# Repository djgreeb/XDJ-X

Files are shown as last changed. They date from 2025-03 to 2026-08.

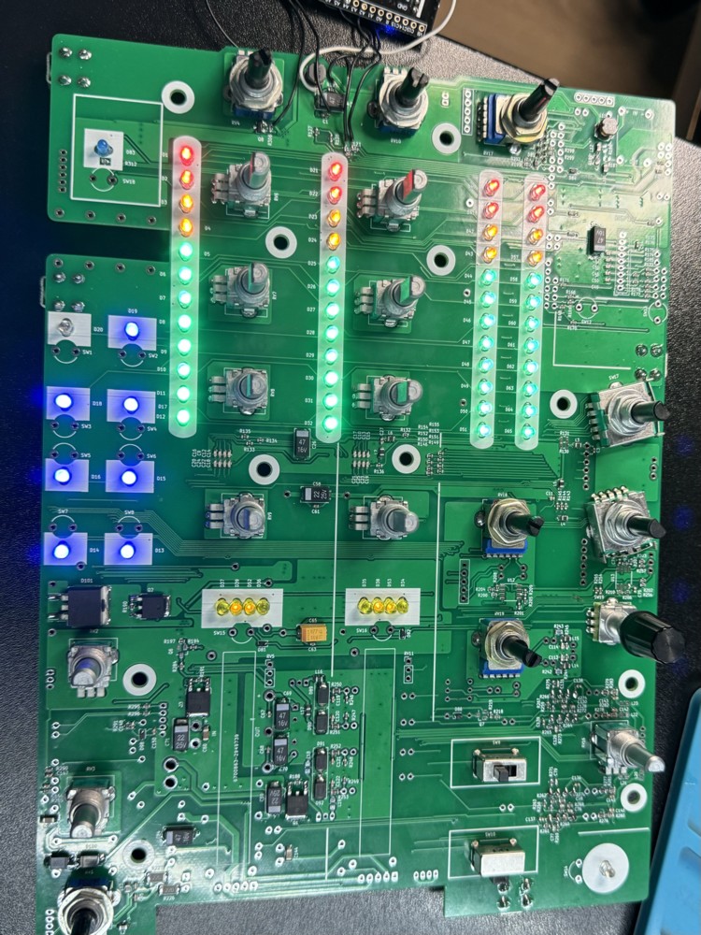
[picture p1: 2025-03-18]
Photo/39.jpg

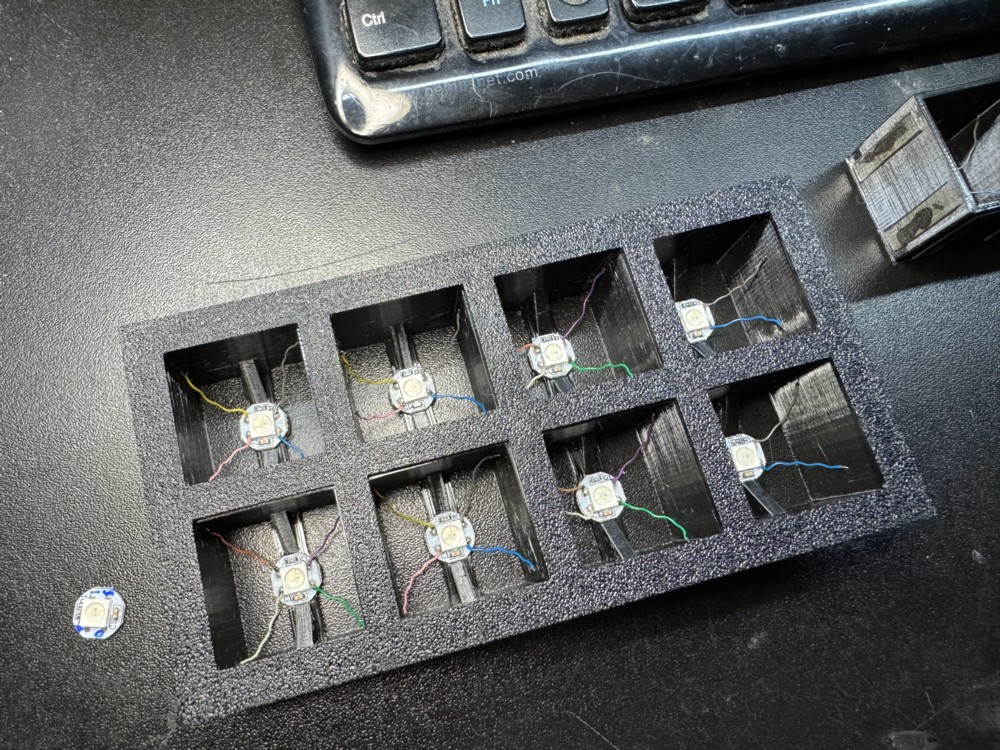
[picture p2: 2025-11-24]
Photo/47.jpg

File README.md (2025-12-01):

# XDJ-X
 All-in-one Dj System

The XDJ-X is an standalone all-in-one DJ system built on the body parts of the CDJ-1000mk3, such as the jog wheel, buttons, and pitch.

The main goal was to create a 2-channel dj setup, compact, without major compromises. Have full-fledged jog wheels, pads, a mixer layer the same as the DJM-900nxs, with an effects display imitating the vacuum display of the classic DJM.

Displays in jogs are specially selected classic VFD, not TFT. These displays have a higher response speed, requiring fewer resources. And this is their main task, when scratching.

The XDJ-X has such advantages as an optical crossfader, a Bluetooth transmitter capable of transmitting a master bus signal or a CUE bus. A built-in battery, the ability to charge the device from a socket or in a car. Built-in speakers (from a MacBook Pro). Support for Rekordbox playlists, wav 16 bits, 44.1 kHz audio files on SD card.

And the most important advantage for me: my source code, scheme, printed circuit board. This will allow adding and testing ideas, algorithms of effects, gui, which in the future will be presented in new models of dj equipment from large companies.

XDJX

xdj-x3



Jog ring

xdj-x 3d

OVERALL BLOCK DIAGRAM

OVERALL BLOCK DIAGRAM

XDJ-X is based on 2 STM32H7 series ARMs, which handle the mixer and deck audio parts. Two STM32F446RET6 microcontrollers handle the buttons and jog wheels in the decks. And STM32G431CBU6 microcontroller handles power, battery charge and standby.

Some videos:

https://youtube.com/shorts/dMu84rqdVfA?si=jUdEivFD7gFBzyvY

https://youtube.com/shorts/kgtJnk3ONWc?si=wLm2IKEQJ5OtroMM

https://youtube.com/shorts/DCkOMFqDp7Y?si=G3mvCeku2s3VxJYp

https://youtube.com/shorts/irT8oiYcfQY?si=mGk5z3SIEAtcrn9f

https://youtube.com/shorts/_BytWdkR8dk?si=etdZMhdHCcjLXZf_

https://youtube.com/shorts/ZKBDyeK_nx4?si=UcPv7-aijNNnzk9v

https://youtube.com/shorts/46_N7XZ1OTQ?si=X-IEIPI7V7By5p8N

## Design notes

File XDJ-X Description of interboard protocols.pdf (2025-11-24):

# XDJ-X

# All-in-one DJ system

# Exchange protocol

# Service commands

Assembly name: | Firmware version:
Display module | 1.06
Mixer assy | 0.42
Deck assy | 0.29
Power manager | 0.27

## Last modified date:

05.06.2025

# Content

1. Exchange protocols | 3
2. Service commands | 5
3. Utility list | 7

# General connection diagram exchange date:

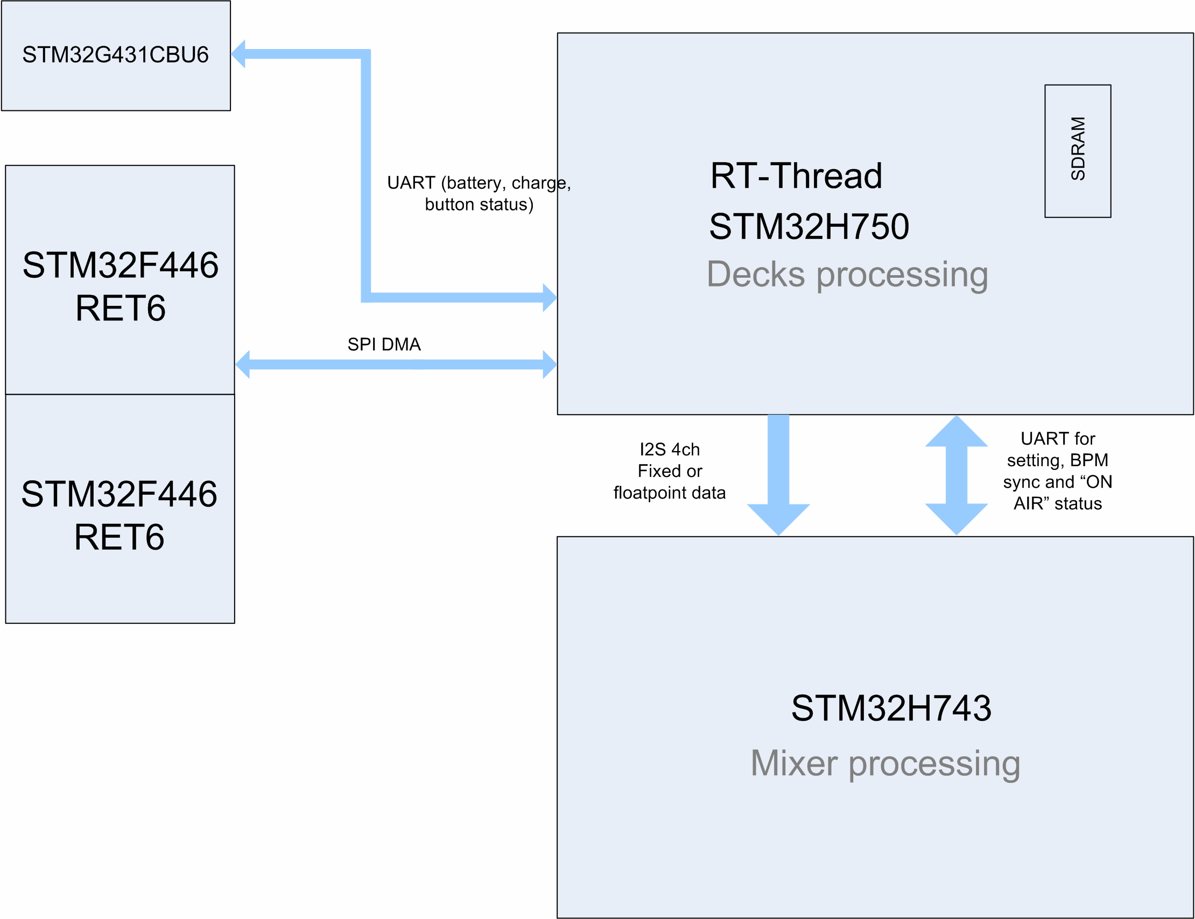
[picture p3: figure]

# 1. Exchange protocols

# Display module <=> Power manager

UART transfer 256000 baud.

## Power manager => Display module:

| 0 | 1 | 2 | 3 | 4 | 5 | 6 | 7 | 8 | 9 | A | B | C | D | E | F
Bytes | 0xAX | | | | | | | | 0xXX
Bits | 1 | 0 | 1 | 0 | 0 | 0 | X | X | X | X | X | X | X | X | X | X

## Byte[0] - status:

## [0xA1] - no AC

## [0xA2] - AC charge

## [0xA3] - full battery

## Byte[1] - data:

## [0xAX][0...100] - charge precentage (when the value changes or on request)

## [0xAX][0xFE] - button pressed

## [0xAX][0xFD] - button unpressed

## [0xAX][0xFC] - shutdown command

## [0xAX][1xxxxxxx] – firmware version

## Display module => Power manager:

| 0 | 1 | 2 | 3 | 4 | 5 | 6 | 7 | 8 | 9 | A | B | C | D | E | F
Bytes | 0xA1 | | | | | | | | 0xXX
Bits | 1 | 0 | 1 | 0 | 0 | 0 | 0 | 1 | X | X | X | X | X | X | X | X

## [0xA1][0x01] - firmware version request

## [0xA1][0x55] - battery percentage request

## [0xA1][0xFC] - shutdown permission

# Display module <=> Mixer Assy

UART transfer 500000 baud.

## Display module => Mixer Assy:

| 0 | 1 | 2 | 3 | 4 | 5 | 6 | 7 | 8 | 9 | A | B | C | D | E | F
Bytes | 0x9X | | | | | | | | 0xXX
Bits | 1 | 0 | 0 | 1 | X | X | X | X | X | X | X | X | X | X | X | X
| 10 | 11 | 12 | 13 | 14 | 15 | 16 | 17
Bytes | 0xXX
Bits | X | X | X | X | X | X | X | X

## [0x91][0x60][0x31] - firmware version request

## [0x92][LOW-MID][MID-HIGH] - setting table values of equalizer cutoff frequencies

## [0x93][0xB1][FDR] - setting fader curve type

## [0x94][0xA3][HDPH] - setting headphones cue type (pre EQ or post EQ)

## [0x95-0x96][BPM][BPM] - sending bpm at beats (BPM*100), 0x95-0x96 – first beat 1/4

## [0x97][0xFC][0xFC] - shutdown command

## Mixer Assy => Display module:

| 0 | 1 | 2 | 3 | 4 | 5 | 6 | 7 | 8 | 9 | A | B | C | D | E | F
Bytes | 0x9X | | | | | | | | 0xXX
Bits | 1 | 0 | 0 | 1 | X | X | X | X | X | X | X | X | X | X | X | X
| 10 | 11 | 12 | 13 | 14 | 15 | 16 | 17
Bytes | 0xXX
Bits | X | X | X | X | X | X | X | X

## [0x91][FW][FW] - firmware version (FW*100)

## [0x97][DECKA][ [DECKB] – on air status

# Display module <=> Deck assy

# SPI DMA transfer

## Deck assy => Display module:

| 00 | 01 | 02 | 03 | 04 | 05 | 06 | 07 | 08 | 09 | 0A | 0B | 0C | 0D | 0E | 0F
Bytes | PADS | | | | | | | | BUTTONS
Bits | PD7 | PD6 | PD5 | PD4 | PD3 | PD2 | PD1 | PD0 | RLP | LP8 | LP4 | VNL | SLIP | REV | CUE | PLAY
| 10 | 11 | 12 | 13 | 14 | 15 | 16 | 17 | 18 | 19 | 1A | 1B | 1C | 1D | 1E | 1F
Bytes | BUTTONS | | | | | | ADC_PITCH (10 bits)
Bits | JSNS | TMP | NXT | PREV | RD | 0 | P | P | P | P | P | P | P | P | P | P
| 20 | 21 | 22 | 23 | 24 | 25 | 26 | 27 | 28 | 29 | 2A | 2B | 2C | 2D | 2E | 2F
Bytes | | | | | | | | | JOG_SPEED_MSB
Bits | DIR | FW | FW | FW | FW | FW | FW | FW | X | X | X | X | X | X | X | X
| 30 | 31 | 32 | 33 | 34 | 35 | 36 | 37 | 38 | 39 | 3A | 3B | 3C | 3D | 3E | 3F
Bytes | JOG_SPEED_LSB | | | | | | | | CRC
Bits | X | X | X | X | X | X | X | X | X | X | X | X | X | X | X | X

## ADC_PITCH 0…1023, 512 – center zone

## RD – rotation detect

## DIR - jog wheel rotation direction

## FW – firmware version in code (0-127)

## JOG_SPEED 0…65535 16 bits resolution (when jog stopped speed = 0xFFFF)

## CRC = (0byte + 1byte +…+6byte)%256

## Display module => Deck assy:

| 00 | 01 | 02 | 03 | 04 | 05 | 06 | 07 | 08 | 09 | 0A | 0B | 0C | 0D | 0E | 0F
Bytes | NUM_P | | | | | | | | PADn_RED
Bits | RNGr | RNGg | RNGb | LD1 | LD0 | nP | nP | nP | R | R | R | R | R | R | R | R
| 10 | 11 | 12 | 13 | 14 | 15 | 16 | 17 | 18 | 19 | 1A | 1B | 1C | 1D | 1E | 1F
Bytes | PADn_GREEN | | | | | | | | PADn_BLUE
Bits | G | G | G | G | G | G | G | G | B | B | B | B | B | B | B | B
| 20 | 21 | 22 | 23 | 24 | 25 | 26 | 27 | 28 | 29 | 2A | 2B | 2C | 2D | 2E | 2F
Bytes | PLAY_POS | | | | | | | | SLIP_POS
Bits | X | X | X | X | X | X | X | X | 0 | X | X | X | X | X | X | X
| 30 | 31 | 32 | 33 | 34 | 35 | 36 | 37 | 38 | 39 | 3A | 3B | 3C | 3D | 3E | 3F
Bytes | CUE_POS | | | | | | | | CRC
Bits | 0 | X | X | X | X | X | X | X | X | X | X | X | X | X | X | X
nP | LD1 | LD0
0 | CUE | PLAY
1 | SLIP | REV
2 | LP4 | VNL
3 | RLP | LP8
4 | TMP | VNLr

5 | SNSr | MEMr
6 | 0 | 0
7 | 0 | 0

## nP - package number and at the same time pad number PADn_(RED, GREEN, BLUE) RGB 888 color for PAD[NUM_P] RNGr, RNGg, RNGb – RGB bits <<[NUM_P] MEMr, SNSr, VNLr – VFD segments SLIP_POS 0…84. 85 – SLIP disable CUE_POS 0…84. 85 – CUE without cue on jog display

PLAY_POS 0…134 – jog display position cursor 139 = power on animation 138 = eject animation 137 = load in animation 136 = fill circle on display 135 = empty circle.

## CRC = (0byte + 1byte +…+6byte)%256

# 2. Service commands

# 3. Utility list

Name: | Array location | EEPROM addr | Parameter list
DECKS
PLAY MODE | [0] | 0x0000 | SINGLE
CONTINUE
LOAD LOCK | [1] | 0x0001 | LOCK
| | | UNLOCK
| | | -36dB
| | | -42dB
| | | -48dB
| | | -54dB
| | | -60dB
| | | -66dB
| | | -72dB
| | | -78dB
| | | MEMORY
AUTO CUE MODE | [2] | 0x0002

FIRST BEAT
QUANTIZE | [3] | 0x0003 | OFF
| | | ON
| | | 6%
| | | 10%
| | | 16%
TEMPO RANGE DEFAULT | [4] | 0x0004

WIDE
COLOR WAVEFORM | [5] | 0x0005 | BLUE
| | | RGB
WAVEFORM POSITION | [6] | 0x0006 | CENTER LINE
| | | LEFT LINE
VINYL START | [7] | 0x0007 | 0-128
VINYL BRAKE | [8] | 0x0008 | 0-128
JOG ON AIR | [9] | 0x0009 | OFF
ON
WHITE
PINK
RED
JOG COLOR ON AIR | [10] | 0x000A

ORANGE

YELLOW
GREEN
AQUA
BLUE
PURPLE
TRACK COLOR
WHITE
PINK
RED
ORANGE
YELLOW
GREEN
AQUA
BLUE
PURPLE
JOG COLOR INACTIVE | [11] | 0x000B

TRACK COLOR
JOG BRIGHTNESS | [12] | 0x000C | 1
| | | 2
| | | 1
| | | 2
| | | 3
| | | 4
LCD BRIGHTNESS | [13] | 0x000D

5
PADS MODE | [14] | 0x000E | NORMAL
| | | GATE

MIXER
FADER CURVE | [15] | 0x000F | LINEAR
SLOW
SPEAKERS | - | OFF
| | ON
EQ frequency LOW-MID | [16] | 0x0010
EQ frequency MID -HIGH | [17] | 0x0011
HEADPHONES CUE | [18] | 0x0012 | PRE EQ
POST EQ

GENERAL
BATT. INFO | -

VERSION No.
DECK 1 | - | 0.29
DECK 2 | - | 0.29
MAIN ASSY | - | 1.03

MIXER ASSY | | 0.41
POWER MANAGER | - | 0.27
DEVELOPER | - | ANATSKA ANDREI

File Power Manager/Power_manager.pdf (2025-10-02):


03/06/2025

Power_manager Project
Configuration Report

## 1. Description

### 1.1. Project

Project Name | Power_manager
Board Name | custom
Generated with: | STM32CubeMX 6.10.0
Date | 06/03/2025

### 1.2. MCU

MCU Series | STM32G4
MCU Line | STM32G4x1
MCU name | STM32G431CBUx
MCU Package | UFQFPN48
MCU Pin number | 48

### 1.3. Core(s) information

Core(s) | ARM Cortex-M4

## 2. Pinout Configuration

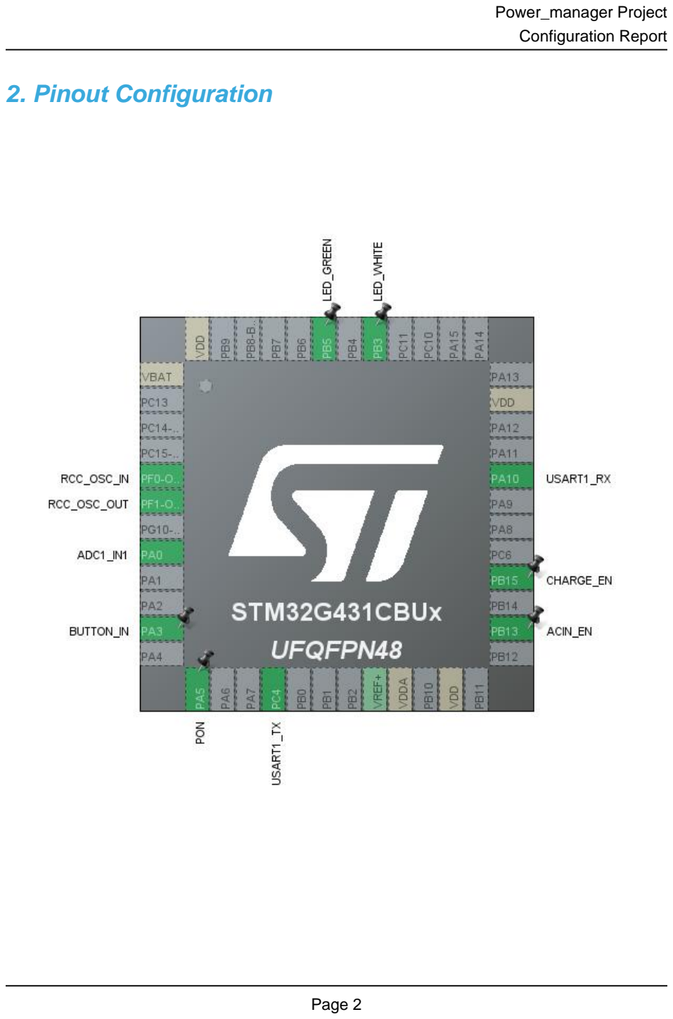
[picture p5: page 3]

## 3. Pins Configuration

Pin Number UFQFPN48 | Pin Name (function after reset) | Pin Type | Alternate Function(s) | Label
1 | VBAT | Power
5 | PF0-OSC_IN | I/O | RCC_OSC_IN
6 | PF1-OSC_OUT | I/O | RCC_OSC_OUT
8 | PA0 | I/O | ADC1_IN1
11 | PA3 * | I/O | GPIO_Input | BUTTON_IN
13 | PA5 * | I/O | GPIO_Output | PON
16 | PC4 | I/O | USART1_TX
21 | VDDA | Power
23 | VDD | Power
26 | PB13 * | I/O | GPIO_Input | ACIN_EN
28 | PB15 * | I/O | GPIO_Input | CHARGE_EN
32 | PA10 | I/O | USART1_RX
35 | VDD | Power
41 | PB3 * | I/O | GPIO_Output | LED_WHITE
43 | PB5 * | I/O | GPIO_Output | LED_GREEN
48 | VDD | Power

* The pin is affected with an I/O function

## 4. Clock Tree Configuration

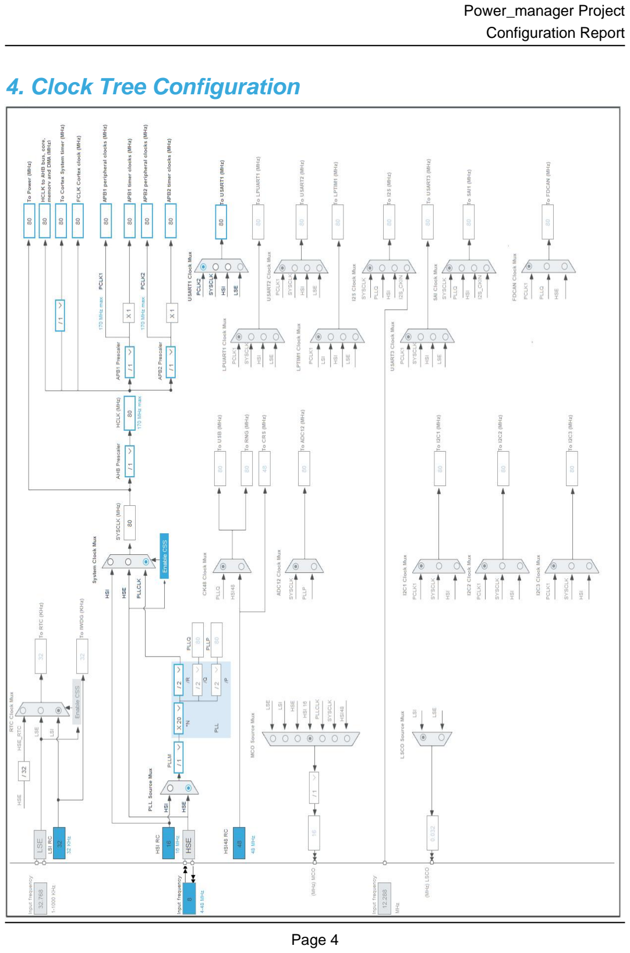
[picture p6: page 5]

## 5. Software Project

### 5.1. Project Settings

Name | Value
Project Name | Power_manager
Project Folder | C:\Keil_v5\My_Project\Power_manager
Toolchain / IDE | MDK-ARM V5.32
Firmware Package Name and Version | STM32Cube FW_G4 V1.5.1
Application Structure | Basic
Generate Under Root | No
Do not generate the main() | No
Minimum Heap Size | 0x200
Minimum Stack Size | 0x400

### 5.2. Code Generation Settings

Name | Value
STM32Cube MCU packages and embedded software | Copy all used libraries into the project folder
Generate peripheral initialization as a pair of '.c/.h' files | Yes
Backup previously generated files when re-generating | No
Keep User Code when re-generating | Yes
Delete previously generated files when not re-generated | Yes
Set all free pins as analog (to optimize the power consumption) | No
Enable Full Assert | No

### 5.3. Advanced Settings - Generated Function Calls

Rank | Function Name | Peripheral Instance Name
1 | SystemClock_Config | RCC
2 | MX_GPIO_Init | GPIO
3 | MX_ADC1_Init | ADC1
4 | MX_USART1_UART_Init | USART1

## 1. Power Consumption Calculator report

### 1.1. Microcontroller Selection

Series | STM32G4
Line | STM32G4x1
MCU | STM32G431CBUx
Datasheet | DS12589_Rev0

### 1.2. Parameter Selection

Temperature | 25
Vdd | 3.0

### 1.3. Battery Selection

Battery | Li-SOCL2(A3400)
Capacity | 3400.0 mAh
Self Discharge | 0.08 %/month
Nominal Voltage | 3.6 V
Max Cont Current | 100.0 mA
Max Pulse Current | 200.0 mA
Cells in series | 1
Cells in parallel | 1

### 1.4. Sequence

Step | Step1 | Step2
Mode | RUN | STOP1
Vdd | 3.0 | 3.0
Voltage Source | Battery | Battery
Range | Range1-Boost | NoRange
Fetch Type | FLASH/ART | NA
CPU Frequency | 170 MHz | 0 Hz
Clock Configuration | HSE BYP PLL | ALL CLOCKS OFF
Clock Source Frequency | 4 MHz | 0 Hz
Peripherals
Additional Cons. | 0 mA | 0 mA
Average Current | 25.5 mA | 59 µA
Duration | 0.1 ms | 0.9 ms
DMIPS | 213.0 | 0.0
Ta Max | 127.71 | 129.99
Category | In DS Table | In DS Table

### 1.5. Results

Sequence Time | 1 ms | Average Current | 2.6 mA
Battery Life | 1 month, 23 days, 22 hours | Average DMIPS | 212.5 DMIPS

### 1.6. Chart

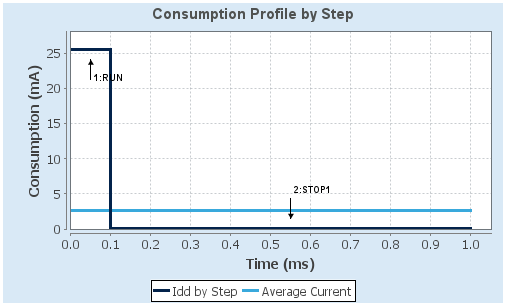
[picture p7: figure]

## 2. Peripherals and Middlewares Configuration

### 2.1. ADC1

IN1: IN1 Single-ended
2.1.1. Parameter Settings:

ADCs_Common_Settings:

Mode | Independent mode
ADC_Settings:
Clock Prescaler | Synchronous clock mode divided by 2
Resolution | ADC 12-bit resolution
Data Alignment | Right alignment
Gain Compensation | 0
Scan Conversion Mode | Disabled
End Of Conversion Selection | End of single conversion
Low Power Auto Wait | Disabled
Continuous Conversion Mode | Disabled
Discontinuous Conversion Mode | Disabled
DMA Continuous Requests | Disabled
Overrun behaviour | Overrun data preserved
ADC_Regular_ConversionMode:
Enable Regular Conversions | Enable
Enable Regular Oversampling | Disable
Number Of Conversion | 1
External Trigger Conversion Source | Regular Conversion launched by software
External Trigger Conversion Edge | None
Rank | 1
Channel | Channel 1
Sampling Time | 2.5 Cycles
Offset Number | No offset
ADC_Injected_ConversionMode:
Enable Injected Conversions | Disable
Analog Watchdog 1:
Enable Analog WatchDog1 Mode | false
Analog Watchdog 2:
Enable Analog WatchDog2 Mode | false
Analog Watchdog 3:
Enable Analog WatchDog3 Mode | false

### 2.2. RCC

High Speed Clock (HSE): Crystal/Ceramic Resonator
2.2.1. Parameter Settings:

System Parameters:

VDD voltage (V) | 3.3
Instruction Cache | Enabled
Prefetch Buffer | Disabled
Data Cache | Enabled
Flash Latency(WS) | 2 WS (3 CPU cycle)
RCC Parameters:
HSI Calibration Value | 64
HSE Startup Timout Value (ms) | 100
LSE Startup Timout Value (ms) | 5000
Power Parameters:
Power Regulator Voltage Scale | Power Regulator Voltage Scale 1
Peripherals Clock Configuration:
Generate the peripherals clock configuration | TRUE

### 2.3. SYS

Timebase Source: SysTick
mode: save power of non-active UCPD - deactive Dead Battery pull-up

### 2.4. USART1

Mode: Asynchronous
2.4.1. Parameter Settings:

Basic Parameters:

Baud Rate | 256000 *
Word Length | 8 Bits (including Parity)
Parity | None
Stop Bits | 1
Advanced Parameters:
Data Direction | Receive and Transmit
Over Sampling | 16 Samples
Single Sample | Disable
ClockPrescaler | 1

Fifo Mode | Disable
Txfifo Threshold | 1 eighth full configuration
Rxfifo Threshold | 1 eighth full configuration
Advanced Features:
Auto Baudrate | Disable
TX Pin Active Level Inversion | Disable
RX Pin Active Level Inversion | Disable
Data Inversion | Disable
TX and RX Pins Swapping | Disable
Overrun | Enable
DMA on RX Error | Enable
MSB First | Disable

* User modified value

## 3. System Configuration

### 3.1. GPIO configuration

IP | Pin | Signal | GPIO mode | GPIO pull/up pull down | Max Speed | User Label
ADC1 | PA0 | ADC1_IN1 | Analog mode | No pull-up and no pull-down | n/a
RCC | PF0-OSC_IN | RCC_OSC_IN | n/a | n/a | n/a
| PF1-OSC_OUT | RCC_OSC_OUT | n/a | n/a | n/a
USART1 | PC4 | USART1_TX | Alternate Function Push Pull | No pull-up and no pull-down | Low
| PA10 | USART1_RX | Alternate Function Push Pull | No pull-up and no pull-down | Low
GPIO | PA3 | GPIO_Input | Input mode | Pull-up * | n/a | BUTTON_IN
| PA5 | GPIO_Output | Output Push Pull | No pull-up and no pull-down | Medium * | PON
| PB13 | GPIO_Input | Input mode | No pull-up and no pull-down | n/a | ACIN_EN
| PB15 | GPIO_Input | Input mode | No pull-up and no pull-down | n/a | CHARGE_EN
| PB3 | GPIO_Output | Output Push Pull | No pull-up and no pull-down | High * | LED_WHITE
| PB5 | GPIO_Output | Output Push Pull | No pull-up and no pull-down | High * | LED_GREEN

### 3.2. DMA configuration

nothing configured in DMA service

### 3.3. NVIC configuration

3.3.1. NVIC
Interrupt Table | Enable | Preenmption Priority | SubPriority
Non maskable interrupt | true | 0 | 0
Hard fault interrupt | true | 0 | 0
Memory management fault | true | 0 | 0
Prefetch fault, memory access fault | true | 0 | 0
Undefined instruction or illegal state | true | 0 | 0
System service call via SWI instruction | true | 0 | 0
Debug monitor | true | 0 | 0
Pendable request for system service | true | 0 | 0
System tick timer | true | 15 | 0
USART1 global interrupt / USART1 wake-up interrupt through EXTI line 25 | true | 1 | 0
PVD/PVM1/PVM2/PVM3/PVM4 interrupts through EXTI lines 16/38/39/40/41 | unused
Flash global interrupt | unused
RCC global interrupt | unused
ADC1 and ADC2 global interrupt | unused
FPU global interrupt | unused
3.3.2. NVIC Code generation
Enabled interrupt Table | Select for init sequence ordering | Generate IRQ handler | Call HAL handler
Non maskable interrupt | false | true | false
Hard fault interrupt | false | true | false
Memory management fault | false | true | false
Prefetch fault, memory access fault | false | true | false
Undefined instruction or illegal state | false | true | false
System service call via SWI instruction | false | true | false
Debug monitor | false | true | false
Pendable request for system service | false | true | false
System tick timer | false | true | true
USART1 global interrupt / USART1 wake-up interrupt through EXTI line 25 | false | true | true

* User modified value

## 4. System Views

4.1. Category view
4.1.1. Current

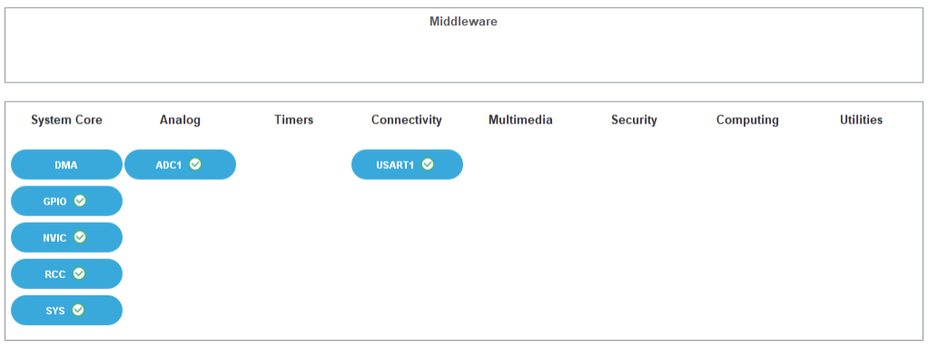
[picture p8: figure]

## 5. Docs & Resources

Type | Link
BSDL files | https://www.st.com/resource/en/bsdl_model/stm32g4_bsdl.zip
IBIS models | https://www.st.com/resource/en/ibis_model/stm32g4_ibis.zip
System View Description | https://www.st.com/resource/en/svd/stm32g4_svd.zip
Presentations | https://www.st.com/resource/en/product_presentation/stm32-stm8_embedded_software_solutions.pdf
Presentations | https://www.st.com/resource/en/product_presentation/stm32_eval-tools_portfolio.pdf
Presentations | https://www.st.com/resource/en/product_presentation/stm32_stm8_functi onal-safety-packages.pdf
Presentations | https://www.st.com/resource/en/product_presentation/stm32-usb-c-pd-solutions-presentation.pdf
Presentations | https://www.st.com/resource/en/product_presentation/stm32-stm8_software_development_tools.pdf
Presentations | https://www.st.com/resource/en/product_presentation/microcontrollers-stm32-family-overview.pdf
Presentations | https://www.st.com/resource/en/product_presentation/microcontrollers-stm32g4-series-product-overview.pdf
Brochures | https://www.st.com/resource/en/brochure/products-and-solutions-for-plcs-and-smart-i-os.pdf
Flyers | https://www.st.com/resource/en/flyer/flstm32g4.pdf
Flyers | https://www.st.com/resource/en/flyer/flstm32nucleo.pdf
Flyers | https://www.st.com/resource/en/flyer/flstm32trust.pdf
Flyers | https://www.st.com/resource/en/flyer/fldpstpfc11120.pdf
Application Notes | https://www.st.com/resource/en/application_note/an1709-emc-design-guide-for-stm8-stm32-and-legacy-mcus-stmicroelectronics.pdf
Application Notes | https://www.st.com/resource/en/application_note/an2606-stm32-microcontroller-system-memory-boot-mode-stmicroelectronics.pdf
Application Notes | https://www.st.com/resource/en/application_note/an3126-audio-and-

| waveform-generation-using-the-dac-in-stm32-products-stmicroelectronics.pdf
Application Notes | https://www.st.com/resource/en/application_note/an3155-usart-protocol-used-in-the-stm32-bootloader-stmicroelectronics.pdf
Application Notes | https://www.st.com/resource/en/application_note/an3156-usb-dfu-protocol-used-in-the-stm32-bootloader-stmicroelectronics.pdf
Application Notes | https://www.st.com/resource/en/application_note/an4221-i2c-protocol-used-in-the-stm32-bootloader-stmicroelectronics.pdf
Application Notes | https://www.st.com/resource/en/application_note/an4232-getting-started-with-analog-comparators-for-stm32f3-series-and-stm32g4-series-devices-stmicroelectronics.pdf
Application Notes | https://www.st.com/resource/en/application_note/an4286-spi-protocol-used-in-the-stm32-bootloader-stmicroelectronics.pdf
Application Notes | https://www.st.com/resource/en/application_note/an4296-use-stm32f3stm32g4-ccm-sram-with-iar-embedded-workbench-keil-mdkarm-stmicroelectronics-stm32cubeide-and-other-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
Application Notes | https://www.st.com/resource/en/application_note/an4566-extending-the-dac-performance-of-stm32-microcontrollers-stmicroelectronics.pdf
Application Notes | https://www.st.com/resource/en/application_note/an4655-virtually-increasing-the-number-of-serial-communication-peripherals-in-stm32-applications-stmicroelectronics.p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
Application Notes | https://www.st.com/resource/en/application_note/an4750-handling-of-soft-errors-in-stm32-applications-stmicroelectronics.pdf
Application Notes | https://www.st.com/resource/en/application_note/an4776-generalpurpose-timer-cookbook-for-stm32-microcontrollers-stmicroelectronics.pdf
Application Notes | https://www.st.com/resource/en/application_note/an4803-highspeed-si-simulations-using-ibis-and-boardlevel-simulations-using-hyperlynx-si-on-stm32-mcus-and-mpus-stmic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
Application Notes | https://www.st.com/resource/en/application_note/an4989-stm32-microcontroller-debug-toolbox-stmicroelectronics.pdf
Application Notes | https://www.st.com/resource/en/application_note/an5027-interfacing-pdm-digital-microphones-using-stm32-mcus-and-mpus-stmicroelectronics.pdf

Application Notes | https://www.st.com/resource/en/application_note/an5093-getting-started-with-stm32g4-series--hardware-development-boards-stmicroelectronics.pdf
Application Notes | https://www.st.com/resource/en/application_note/an5306-operational-amplifier-opamp-usage-in-stm32g4-series-stmicroelectronics.pdf
Application Notes | https://www.st.com/resource/en/application_note/an5310-guideline-for-using-analog-features-of-stm32g4-series-versus-stm32f3-series-devices-stmicroelectronics.pdf
Application Notes | https://www.st.com/resource/en/application_note/an5315-stm32cube-firmware-examples-for-stm32g4-series-stmicroelectronics.pdf
Application Notes | https://www.st.com/resource/en/application_note/an5346-stm32g4-adc-use-tips-and-recommendations-stmicroelectronics.pdf
Application Notes | https://www.st.com/resource/en/application_note/an5094-migrating-between-stm32f334303-lines-and-stm32g431xxg474xxg491xx-microcontrollers-stmicroelectronics.pdf
Application Notes | https://www.st.com/resource/en/application_note/an5738-stm32g4-series-lifetime-estimates-stmicroelectronics.pdf
Application Notes | https://www.st.com/resource/en/application_note/an4899-stm32-microcontroller-gpio-hardware-settings-and-lowpower-consumption-stmicroelectronics.pdf
Application Notes | https://www.st.com/resource/en/application_note/an5612-esd-protection-of-stm32-mcus-and-mpus-stmicroelectronics.pdf
Application Notes | https://www.st.com/resource/en/application_note/an4991-how-to-wake-up-an-stm32-microcontroller-from-lowpower-mode-with-the-usart-or-the-lpuart-stmicroelectronics.pdf
Application Notes | https://www.st.com/resource/en/application_note/an4838-introduction-to-memory-protection-unit-management-on-stm32-mcus-stmicroelectronics.pdf
Application Notes | https://www.st.com/resource/en/application_note/an5325-how-to-use-the-cordic-to-perform-mathematical-functions-on-stm32-mcus-stmicroelectronics.pdf
Application Notes | https://www.st.com/resource/en/application_note/an5225-introduction-to-usb-typec-power-delivery-for-stm32-mcus-and-mpus-stmicroelectronics.pdf

Application Notes | https://www.st.com/resource/en/application_note/an4894-how-to-use-eeprom-emulation-on-stm32-mcus-stmicroelectronics.pdf
Application Notes | https://www.st.com/resource/en/application_note/an5537-how-to-use-adc-oversampling-techniques-to-improve-signaltonoise-ratio-on-stm32-mcus-stmicroelectronics.pdf
Application Notes | https://www.st.com/resource/en/application_note/an5036-guidelines-for-thermal-management-on-stm32-applications-stmicroelectronics.pdf
Application Notes | https://www.st.com/resource/en/application_note/an5405-how-to-use-fdcan-bootloader-protocol-on-stm32-mcus-stmicroelectronics.pdf
Application Notes | https://www.st.com/resource/en/application_note/an5978-introduction-to-mb1971-llc-hat-12-v-to-75-v1-a-for-f334-g474-nucleo-board-stmicroelectronics.pdf
Application Notes | https://www.st.com/resource/en/application_note/an5690-how-to-use-vrefbuf-peripheral-on-stm32-mcus-and-mpus-stmicroelectronics.pdf
Application Notes | https://www.st.com/resource/en/application_note/an4230-introduction-to-random-number-generation-validation-using-the-nist-statistical-test-suite-for-stm32-mcus-and-m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
Application Notes | https://www.st.com/resource/en/application_note/an2548-introduction-to-dma-controller-for-stm32-mcus-stmicroelectronics.pdf
Application Notes | https://www.st.com/resource/en/application_note/an4013-introduction-to-timers-for-stm32-mcus-stmicroelectronics.pdf
Application Notes | https://www.st.com/resource/en/application_note/an4277-how-to-use-pwm-shutdown-for-motor-control-and-digital-power-conversion-on-stm32-mcus-stmicroelectronics.pdf
Application Notes | https://www.st.com/resource/en/application_note/an4635-how-to-optimize-lpuart-power-consumption-on-stm32-mcus-stmicroelectronics.pdf
Application Notes | https://www.st.com/resource/en/application_note/an4759-introduction-to-using-the-hardware-realtime-clock-rtc-and-the-tamper-management-unit-tamp-with-stm32-mcus-stmi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
Application Notes | https://www.st.com/resource/en/application_note/an4908-getting-started-with-usart-automatic-baud-rater-detection-for-stm32-mcus-stmicroelectronics.pdf

Application Notes | https://www.st.com/resource/en/application_note/an5156-introduction-to-security-for-stm32-mcus-stmicroelectronics.pdf
Application Notes | https://www.st.com/resource/en/application_note/an5224-introduction-to-dmamux-for-stm32-mcus-stmicroelectronics.pdf
Application Notes | https://www.st.com/resource/en/application_note/an5543-guidelines-for-enhanced-spi-communication-on-stm32-mcus-and-mpus-stmicroelectronics.pdf
Application Notes | https://www.st.com/resource/en/application_note/an5348-introduction-to-fdcan-peripherals-for-stm32-mcus-stmicroelectronics.pdf
Application Notes | https://www.st.com/resource/en/application_note/cd00211314-how-to-optimize-the-adc-accuracy-in-the-stm32-mcus-stmicroelectronics.pdf
Application Notes | https://www.st.com/resource/en/application_note/an2639-soldering-recommendations-and-package-information-for-leadfree-ecopack2-mcus-and-mpus-stmicroelectronics.pdf
Application Notes for related Tools & Software | https://www.st.com/resource/en/application_note/an4435-guidelines-for-obtaining-ulcsaiec-607301603351-class-b-certification-in-any-stm32-application-stmicroelectroni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
Application Notes for related Tools & Software | https://www.st.com/resource/en/application_note/an4657-stm32-inapplication-programming-iap-using-the-usart-stmicroelectronics.pdf
Application Notes for related Tools & Software | https://www.st.com/resource/en/application_note/an4841-digital-signal-processing-for-stm32-microcontrollers-using-cmsis-stmicroelectronics.pdf
Application Notes for related Tools & Software | https://www.st.com/resource/en/application_note/an5056-integration-guide-for-the-xcubesbsfu-stm32cube-expansion-package-stmicroelectronics.pdf
Application Notes for related Tools & Software | https://www.st.com/resource/en/application_note/an5305-digital-filter-implementation-with-the-fmac-using-stm32cubeg4-mcu-package-stmicroelectronics.pdf
Application Notes for related Tools & Software | https://www.st.com/resource/en/application_note/an5315-stm32cube-firmware-examples-for-stm32g4-series-stmicroelectronics.pdf

Application Notes
for related Tools

https://www.st.com/resource/en/application_note/an5345-highbrightnessrgb-led-control-using-the-bg474edpow1-discovery-kit-

& Software | stmicroelectronics.pdf
Application Notes for related Tools & Software | https://www.st.com/resource/en/application_note/an5360-getting-started-with-projects-based-on-the-stm32mp1-series-in-stm32cubeide-stmicroelectronics.pdf
Application Notes for related Tools & Software | https://www.st.com/resource/en/application_note/an5361-getting-started-with-projects-based-on-dualcore-stm32h7-microcontrollers-in-stm32cubeide-stmicroelectronics.pd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
Application Notes for related Tools & Software | https://www.st.com/resource/en/application_note/an5394-getting-started-with-projects-based-on-the-stm32l5-series-in-stm32cubeide-stmicroelectronics.pdf
Application Notes for related Tools & Software | https://www.st.com/resource/en/application_note/an5418-how-to-build-a-simple-usbpd-sink-application-with-stm32cubemx-stmicroelectronics.pdf
Application Notes for related Tools & Software | https://www.st.com/resource/en/application_note/an5426-migrating-graphics-middleware-projects-from-stm32cubemx-540-to-stm32cubemx-550-stmicroelectronics.pdf
Application Notes for related Tools & Software | https://www.st.com/resource/en/application_note/an5464-position-control-of-a-threephase-permanent-magnet-motor-using-xcubemcsdk-or-xcubemcsdkful-stmicroelectronics.p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
Application Notes for related Tools & Software | https://www.st.com/resource/en/application_note/an5564-getting-started-with-projects-based-on-dualcore-stm32wl-microcontrollers-in-stm32cubeide-stmicroelectronics.pd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
Application Notes for related Tools & Software | https://www.st.com/resource/en/application_note/an5698-adapting-the-xcubestl-functional-safety-package-for-stm32-iec-61508-compliant-to-other-safety-standards-stmicr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
Application Notes for related Tools & Software | https://www.st.com/resource/en/application_note/an5731-stm32cubemx-and-stm32cubeide-threadsafe-solution-stmicroelectronics.pdf
Application Notes for related Tools & Software | https://www.st.com/resource/en/application_note/an5785-boost-voltage-mode-on-bg474edpow1-discovery-kit-stmicroelectronics.pdf
Application Notes for related Tools & Software | https://www.st.com/resource/en/application_note/an5788-stm32-digital-power-pid-and-iir-filters-for-smps-control-design-and-comparison-on-bg414edpow1-discovery-kit-st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

Application Notes for related Tools & Software | https://www.st.com/resource/en/application_note/an4502-stm32-smbuspmbus-expansion-package-for-stm32cube-stmicroelectronics.pdf
Application Notes for related Tools & Software | https://www.st.com/resource/en/application_note/an5952-how-to-use-cmake-in-stm32cubeide-stmicroelectronics.pdf
Application Notes for related Tools & Software | https://www.st.com/resource/en/application_note/an4635-how-to-optimize-lpuart-power-consumption-on-stm32-mcus-stmicroelectronics.pdf
Application Notes for related Tools & Software | https://www.st.com/resource/en/application_note/an5054-how-to-perform-secure-programming-using-stm32cubeprogrammer-stmicroelectronics.pdf
Application Notes for related Tools & Software | https://www.st.com/resource/en/application_note/an5496-guidelines-for-the-buck-voltage-mode-on-the-bg474edpow1-discovery-kit-stmicroelectronics.pdf
Application Notes for related Tools & Software | https://www.st.com/resource/en/application_note/an5497-introduction-to-the-buck-current-mode-with-the-bg474edpow1-discovery-kit-stmicroelectronics.pdf
Application Notes for related Tools & Software | https://www.st.com/resource/en/application_note/an6179-how-to-integrate-the-stl-firmware-into-a-time-critical-user-application-stmicroelectronics.pdf
Errata Sheets | https://www.st.com/resource/en/errata_sheet/es0431-stm32g431xx441xx-device-errata-stmicroelectronics.pdf
Datasheet | https://www.st.com/resource/en/datasheet/dm00507199.pdf
Programming Manuals | https://www.st.com/resource/en/programming_manual/pm0214-stm32-cortexm4-mcus-and-mpus-programming-manual-stmicroelectronics.pdf
Reference Manuals | https://www.st.com/resource/en/reference_manual/rm0440-stm32g4-series-advanced-armbased-32bit-mcus-stmicroelectronics.pdf
Technical Notes & Articles | https://www.st.com/resource/en/technical_note/tn1163-description-of-wlcsp-for-microcontrollers-and-recommendations-for-its-use-stmicroelectronics.pdf
Technical Notes & Articles | https://www.st.com/resource/en/technical_note/tn1204-tape-and-reel-shipping-media-for-stm32-microcontrollers-in-bga-packages-stmicroelectronics.pdf

Technical Notes & Articles | https://www.st.com/resource/en/technical_note/tn1205-tape-and-reel-shipping-media-for-stm8-and-stm32-microcontrollers-in-fpn-packages-stmicroelectronics.pdf
Technical Notes & Articles | https://www.st.com/resource/en/technical_note/tn1206-tape-and-reel-shipping-media-for-stm8-and-stm32-microcontrollers-in-qfp-packages-stmicroelectronics.pdf
Technical Notes & Articles | https://www.st.com/resource/en/technical_note/tn1207-tape-and-reel-shipping-media-for-stm8-and-stm32-microcontrollers-in-so-packages-stmicroelectronics.pdf
Technical Notes & Articles | https://www.st.com/resource/en/technical_note/tn1208-tape-and-reel-shipping-media-for-stm8-and-stm32-microcontrollers-in-tssop-and-ssop-packages-stmicroelectronics.p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
Technical Notes & Articles | https://www.st.com/resource/en/technical_note/tn1433-reference-device-marking-schematics-for-stm32-microcontrollers-and-microprocessors-stmicroelectronics.pdf
Technical Notes & Articles | https://www.st.com/resource/en/technical_note/tn1489-security-bulletin-tn1489stpsirt-physical-attacks-on-stm32-and-stm32cube-firmware-stmicroelectronics.pdf
User Manuals | https://www.st.com/resource/en/user_manual/um3167-stm32g4-series-ulcsaiec-607301603351-selftest-library-user-guide-stmicroelectronics.pdf

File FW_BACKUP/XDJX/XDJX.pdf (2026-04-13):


08/01/2026

## XDJX Project Configuration Report

# 1. Description

## 1.1. Project

Project Name | XDJX
Board Name | custom
Generated with: | STM32CubeMX 6.10.0
Date | 01/08/2026

## 1.2. MCU

MCU Series | STM32H7
MCU Line | STM32H743/753
MCU name | STM32H743XIHx
MCU Package | TFBGA240
MCU Pin number | 265

## 1.3. Core(s) information

Core(s) | ARM Cortex-M7

# 2. Pinout Configuration

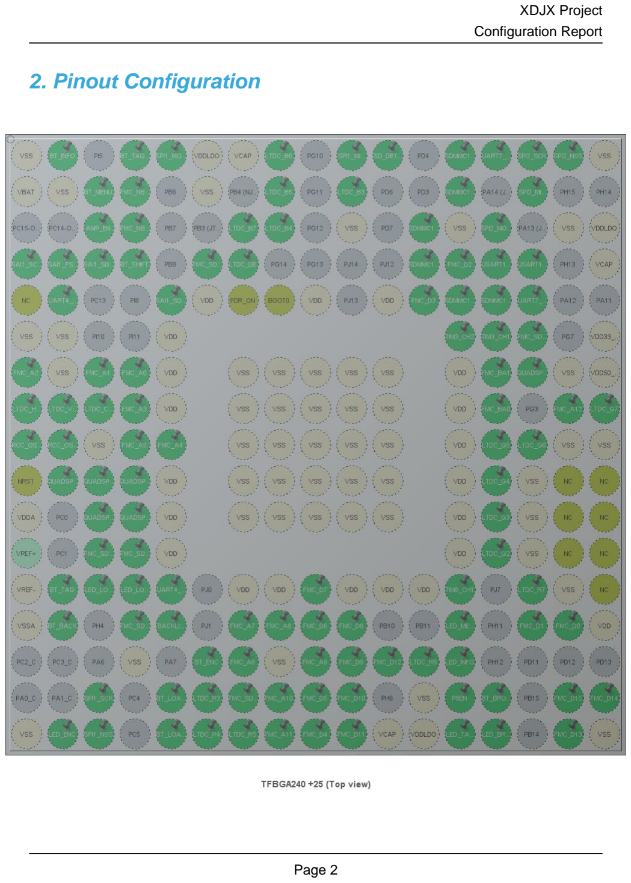
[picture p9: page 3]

# 3. Pins Configuration

Pin Number TFBGA240 | Pin Name (function after reset) | Pin Type | Alternate Function(s) | Label
A1 | VSS | Power
A2 | PI6 * | I/O | GPIO_Input | BT_INFO
A4 | PI4 * | I/O | GPIO_Input | BT_TAGLIST
A5 | PB5 | I/O | SPI1_MOSI
A6 | VDDLDO | Power
A7 | VCAP | Power
A8 | PK5 | I/O | LTDC_B6
A10 | PG9 | I/O | SPI1_MISO
A11 | PD5 * | I/O | GPIO_Input | SD_DETECT
A13 | PC10 | I/O | SDMMC1_D2
A14 | PA15 (JTDI) | I/O | UART7_TX
A15 | PI1 | I/O | SPI2_SCK
A16 | PI0 | I/O | SPI2_NSS
A17 | VSS | Power
B1 | VBAT | Power
B2 | VSS | Power
B3 | PI7 * | I/O | GPIO_Input | BT_MENU
B4 | PE1 | I/O | FMC_NBL1
B6 | VSS | Power
B8 | PK4 | I/O | LTDC_B5
B10 | PJ15 | I/O | LTDC_B3
B13 | PC11 | I/O | SDMMC1_D3
B15 | PI2 | I/O | SPI2_MISO
C3 | PE2 * | I/O | GPIO_Output | AMP_EN
C4 | PE0 | I/O | FMC_NBL0
C7 | PK6 | I/O | LTDC_B7
C8 | PK3 | I/O | LTDC_B4
C10 | VSS | Power
C12 | PC12 | I/O | SDMMC1_CK
C13 | VSS | Power
C14 | PI3 | I/O | SPI2_MOSI
C16 | VSS | Power
C17 | VDDLDO | Power
D1 | PE5 | I/O | SAI1_SCK_A
D2 | PE4 | I/O | SAI1_FS_A
D3 | PE3 | I/O | SAI1_SD_B

Pin Number TFBGA240 | Pin Name (function after reset) | Pin Type | Alternate Function(s) | Label
D4 | PB9 * | I/O | GPIO_Input | BT_SHIFT
D6 | PG15 | I/O | FMC_SDNCAS
D7 | PK7 | I/O | LTDC_DE
D12 | PD2 | I/O | SDMMC1_CMD
D13 | PD0 | I/O | FMC_D2
D14 | PA10 | I/O | USART1_RX
D15 | PA9 | I/O | USART1_TX
D17 | VCAP | Power
E1 | NC | NC
E2 | PI9 | I/O | UART4_RX
E5 | PE6 | I/O | SAI1_SD_A
E6 | VDD | Power
E7 | PDR_ON | Reset
E8 | BOOT0 | Boot
E9 | VDD | Power
E11 | VDD | Power
E12 | PD1 | I/O | FMC_D3
E13 | PC8 | I/O | SDMMC1_D0
E14 | PC9 | I/O | SDMMC1_D1
E15 | PA8 | I/O | UART7_RX
F1 | VSS | Power
F2 | VSS | Power
F5 | VDD | Power
F13 | PC7 | I/O | TIM3_CH2
F14 | PC6 | I/O | TIM3_CH1
F15 | PG8 | I/O | FMC_SDCLK
F17 | VDD33_USB | Power
G1 | PF2 | I/O | FMC_A2
G2 | VSS | Power
G3 | PF1 | I/O | FMC_A1
G4 | PF0 | I/O | FMC_A0
G5 | VDD | Power
G7 | VSS | Power
G8 | VSS | Power
G9 | VSS | Power
G10 | VSS | Power
G11 | VSS | Power
G13 | VDD | Power
G14 | PG5 | I/O | FMC_BA1

Pin Number TFBGA240 | Pin Name (function after reset) | Pin Type | Alternate Function(s) | Label
G15 | PG6 | I/O | QUADSPI_BK1_NCS
G16 | VSS | Power
G17 | VDD50_USB | Power
H1 | PI12 | I/O | LTDC_HSYNC
H2 | PI13 | I/O | LTDC_VSYNC
H3 | PI14 | I/O | LTDC_CLK
H4 | PF3 | I/O | FMC_A3
H5 | VDD | Power
H7 | VSS | Power
H8 | VSS | Power
H9 | VSS | Power
H10 | VSS | Power
H11 | VSS | Power
H13 | VDD | Power
H14 | PG4 | I/O | FMC_BA0
H16 | PG2 | I/O | FMC_A12
H17 | PK2 | I/O | LTDC_G7
J1 | PH1-OSC_OUT (PH1) | I/O | RCC_OSC_OUT
J2 | PH0-OSC_IN (PH0) | I/O | RCC_OSC_IN
J3 | VSS | Power
J4 | PF5 | I/O | FMC_A5
J5 | PF4 | I/O | FMC_A4
J7 | VSS | Power
J8 | VSS | Power
J9 | VSS | Power
J10 | VSS | Power
J11 | VSS | Power
J13 | VDD | Power
J14 | PK0 | I/O | LTDC_G5
J15 | PK1 | I/O | LTDC_G6
J16 | VSS | Power
J17 | VSS | Power
K1 | NRST | Reset
K2 | PF6 | I/O | QUADSPI_BK1_IO3
K3 | PF7 | I/O | QUADSPI_BK1_IO2
K4 | PF8 | I/O | QUADSPI_BK1_IO0
K5 | VDD | Power
K7 | VSS | Power
K8 | VSS | Power

Pin Number TFBGA240 | Pin Name (function after reset) | Pin Type | Alternate Function(s) | Label
K9 | VSS | Power
K10 | VSS | Power
K11 | VSS | Power
K13 | VDD | Power
K14 | PJ11 | I/O | LTDC_G4
K15 | VSS | Power
K16 | NC | NC
K17 | NC | NC
L1 | VDDA | Power
L3 | PF10 | I/O | QUADSPI_CLK
L4 | PF9 | I/O | QUADSPI_BK1_IO1
L5 | VDD | Power
L7 | VSS | Power
L8 | VSS | Power
L9 | VSS | Power
L10 | VSS | Power
L11 | VSS | Power
L13 | VDD | Power
L14 | PJ10 | I/O | LTDC_G3
L15 | VSS | Power
L16 | NC | NC
L17 | NC | NC
M3 | PC2 | I/O | FMC_SDNE0
M4 | PC3 | I/O | FMC_SDCKE0
M5 | VDD | Power
M13 | VDD | Power
M14 | PJ9 | I/O | LTDC_G2
M15 | VSS | Power
M16 | NC | NC
M17 | NC | NC
N1 | VREF- | Power
N2 | PH2 * | I/O | GPIO_Input | BT_TAG
N3 | PA2 * | I/O | GPIO_Output | LED_LOAD1
N4 | PA1 * | I/O | GPIO_Output | LED_LOAD0
N5 | PA0 | I/O | UART4_TX
N7 | VDD | Power
N8 | VDD | Power
N9 | PE10 | I/O | FMC_D7
N10 | VDD | Power

Pin Number TFBGA240 | Pin Name (function after reset) | Pin Type | Alternate Function(s) | Label
N11 | VDD | Power
N12 | VDD | Power
N13 | PJ8 | I/O | TIM8_CH1
N15 | PJ6 | I/O | LTDC_R7
N16 | VSS | Power
N17 | NC | NC
P1 | VSSA | Power
P2 | PH3 * | I/O | GPIO_Input | BT_BACK
P4 | PH5 | I/O | FMC_SDNWE
P5 | PI15 * | I/O | GPIO_Output | BACKLIGHT_EN
P7 | PF13 | I/O | FMC_A7
P8 | PF14 | I/O | FMC_A8
P9 | PE9 | I/O | FMC_D6
P10 | PE11 | I/O | FMC_D8
P13 | PH10 * | I/O | GPIO_Output | LED_MENU
P15 | PD15 | I/O | FMC_D1
P16 | PD14 | I/O | FMC_D0
P17 | VDD | Power
R4 | VSS | Power
R6 | PB2 * | I/O | GPIO_Input | BT_ENC
R7 | PF12 | I/O | FMC_A6
R8 | VSS | Power
R9 | PF15 | I/O | FMC_A9
R10 | PE12 | I/O | FMC_D9
R11 | PE15 | I/O | FMC_D12
R12 | PJ5 | I/O | LTDC_R6
R13 | PH9 * | I/O | GPIO_Output | LED_INFO
T3 | PA5 | I/O | SPI1_SCK
T5 | PB1 * | I/O | GPIO_Input | BT_LOAD1
T6 | PJ2 | I/O | LTDC_R3
T7 | PF11 | I/O | FMC_SDNRAS
T8 | PG0 | I/O | FMC_A10
T9 | PE8 | I/O | FMC_D5
T10 | PE13 | I/O | FMC_D10
T12 | VSS | Power
T13 | PH8 * | I/O | GPIO_Output | P8EN
T14 | PB12 * | I/O | GPIO_Input | BT_BROWSE
T16 | PD10 | I/O | FMC_D15
T17 | PD9 | I/O | FMC_D14

Pin Number TFBGA240 | Pin Name (function after reset) | Pin Type | Alternate Function(s) | Label
U1 | VSS | Power
U2 | PA3 * | I/O | GPIO_Output | LED_ENC
U3 | PA4 * | I/O | GPIO_Output | SPI1_NSS
U5 | PB0 * | I/O | GPIO_Input | BT_LOAD0
U6 | PJ3 | I/O | LTDC_R4
U7 | PJ4 | I/O | LTDC_R5
U8 | PG1 | I/O | FMC_A11
U9 | PE7 | I/O | FMC_D4
U10 | PE14 | I/O | FMC_D11
U11 | VCAP | Power
U12 | VDDLDO | Power
U13 | PH7 * | I/O | GPIO_Output | LED_TAGLIST
U14 | PB13 * | I/O | GPIO_Output | LED_BROWSE
U16 | PD8 | I/O | FMC_D13
U17 | VSS | Power

## * The pin is affected with an I/O function

# 4. Clock Tree Configuration

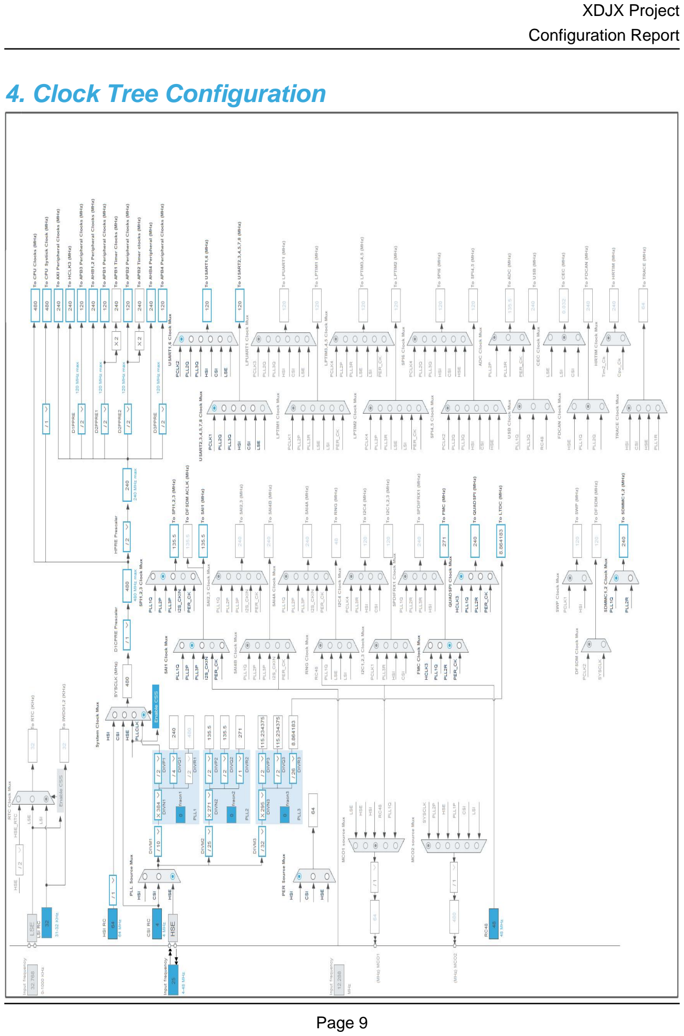
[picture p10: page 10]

# 5. Software Project

## 5.1. Project Settings

Name | Value
Project Name | XDJX
Project Folder | C:\Keil_v5\Projects\XDJX
Toolchain / IDE | MDK-ARM V5.32
Firmware Package Name and Version | STM32Cube FW_H7 V1.11.1
Application Structure | Basic
Generate Under Root | No
Do not generate the main() | No
Minimum Heap Size | 0x800
Minimum Stack Size | 0x1000

## 5.2. Code Generation Settings

Name | Value
STM32Cube MCU packages and embedded software | Copy only the necessary library files
Generate peripheral initialization as a pair of '.c/.h' files | Yes
Backup previously generated files when re-generating | No
Keep User Code when re-generating | Yes
Delete previously generated files when not re-generated | No
Set all free pins as analog (to optimize the power consumption) | No
Enable Full Assert | No

## 5.3. Advanced Settings - Generated Function Calls

Rank | Function Name | Peripheral Instance Name
1 | SystemClock_Config | RCC
2 | MX_GPIO_Init | GPIO
3 | MX_DMA_Init | DMA
4 | MX_DMA2D_Init | DMA2D
5 | MX_FMC_Init | FMC
6 | MX_LTDC_Init | LTDC
7 | MX_QUADSPI_Init | QUADSPI
8 | MX_SDMMC1_SD_Init | SDMMC1
9 | MX_SPI1_Init | SPI1
10 | MX_SPI2_Init | SPI2
11 | MX_TIM2_Init | TIM2

Rank | Function Name | Peripheral Instance Name
12 | MX_TIM3_Init | TIM3
13 | MX_TIM8_Init | TIM8
14 | MX_UART4_Init | UART4
15 | MX_UART7_Init | UART7
16 | MX_USART1_UART_Init | USART1
17 | MX_SAI1_Init | SAI1
18 | MX_FATFS_Init | FATFS

# 1. Power Consumption Calculator report

## 1.1. Microcontroller Selection

Series | STM32H7
Line | STM32H743/753
MCU | STM32H743XIHx
Datasheet | DS12110_Rev8

## 1.2. Parameter Selection

Temperature | 25
Vdd | 3.0

## 1.3. Battery Selection

Battery | Alkaline(9V)
Capacity | 625.0 mAh
Self Discharge | 0.3 %/month
Nominal Voltage | 9.0 V
Max Cont Current | 200.0 mA
Max Pulse Current | 0.0 mA
Cells in series | 1
Cells in parallel | 1

## 1.4. Sequence

Step | Step1 | Step2
Mode | RUN | STOP
Vdd | 3.0 | 3.0
Voltage Source | Battery | Battery
Range | VOS0: Scale0-High | SVOS5: System-Scale5
D1 Mode | DRUN/CRUN | DSTANDBY
D2 Mode | DRUN | DSTANDBY
D3 Mode | DRUN | DSTOP
Fetch Type | ITCM | NA
CPU Frequency | 480 MHz | 0 Hz
Clock Configuration | HSE BYP PLL | Flash-OFF
Clock Source Frequency | 24 MHz | 0 Hz

### Peripherals

Additional Cons. | 0 mA | 0 mA
Average Current | 148 mA | 150 µA
Duration | 0.1 ms | 0.9 ms
DMIPS | 1027.0 | 0.0
Ta Max | 108.57 | 124.98
Category | In DS Table | In DS Table

## 1.5. Results

Sequence Time | 1 ms | Average Current | 14.94 mA
Battery Life | 1 day, 17 hours | Average DMIPS | 1027.2001 DMIPS

## 1.6. Chart

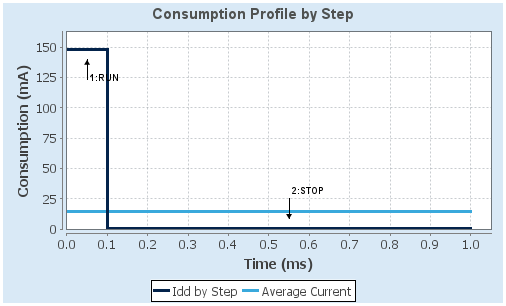
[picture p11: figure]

# 2. Peripherals and Middlewares Configuration

## 2.1. CORTEX_M7

## 2.1.1. Parameter Settings:

### Speculation default mode Settings:

Speculation default mode | Disabled

### Cortex Interface Settings:

CPU ICache | Enabled *
CPU DCache | Enabled *

### Cortex Memory Protection Unit Control Settings:

MPU Control Mode | Background Region Privileged accesses only + MPU Enabled during hard fault, NMI and FAULTMASK handlers *

### Cortex Memory Protection Unit Region 0 Settings:

MPU Region | Enabled *
MPU Region Base Address | 0x30000000 *
MPU Region Size | 256B *
MPU SubRegion Disable | 0x0 *
MPU TEX field level | level 0
MPU Access Permission | ALL ACCESS PERMITTED *
MPU Instruction Access | ENABLE
MPU Shareability Permission | ENABLE *
MPU Cacheable Permission | DISABLE
MPU Bufferable Permission | ENABLE *

### Cortex Memory Protection Unit Region 1 Settings:

MPU Region | Enabled *
MPU Region Base Address | 0x90000000 *
MPU Region Size | 8MB *
MPU SubRegion Disable | 0x0 *
MPU TEX field level | level 0
MPU Access Permission | ALL ACCESS PERMITTED *
MPU Instruction Access | ENABLE
MPU Shareability Permission | ENABLE *
MPU Cacheable Permission | ENABLE *
MPU Bufferable Permission | ENABLE *

### Cortex Memory Protection Unit Region 2 Settings:

MPU Region | Disabled

### Cortex Memory Protection Unit Region 3 Settings:

MPU Region | Disabled

### Cortex Memory Protection Unit Region 4 Settings:

MPU Region | Disabled

### Cortex Memory Protection Unit Region 5 Settings:

MPU Region | Disabled

### Cortex Memory Protection Unit Region 6 Settings:

MPU Region | Disabled

### Cortex Memory Protection Unit Region 7 Settings:

MPU Region | Disabled

### Cortex Memory Protection Unit Region 8 Settings:

MPU Region | Disabled

### Cortex Memory Protection Unit Region 9 Settings:

MPU Region | Disabled

### Cortex Memory Protection Unit Region 10 Settings:

MPU Region | Disabled

### Cortex Memory Protection Unit Region 11 Settings:

MPU Region | Disabled

### Cortex Memory Protection Unit Region 12 Settings:

MPU Region | Disabled

### Cortex Memory Protection Unit Region 13 Settings:

MPU Region | Disabled

### Cortex Memory Protection Unit Region 14 Settings:

MPU Region | Disabled

### Cortex Memory Protection Unit Region 15 Settings:

MPU Region | Disabled

## 2.2. DMA2D mode: Activated

## 2.2.1. Parameter Settings:

### Basic Parameters:

Transfer Mode | Memory to Memory
Color Mode | ARGB1555 *
Output Offset | 0

### Foreground layer Configuration:

DMA2D Input Color Mode | ARGB1555
DMA2D ALPHA MODE | No modification of the alpha channel value
Input Alpha | 0

Input Offset | 0
DMA2D ALPHA Inversion | Regular Alpha
DMA2D Red and Blue swap | Regular mode (RGB or ARGB)
DMA2D Chroma Sub-Sampling Mode | No chroma sub-sampling 4:4:4

## 2.3. FMC

## SDRAM 1

## Clock and chip enable: SDCKE0+SDNE0 Internal bank number: 4 banks Address: 13 bits Data: 16 bits Byte enable: 16-bit byte enable

## 2.3.1. SDRAM 1:

### SDRAM control:

Bank | SDRAM bank 1
Number of column address bits | 9 bits *
Number of row address bits | 13 bits
CAS latency | 3 memory clock cycles *
Write protection | Disabled
SDRAM common clock | 2 HCLK clock cycles *
SDRAM common burst read | Enabled *
SDRAM common read pipe delay | 1 HCLK clock cycle *

### SDRAM timing in memory clock cycles:

Load mode register to active delay | 2 *
Exit self-refresh delay | 7 *
Self-refresh time | 4 *
SDRAM common row cycle delay | 7 *
Write recovery time | 4 *
SDRAM common row precharge delay | 2 *
Row to column delay | 2 *

## 2.3.2. Bank Mapping:

### Mapping parameters:

FMC bank mapping | Default mapping

## 2.4. LTDC Display Type: RGB565 (16 bits)

## 2.4.1. Parameter Settings:

### Synchronization for Width:

Horizontal Synchronization Width | 94 *
Horizontal Back Porch | 6 *
Active Width | 480 *
Horizontal Front Porch | 41 *
HSync Width | 93
Accumulated Horizontal Back Porch Width | 99
Accumulated Active Width | 579
Total Width | 620

### Synchronization for Height:

Vertical Synchronization Height | 17 *
Vertical Back Porch | 2
Active Height | 233 *
Vertical Front Porch | 2
VSync Height | 16
Accumulated Vertical Back Porch Height | 18
Accumulated Active Height | 251
Total Height | 253

### Signal Polarity:

Horizontal Synchronization Polarity | Active Low
Vertical Synchronization Polarity | Active Low
Data Enable Polarity | Active Low
Pixel Clock Polarity | Normal Input

### Layer Default Color:

Red | 0
Green | 0
Blue | 0

## 2.4.2. Layer Settings:

### Layer Default Color:

Layer 0 - Alpha | 0
Layer 0 - Blue | 0

Layer 0 - Green | 0
Layer 0 - Red | 0
Layer 1 - Alpha | 0
Layer 1 - Blue | 0
Layer 1 - Green | 0
Layer 1 - Red | 0

### Windows Position:

Layer 0 - Window Horizontal Start | 0
Layer 0 - Window Horizontal Stop | 480 *
Layer 0 - Window Vertical Start | 0
Layer 0 - Window Vertical Stop | 233 *
Layer 1 - Window Horizontal Start | 0
Layer 1 - Window Horizontal Stop | 480 *
Layer 1 - Window Vertical Start | 0
Layer 1 - Window Vertical Stop | 233 *

### Pixel Parameters:

Layer 0 - Pixel Format | ARGB1555 *
Layer 1 - Pixel Format | ARGB1555 *

### Blending:

Layer 0 - Alpha constant for blending | 255 *
Layer 0 - Blending Factor1 | Alpha constant
Layer 0 - Blending Factor2 | Alpha constant
Layer 1 - Alpha constant for blending | 255 *
Layer 1 - Blending Factor1 | Alpha constant
Layer 1 - Blending Factor2 | Alpha constant

### Frame Buffer:

Layer 0 - Color Frame Buffer Start Adress | 0xC0000000 *
Layer 0 - Color Frame Buffer Line Length (Image Width) | 480 *
Layer 0 - Color Frame Buffer Number of Lines (Image Height) | 233 *
Layer 1 - Color Frame Buffer Start Adress | 0xC00369C0 *
Layer 1 - Color Frame Buffer Line Length (Image Width) | 480 *
Layer 1 - Color Frame Buffer Number of Lines (Image Height) | 233 *

### Number of Layers:

Number of Layers | 2 layers

## 2.5. QUADSPI QuadSPI Mode: Bank1 with Quad SPI Lines

## 2.5.1. Parameter Settings:

### General Parameters:

Clock Prescaler | 1 *
Fifo Threshold | 4 *
Sample Shifting | Sample Shifting Half Cycle *
Flash Size | 22 *
Chip Select High Time | 5 Cycles *
Clock Mode | Low
Flash ID | Flash ID 1
Dual Flash | Disabled

## 2.6. RCC High Speed Clock (HSE): Crystal/Ceramic Resonator

## 2.6.1. Parameter Settings:

### Power Parameters:

SupplySource | PWR_LDO_SUPPLY
Power Regulator Voltage Scale | Power Regulator Voltage Scale 0

### RCC Parameters:

TIM Prescaler Selection | Disabled
HSE Startup Timout Value (ms) | 100
LSE Startup Timout Value (ms) | 5000
CSI Calibration Value | 32
HSI Calibration Value | 64

### System Parameters:

VDD voltage (V) | 3.3
Flash Latency(WS) | 4 WS (5 CPU cycle)
Product revision | rev.V

### PLL range Parameters:

PLL1 clock Input range | Between 2 and 4 MHz
PLL2 input frequency range | Between 1 and 2 MHz
PLL3 input frequency range | Between 8 and 16 MHz
PLL1 clock Output range | Wide VCO range
PLL2 clock Output range | Wide VCO range

PLL3 clock Output range | Wide VCO range

## 2.7. SAI1 Mode: Asynchronous Slave Mode: Synchronous Slave

## 2.7.1. Parameter Settings:

### SAI A:

Synchronization Inputs | Asynchronous
Protocol | Free
Audio Mode | Slave Transmit *
Frame Length (only Even Values) | 64 *
Data Size | 32 Bits *
Slot Size | DataSize
Output Mode | Stereo
Companding Mode | No companding mode
SAI SD Line Output Mode | Driven
First Bit | MSB First
Frame Synchro Active Level Length | 32 *
Frame Synchro Definition | Channel Identification *
Frame Synchro Polarity | Active High *
Frame Synchro Offset | First Bit
First Bit Offset | 0
Number of Slots (only Even Values) | 2
Slot Active Final Value | 0x00000003 *
Slot Active | User Setting *
Slot 0 Active | true *
Slot 1 Active | true *
Clock Strobing | Rising Edge *
Fifo Threshold | Empty
Output Drive | Enabled *

### SAI B:

Synchronization Inputs | Synchronous with other block of same SAI
Protocol | Free
Audio Mode | Slave Transmit *
Frame Length (only Even Values) | 64 *
Data Size | 32 Bits *

Slot Size | DataSize
Output Mode | Stereo
Companding Mode | No companding mode
SAI SD Line Output Mode | Driven
First Bit | MSB First
Frame Synchro Active Level Length | 32 *
Frame Synchro Definition | Channel Identification *
Frame Synchro Polarity | Active High *
Frame Synchro Offset | First Bit
First Bit Offset | 0
Number of Slots (only Even Values) | 2
Slot Active Final Value | 0x00000003 *
Slot Active | User Setting *
Slot 0 Active | true *
Slot 1 Active | true *
Real Audio Frequency | 0
Error between Selected | 0
Clock Strobing | Rising Edge *
Fifo Threshold | Empty
Output Drive | Enabled *

## 2.8. SDMMC1 Mode: SD 4 bits Wide bus

## 2.8.1. Parameter Settings:

### SDMMC parameters:

Clock transition on which the bit capture is made | Rising transition
SDMMC Clock output enable when the bus is idle | Disable the power save for the clock
SDMMC hardware flow control | The hardware control flow is disabled
SDMMC clock divide factor | 14 *
Is external transceiver present ? | no

## 2.9. SPI1 Mode: Full-Duplex Master

## 2.9.1. Parameter Settings:

### Basic Parameters:

Frame Format | Motorola
Data Size | 8 Bits *
First Bit | MSB First

### Clock Parameters:

Prescaler (for Baud Rate) | 16 *
Baud Rate | 8.46875 MBits/s *
Clock Polarity (CPOL) | Low
Clock Phase (CPHA) | 1 Edge

### Advanced Parameters:

CRC Calculation | Disabled
NSSP Mode | Enabled
NSS Signal Type | Software
Fifo Threshold | Fifo Threshold 01 Data
Tx Crc Initialization Pattern | All Zero Pattern
Rx Crc Initialization Pattern | All Zero Pattern
Nss Polarity | Nss Polarity Low
Master Ss Idleness | 00 Cycle
Master Inter Data Idleness | 00 Cycle
Master Receiver Auto Susp | Disable
Master Keep Io State | Master Keep Io State Enable *
IO Swap | Disabled

## 2.10. SPI2 Mode: Full-Duplex Master Hardware NSS Signal: Hardware NSS Output Signal

## 2.10.1. Parameter Settings:

### Basic Parameters:

Frame Format | Motorola
Data Size | 8 Bits *
First Bit | MSB First

### Clock Parameters:

Prescaler (for Baud Rate) | 16 *
Baud Rate | 8.46875 MBits/s *
Clock Polarity (CPOL) | High *
Clock Phase (CPHA) | 1 Edge

### Advanced Parameters:

CRC Calculation | Disabled
NSSP Mode | Enabled
NSS Signal Type | Output Hardware
Fifo Threshold | Fifo Threshold 01 Data
Tx Crc Initialization Pattern | All Zero Pattern
Rx Crc Initialization Pattern | All Zero Pattern
Nss Polarity | Nss Polarity Low
Master Ss Idleness | 00 Cycle
Master Inter Data Idleness | 00 Cycle
Master Receiver Auto Susp | Disable
Master Keep Io State | Master Keep Io State Enable *
IO Swap | Disabled

## 2.11. SYS Timebase Source: SysTick

## 2.12. TIM2 Clock Source : Internal Clock

## 2.12.1. Parameter Settings:

### Counter Settings:

Prescaler (PSC - 16 bits value) | 239 *
Counter Mode | Up
Counter Period (AutoReload Register - 32 bits value ) | 2499 *
Internal Clock Division (CKD) | Division by 2 *
auto-reload preload | Disable

### Trigger Output (TRGO) Parameters:

Master/Slave Mode (MSM bit) | Disable (Trigger input effect not delayed)
Trigger Event Selection TRGO | Reset (UG bit from TIMx_EGR)

## 2.13. TIM3 Combined Channels: Encoder Mode

## 2.13.1. Parameter Settings:

### Counter Settings:

Prescaler (PSC - 16 bits value) | 0
Counter Mode | Up
Counter Period (AutoReload Register - 16 bits value ) | 1 *
Internal Clock Division (CKD) | No Division
auto-reload preload | Disable

### Trigger Output (TRGO) Parameters:

Master/Slave Mode (MSM bit) | Disable (Trigger input effect not delayed)
Trigger Event Selection TRGO | Reset (UG bit from TIMx_EGR)

### Encoder:

Encoder Mode | Encoder Mode TI1 and TI2 *

____ Parameters for Channel 1 ____
Polarity | Rising Edge
IC Selection | Direct
Prescaler Division Ratio | No division
Input Filter | 11 *

____ Parameters for Channel 2 ____
Polarity | Rising Edge
IC Selection | Direct
Prescaler Division Ratio | No division
Input Filter | 11 *

## 2.14. TIM8 Clock Source : Internal Clock Channel1: PWM Generation CH1

## 2.14.1. Parameter Settings:

### Counter Settings:

Prescaler (PSC - 16 bits value) | 479 *
Counter Mode | Up
Counter Period (AutoReload Register - 16 bits value ) | 599 *
Internal Clock Division (CKD) | Division by 4 *
Repetition Counter (RCR - 16 bits value) | 0
auto-reload preload | Disable

### Trigger Output (TRGO) Parameters:

Master/Slave Mode (MSM bit) | Disable (Trigger input effect not delayed)
Trigger Event Selection TRGO | Reset (UG bit from TIMx_EGR)
Trigger Event Selection TRGO2 | Reset (UG bit from TIMx_EGR)

### Break And Dead Time management - BRK Configuration:

BRK State | Disable
BRK Polarity | High
BRK Filter (4 bits value) | 0
BRK Sources Configuration
- Digital Input | Disable
- COMP1 | Disable
- COMP2 | Disable
- DFSDM | Disable

### Break And Dead Time management - BRK2 Configuration:

BRK2 State | Disable
BRK2 Polarity | High
BRK2 Filter (4 bits value) | 0
BRK2 Sources Configuration
- Digital Input | Disable
- COMP1 | Disable
- COMP2 | Disable
- DFSDM | Disable

### Break And Dead Time management - Output Configuration:

Automatic Output State | Disable
Off State Selection for Run Mode (OSSR) | Disable
Off State Selection for Idle Mode (OSSI) | Disable
Lock Configuration | Off

### Clear Input:

Clear Input Source | Disable

### PWM Generation Channel 1:

Mode | PWM mode 1
Pulse (16 bits value) | 0
Output compare preload | Enable
Fast Mode | Disable
CH Polarity | High
CH Idle State | Reset

## 2.15. UART4 Mode: Asynchronous

## 2.15.1. Parameter Settings:

### Basic Parameters:

Baud Rate | 256000 *
Word Length | 8 Bits (including Parity)
Parity | None

Stop Bits | 1

### Advanced Parameters:

Data Direction | Receive and Transmit
Over Sampling | 16 Samples
Single Sample | Disable
ClockPrescaler | 1
Fifo Mode | FIFO mode disable
Txfifo Threshold | 1 eighth full configuration
Rxfifo Threshold | 1 eighth full configuration

### Advanced Features:

Auto Baudrate | Disable
TX Pin Active Level Inversion | Disable
RX Pin Active Level Inversion | Disable
Data Inversion | Disable
TX and RX Pins Swapping | Disable
Overrun | Enable
DMA on RX Error | Enable
MSB First | Disable

## 2.16. UART7 Mode: Asynchronous

## 2.16.1. Parameter Settings:

### Basic Parameters:

Baud Rate | 256000 *
Word Length | 8 Bits (including Parity)
Parity | None
Stop Bits | 1

### Advanced Parameters:

Data Direction | Receive and Transmit
Over Sampling | 16 Samples
Single Sample | Disable
ClockPrescaler | 1
Fifo Mode | FIFO mode disable
Txfifo Threshold | 1 eighth full configuration
Rxfifo Threshold | 1 eighth full configuration

### Advanced Features:

Auto Baudrate | Disable
TX Pin Active Level Inversion | Disable
RX Pin Active Level Inversion | Disable

Data Inversion | Disable
TX and RX Pins Swapping | Disable
Overrun | Enable
DMA on RX Error | Enable
MSB First | Disable

## 2.17. USART1 Mode: Asynchronous

## 2.17.1. Parameter Settings:

### Basic Parameters:

Baud Rate | 500000 *
Word Length | 8 Bits (including Parity)
Parity | None
Stop Bits | 1

### Advanced Parameters:

Data Direction | Receive and Transmit
Over Sampling | 16 Samples
Single Sample | Disable
ClockPrescaler | 1
Fifo Mode | Disable
Txfifo Threshold | 1 eighth full configuration
Rxfifo Threshold | 1 eighth full configuration

### Advanced Features:

Auto Baudrate | Disable
TX Pin Active Level Inversion | Disable
RX Pin Active Level Inversion | Disable
Data Inversion | Disable
TX and RX Pins Swapping | Disable
Overrun | Enable
DMA on RX Error | Enable
MSB First | Disable

## 2.18. FATFS mode: SD Card

## 2.18.1. Set Defines:

### Version:

FATFS version | R0.12c

### Function Parameters:

FS_READONLY (Read-only mode) | Disabled
FS_MINIMIZE (Minimization level) | Disabled
USE_STRFUNC (String functions) | Enabled with LF -> CRLF conversion
USE_FIND (Find functions) | Disabled
USE_MKFS (Make filesystem function) | Enabled
USE_FASTSEEK (Fast seek function) | Enabled
USE_EXPAND (Use f_expand function) | Disabled
USE_CHMOD (Change attributes function) | Disabled
USE_LABEL (Volume label functions) | Disabled
USE_FORWARD (Forward function) | Disabled

### Locale and Namespace Parameters:

CODE_PAGE (Code page on target) | Latin 1
USE_LFN (Use Long Filename) | Enabled with static working buffer on the BSS *
MAX_LFN (Max Long Filename) | 255
LFN_UNICODE (Enable Unicode) | ANSI/OEM
STRF_ENCODE (Character encoding) | UTF-8
FS_RPATH (Relative Path) | Disabled

### Physical Drive Parameters:

VOLUMES (Logical drives) | 1
MAX_SS (Maximum Sector Size) | 4096 *
MIN_SS (Minimum Sector Size) | 512
MULTI_PARTITION (Volume partitions feature) | Disabled
USE_TRIM (Erase feature) | Disabled
FS_NOFSINFO (Force full FAT scan) | 0

### System Parameters:

FS_TINY (Tiny mode) | Disabled
FS_EXFAT (Support of exFAT file system) | Disabled
FS_NORTC (Timestamp feature) | Fixed timestamp *
NORTC_YEAR (Year for timestamp) | 2025 *
NORTC_MON (Month for timestamp) | 6
NORTC_MDAY (Day for timestamp) | 20 *
FS_REENTRANT (Re-Entrancy) | Disabled
FS_TIMEOUT (Timeout ticks) | 1000
FS_LOCK (Number of files opened simultaneously) | 3 *

## 2.18.2. Advanced Settings:

### SDIO/SDMMC:

SDMMC instance | SDMMC1
Use dma template | Disabled
BSP code for SD | Generic

## 2.18.3. Platform Settings:

Detect_SDIO | PD5

### * User modified value

# 3. System Configuration

## 3.1. GPIO configuration

IP | Pin | Signal | GPIO mode | GPIO pull/up pull down

## Max Speed

## User Label

FMC | PE1 | FMC_NBL1 | Alternate Function Push Pull | No pull-up and no pull-down | Very High
| PE0 | FMC_NBL0 | Alternate Function Push Pull | No pull-up and no pull-down | Very High
PG15 | FMC_SDNCAS Alternate Function Push Pull | No pull-up and no pull-down | Very High
| PD0 | FMC_D2 | Alternate Function Push Pull | No pull-up and no pull-down | Very High
| PD1 | FMC_D3 | Alternate Function Push Pull | No pull-up and no pull-down | Very High
| PG8 | FMC_SDCLK | Alternate Function Push Pull | No pull-up and no pull-down | Very High
| PF2 | FMC_A2 | Alternate Function Push Pull | No pull-up and no pull-down | Very High
| PF1 | FMC_A1 | Alternate Function Push Pull | No pull-up and no pull-down | Very High
| PF0 | FMC_A0 | Alternate Function Push Pull | No pull-up and no pull-down | Very High
| PG5 | FMC_BA1 | Alternate Function Push Pull | No pull-up and no pull-down | Very High
| PF3 | FMC_A3 | Alternate Function Push Pull | No pull-up and no pull-down | Very High
| PG4 | FMC_BA0 | Alternate Function Push Pull | No pull-up and no pull-down | Very High
| PG2 | FMC_A12 | Alternate Function Push Pull | No pull-up and no pull-down | Very High
| PF5 | FMC_A5 | Alternate Function Push Pull | No pull-up and no pull-down | Very High
| PF4 | FMC_A4 | Alternate Function Push Pull | No pull-up and no pull-down | Very High
| PC2 | FMC_SDNE0 | Alternate Function Push Pull | No pull-up and no pull-down | Very High
PC3 | FMC_SDCKE0 Alternate Function Push Pull | No pull-up and no pull-down | Very High
| PE10 | FMC_D7 | Alternate Function Push Pull | No pull-up and no pull-down | Very High
PH5 | FMC_SDNWE Alternate Function Push Pull | No pull-up and no pull-down | Very High
| PF13 | FMC_A7 | Alternate Function Push Pull | No pull-up and no pull-down | Very High
| PF14 | FMC_A8 | Alternate Function Push Pull | No pull-up and no pull-down | Very High
| PE9 | FMC_D6 | Alternate Function Push Pull | No pull-up and no pull-down | Very High
| PE11 | FMC_D8 | Alternate Function Push Pull | No pull-up and no pull-down | Very High
| PD15 | FMC_D1 | Alternate Function Push Pull | No pull-up and no pull-down | Very High
| PD14 | FMC_D0 | Alternate Function Push Pull | No pull-up and no pull-down | Very High
| PF12 | FMC_A6 | Alternate Function Push Pull | No pull-up and no pull-down | Very High
| PF15 | FMC_A9 | Alternate Function Push Pull | No pull-up and no pull-down | Very High
| PE12 | FMC_D9 | Alternate Function Push Pull | No pull-up and no pull-down | Very High
| PE15 | FMC_D12 | Alternate Function Push Pull | No pull-up and no pull-down | Very High
PF11 | FMC_SDNRAS Alternate Function Push Pull | No pull-up and no pull-down | Very High
| PG0 | FMC_A10 | Alternate Function Push Pull | No pull-up and no pull-down | Very High
| PE8 | FMC_D5 | Alternate Function Push Pull | No pull-up and no pull-down | Very High
| PE13 | FMC_D10 | Alternate Function Push Pull | No pull-up and no pull-down | Very High
| PD10 | FMC_D15 | Alternate Function Push Pull | No pull-up and no pull-down | Very High
| PD9 | FMC_D14 | Alternate Function Push Pull | No pull-up and no pull-down | Very High
| PG1 | FMC_A11 | Alternate Function Push Pull | No pull-up and no pull-down | Very High

IP | Pin | Signal | GPIO mode | GPIO pull/up pull down

## Max Speed

## User Label

| PE7 | FMC_D4 | Alternate Function Push Pull | No pull-up and no pull-down | Very High
| PE14 | FMC_D11 | Alternate Function Push Pull | No pull-up and no pull-down | Very High
| PD8 | FMC_D13 | Alternate Function Push Pull | No pull-up and no pull-down | Very High
LTDC | PK5 | LTDC_B6 | Alternate Function Push Pull | No pull-up and no pull-down | Low
| PK4 | LTDC_B5 | Alternate Function Push Pull | No pull-up and no pull-down | Low
| PJ15 | LTDC_B3 | Alternate Function Push Pull | No pull-up and no pull-down | Low
| PK6 | LTDC_B7 | Alternate Function Push Pull | No pull-up and no pull-down | Low
| PK3 | LTDC_B4 | Alternate Function Push Pull | No pull-up and no pull-down | Low
| PK7 | LTDC_DE | Alternate Function Push Pull | No pull-up and no pull-down | Low
PI12 | LTDC_HSYNC Alternate Function Push Pull | No pull-up and no pull-down | Low
PI13 | LTDC_VSYNC Alternate Function Push Pull | No pull-up and no pull-down | Low
| PI14 | LTDC_CLK | Alternate Function Push Pull | No pull-up and no pull-down | Low
| PK2 | LTDC_G7 | Alternate Function Push Pull | No pull-up and no pull-down | Low
| PK0 | LTDC_G5 | Alternate Function Push Pull | No pull-up and no pull-down | Low
| PK1 | LTDC_G6 | Alternate Function Push Pull | No pull-up and no pull-down | Low
| PJ11 | LTDC_G4 | Alternate Function Push Pull | No pull-up and no pull-down | Low
| PJ10 | LTDC_G3 | Alternate Function Push Pull | No pull-up and no pull-down | Low
| PJ9 | LTDC_G2 | Alternate Function Push Pull | No pull-up and no pull-down | Low
| PJ6 | LTDC_R7 | Alternate Function Push Pull | No pull-up and no pull-down | Low
| PJ5 | LTDC_R6 | Alternate Function Push Pull | No pull-up and no pull-down | Low
| PJ2 | LTDC_R3 | Alternate Function Push Pull | No pull-up and no pull-down | Low
| PJ3 | LTDC_R4 | Alternate Function Push Pull | No pull-up and no pull-down | Low
| PJ4 | LTDC_R5 | Alternate Function Push Pull | No pull-up and no pull-down | Low
QUADSPI | PG6 | QUADSPI_BK1_ NCS | Alternate Function Push Pull | No pull-up and no pull-down | High *
| PF6 | QUADSPI_BK1_I O3 | Alternate Function Push Pull | No pull-up and no pull-down | High *
| PF7 | QUADSPI_BK1_I O2 | Alternate Function Push Pull | No pull-up and no pull-down | High *
| PF8 | QUADSPI_BK1_I O0 | Alternate Function Push Pull | No pull-up and no pull-down | High *
PF10 | QUADSPI_CLK Alternate Function Push Pull | No pull-up and no pull-down | High *
| PF9 | QUADSPI_BK1_I O1 | Alternate Function Push Pull | No pull-up and no pull-down | High *
RCC | PH1- OSC_OUT (PH1) | RCC_OSC_OUT | n/a | n/a | n/a

PH0-
OSC_IN
(PH0)
RCC_OSC_IN | n/a | n/a | n/a
SAI1 | PE5 | SAI1_SCK_A | Alternate Function Push Pull | No pull-up and no pull-down | Low
| PE4 | SAI1_FS_A | Alternate Function Push Pull | No pull-up and no pull-down | Low

IP | Pin | Signal | GPIO mode | GPIO pull/up pull down | Max Speed | User Label
| PE3 | SAI1_SD_B | Alternate Function Push Pull | No pull-up and no pull-down | Low
| PE6 | SAI1_SD_A | Alternate Function Push Pull | No pull-up and no pull-down | Low
SDMMC1 | PC10 | SDMMC1_D2 | Alternate Function Push Pull | No pull-up and no pull-down | Very High
| PC11 | SDMMC1_D3 | Alternate Function Push Pull | No pull-up and no pull-down | Very High
| PC12 | SDMMC1_CK | Alternate Function Push Pull | No pull-up and no pull-down | Very High
| PD2 | SDMMC1_CMD | Alternate Function Push Pull | No pull-up and no pull-down | Very High
| PC8 | SDMMC1_D0 | Alternate Function Push Pull | No pull-up and no pull-down | Very High
| PC9 | SDMMC1_D1 | Alternate Function Push Pull | No pull-up and no pull-down | Very High
SPI1 | PB5 | SPI1_MOSI | Alternate Function Push Pull | No pull-up and no pull-down | Low
| PG9 | SPI1_MISO | Alternate Function Push Pull | No pull-up and no pull-down | Low
| PA5 | SPI1_SCK | Alternate Function Push Pull | No pull-up and no pull-down | Low
SPI2 | PI1 | SPI2_SCK | Alternate Function Push Pull | No pull-up and no pull-down | Low
| PI0 | SPI2_NSS | Alternate Function Push Pull | No pull-up and no pull-down | Low
| PI2 | SPI2_MISO | Alternate Function Push Pull | No pull-up and no pull-down | Low
| PI3 | SPI2_MOSI | Alternate Function Push Pull | No pull-up and no pull-down | Low
TIM3 | PC7 | TIM3_CH2 | Alternate Function Push Pull | Pull-up * | Low
| PC6 | TIM3_CH1 | Alternate Function Push Pull | Pull-up * | Low
TIM8 | PJ8 | TIM8_CH1 | Alternate Function Push Pull | No pull-up and no pull-down | Low
UART4 | PI9 | UART4_RX | Alternate Function Push Pull | No pull-up and no pull-down | Low
| PA0 | UART4_TX | Alternate Function Push Pull | No pull-up and no pull-down | Low
UART7 | PA15 (JTDI) | UART7_TX | Alternate Function Push Pull | No pull-up and no pull-down | Low
| PA8 | UART7_RX | Alternate Function Push Pull | No pull-up and no pull-down | Low
USART1 | PA10 | USART1_RX | Alternate Function Push Pull | No pull-up and no pull-down | Low
| PA9 | USART1_TX | Alternate Function Push Pull | No pull-up and no pull-down | Low
GPIO | PI6 | GPIO_Input | Input mode | Pull-up * | n/a | BT_INFO
| PI4 | GPIO_Input | Input mode | Pull-up * | n/a | BT_TAGLIST
| PD5 | GPIO_Input | Input mode | Pull-up * | n/a | SD_DETECT
| PI7 | GPIO_Input | Input mode | Pull-up * | n/a | BT_MENU
| PE2 | GPIO_Output | Output Push Pull | No pull-up and no pull-down | Low | AMP_EN
| PB9 | GPIO_Input | Input mode | No pull-up and no pull-down | n/a | BT_SHIFT
| PH2 | GPIO_Input | Input mode | Pull-up * | n/a | BT_TAG
| PA2 | GPIO_Output | Output Push Pull | No pull-up and no pull-down | Medium * | LED_LOAD1
| PA1 | GPIO_Output | Output Push Pull | No pull-up and no pull-down | Medium * | LED_LOAD0
| PH3 | GPIO_Input | Input mode | Pull-up * | n/a | BT_BACK
| PI15 | GPIO_Output | Output Push Pull | No pull-up and no pull-down | Medium * | BACKLIGHT_EN
| PH10 | GPIO_Output | Output Push Pull | No pull-up and no pull-down | Medium * | LED_MENU
| PB2 | GPIO_Input | Input mode | Pull-up * | n/a | BT_ENC
| PH9 | GPIO_Output | Output Push Pull | No pull-up and no pull-down | Medium * | LED_INFO

IP | Pin | Signal | GPIO mode | GPIO pull/up pull down | Max Speed | User Label
| PB1 | GPIO_Input | Input mode | Pull-up * | n/a | BT_LOAD1
| PH8 | GPIO_Output | Output Push Pull | No pull-up and no pull-down | Medium * | P8EN
| PB12 | GPIO_Input | Input mode | Pull-up * | n/a | BT_BROWSE
| PA3 | GPIO_Output | Output Push Pull | No pull-up and no pull-down | Medium * | LED_ENC
| PA4 | GPIO_Output | Output Push Pull | No pull-up and no pull-down | Medium * | SPI1_NSS
| PB0 | GPIO_Input | Input mode | Pull-up * | n/a | BT_LOAD0
| PH7 | GPIO_Output | Output Push Pull | No pull-up and no pull-down | Medium * | LED_TAGLIST
| PB13 | GPIO_Output | Output Push Pull | No pull-up and no pull-down | Medium * | LED_BROWSE

## 3.2. DMA configuration

DMA request | Stream | Direction | Priority
MEMTOMEM | DMA1_Stream0 | Memory To Memory | Medium *
SPI2_TX | DMA2_Stream0 | Memory To Peripheral | Very High *
SPI2_RX | DMA2_Stream1 | Peripheral To Memory | Very High *

## MEMTOMEM: DMA1_Stream0 DMA request Settings:

Mode: | Normal
Use fifo: | Enable *
FIFO Threshold: | Full
Src Memory Increment: | Enable *
Dst Memormy Increment: | Enable *
Src Memory Data Width: | Word *
Dst Memormy Data Width: | Word *
Src Memory Burst Size: | Single
Dst Memormy Burst Size: | Single

## SPI2_TX: DMA2_Stream0 DMA request Settings:

Mode: | Normal
Use fifo: | Disable
Peripheral Increment: | Disable
Memory Increment: | Enable *
Peripheral Data Width: | Byte
Memory Data Width: | Byte

## SPI2_RX: DMA2_Stream1 DMA request Settings:

Mode: | Normal
Use fifo: | Disable
Peripheral Increment: | Disable
Memory Increment: | Enable *
Peripheral Data Width: | Byte
Memory Data Width: | Byte

## 3.3. BDMA configuration

## nothing configured in DMA service

## 3.4. MDMA configuration

## nothing configured in DMA service

## 3.5. NVIC configuration

## 3.5.1. NVIC

Interrupt Table | Enable | Preenmption Priority | SubPriority
Non maskable interrupt | true | 0 | 0
Hard fault interrupt | true | 0 | 0
Memory management fault | true | 0 | 0
Pre-fetch fault, memory access fault | true | 0 | 0
Undefined instruction or illegal state | true | 0 | 0
System service call via SWI instruction | true | 0 | 0
Debug monitor | true | 0 | 0
Pendable request for system service | true | 0 | 0
System tick timer | true | 15 | 0
TIM2 global interrupt | true | 2 | 0
TIM3 global interrupt | true | 5 | 0
SPI2 global interrupt | true | 2 | 0
USART1 global interrupt | true | 4 | 0
UART4 global interrupt | true | 7 | 0
DMA2 stream0 global interrupt | true | 3 | 0
DMA2 stream1 global interrupt | true | 3 | 0
UART7 global interrupt | true | 6 | 0
SAI1 global interrupt | true | 0 | 0
PVD and AVD interrupts through EXTI line 16 | unused
Flash global interrupt | unused
RCC global interrupt | unused
DMA1 stream0 global interrupt | unused
SPI1 global interrupt | unused
TIM8 break interrupt and TIM12 global interrupt | unused
TIM8 update interrupt and TIM13 global interrupt | unused
TIM8 trigger and commutation interrupts and TIM14 global interrupt | unused
TIM8 capture compare interrupt | unused
FMC global interrupt | unused
SDMMC1 global interrupt | unused
FPU global interrupt | unused
LTDC global interrupt | unused
LTDC global error interrupt | unused
DMA2D global interrupt | unused
QUADSPI global interrupt | unused
HSEM1 global interrupt | unused

## 3.5.2. NVIC Code generation

Enabled interrupt Table | Select for init sequence ordering | Generate IRQ handler | Call HAL handler
Non maskable interrupt | false | true | false
Hard fault interrupt | false | true | false
Memory management fault | false | true | false
Pre-fetch fault, memory access fault | false | true | false
Undefined instruction or illegal state | false | true | false
System service call via SWI instruction | false | true | false
Debug monitor | false | true | false
Pendable request for system service | false | true | false
System tick timer | false | true | true
TIM2 global interrupt | false | true | true
TIM3 global interrupt | false | true | true
SPI2 global interrupt | false | true | true
USART1 global interrupt | false | true | true
UART4 global interrupt | false | true | true
DMA2 stream0 global interrupt | false | true | true
DMA2 stream1 global interrupt | false | true | true
UART7 global interrupt | false | true | true
SAI1 global interrupt | false | true | true

### * User modified value

# 4. System Views

## 4.1. Category view 4.1.1. Current

## 4.1.2. Without filters

## 4.2. Power Domain view

# 5. Docs & Resources

Type | Link
BSDL files | https://www.st.com/resource/en/bsdl_model/stm32h7_bsdl.zip
IBIS models | https://www.st.com/resource/en/ibis_model/stm32h7_ibis.zip
System View Description | https://www.st.com/resource/en/svd/stm32h7-svd.zip
Presentations | https://www.st.com/resource/en/product_presentation/microcontrollers_stm32h7_series_product_overview.pdf
Presentations | https://www.st.com/resource/en/product_presentation/stm32-stm8_embedded_software_solutions.pdf
Presentations | https://www.st.com/resource/en/product_presentation/stm32_eval-tools_portfolio.pdf
Presentations | https://www.st.com/resource/en/product_presentation/stm32_stm8_functi onal-safety-packages.pdf
Presentations | https://www.st.com/resource/en/product_presentation/stm32-stm8_software_development_tools.pdf
Presentations | https://www.st.com/resource/en/product_presentation/microcontrollers-stm32-family-overview.pdf
Brochures | https://www.st.com/resource/en/brochure/brstm32h7.pdf
Brochures | https://www.st.com/resource/en/brochure/brstm32h7vl.pdf
Brochures | https://www.st.com/resource/en/brochure/products-and-solutions-for-plcs-and-smart-i-os.pdf
Flyers | https://www.st.com/resource/en/flyer/flstm32nucleo.pdf
Flyers | https://www.st.com/resource/en/flyer/flstm32trust.pdf
Flyers | https://www.st.com/resource/en/flyer/flpowerstbd.pdf
Application Notes | https://www.st.com/resource/en/application_note/an1181-electrostatic-discharge-sensitivity-measurement-stmicroelectronics.pdf
Application Notes | https://www.st.com/resource/en/application_note/an1709-emc-design-guide-for-stm8-stm32-and-legacy-mcus-stmicroelectronics.pdf
Application Notes | https://www.st.com/resource/en/application_note/an2606-stm32-microcontroller-system-memory-boot-mode-stmicroelectronics.pdf

Application Notes | https://www.st.com/resource/en/application_note/an2639-soldering-recommendations-and-package-information-for-leadfree-ecopack-mcus-and-mpus-stmicroelectronics.pdf
Application Notes | https://www.st.com/resource/en/application_note/an2867-oscillator-design-guide-for-stm8afals-stm32-mcus-and-mpus-stmicroelectronics.pdf
Application Notes | https://www.st.com/resource/en/application_note/an3126-audio-and-waveform-generation-using-the-dac-in-stm32-products-stmicroelectronics.pdf
Application Notes | https://www.st.com/resource/en/application_note/an3155-usart-protocol-used-in-the-stm32-bootloader-stmicroelectronics.pdf
Application Notes | https://www.st.com/resource/en/application_note/an3156-usb-dfu-protocol-used-in-the-stm32-bootloader-stmicroelectronics.pdf
Application Notes | https://www.st.com/resource/en/application_note/an4013-stm32-crossseries-timer-overview-stmicroelectronics.pdf
Application Notes | https://www.st.com/resource/en/application_note/an4221-i2c-protocol-used-in-the-stm32-bootloader-stmicroelectronics.pdf
Application Notes | https://www.st.com/resource/en/application_note/an4229-how-to-implement-a-vocoder-solution-using-stm32-microcontrollers-stmicroelectronics.pdf
Application Notes | https://www.st.com/resource/en/application_note/an4277-using-stm32-device-pwm-shutdown-features-for-motor-control-and-digital-power-conversion-stmicroelectronics.pdf
Application Notes | https://www.st.com/resource/en/application_note/an4286-spi-protocol-used-in-the-stm32-bootloader-stmicroelectronics.pdf
Application Notes | https://www.st.com/resource/en/application_note/an4539-hrtim-cookbook-stmicroelectronics.pdf
Application Notes | https://www.st.com/resource/en/application_note/an4566-extending-the-dac-performance-of-stm32-microcontrollers-stmicroelectronics.pdf
Application Notes | https://www.st.com/resource/en/application_note/an4635-minimization-of-power-consumption-using-lpuart-for-stm32-microcontrollers-stmicroelectronics.pdf
Application Notes | https://www.st.com/resource/en/application_note/an4655-virtually- increasing-the-number-of-serial-communication-peripherals-in-stm32-

| applications-stmicroelectronics.pdf
Application Notes | https://www.st.com/resource/en/application_note/an4750-handling-of-soft-errors-in-stm32-applications-stmicroelectronics.pdf
Application Notes | https://www.st.com/resource/en/application_note/an4759-using-the-hardware-realtime-clock-rtc-and-the-tamper-management-unit-tamp-with-stm32-microcontrollers-stmicroe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
Application Notes | https://www.st.com/resource/en/application_note/an4776-generalpurpose-timer-cookbook-for-stm32-microcontrollers-stmicroelectronics.pdf
Application Notes | https://www.st.com/resource/en/application_note/an4803-highspeed-si-simulations-using-ibis-and-boardlevel-simulations-using-hyperlynx-si-on-stm32-mcus-and-mpus-stmic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
Application Notes | https://www.st.com/resource/en/application_note/an4839-level-1-cache-on-stm32f7-series-and-stm32h7-series-stmicroelectronics.pdf
Application Notes | https://www.st.com/resource/en/application_note/an4861-lcdtft-display-controller-ltdc-on-stm32-mcus-stmicroelectronics.pdf
Application Notes | https://www.st.com/resource/en/application_note/an4891-stm32h72x-stm32h73x-and-singlecore-stm32h74x75x-system-architecture-and-performance-stmicroelectronics.pdf
Application Notes | https://www.st.com/resource/en/application_note/an4908-stm32-usart-automatic-baud-rate-detection-stmicroelectronics.pdf
Application Notes | https://www.st.com/resource/en/application_note/an4936-migration-of-microcontroller-applications-from-stm32f7-series-to-stm32h743753-line-stmicroelectronics.pdf
Application Notes | https://www.st.com/resource/en/application_note/an4989-stm32-microcontroller-debug-toolbox-stmicroelectronics.pdf
Application Notes | https://www.st.com/resource/en/application_note/an4990-getting-started-with-sigmadelta-digital-interface-on-applicable-stm32-microcontrollers-stmicroelectronics.pdf
Application Notes | https://www.st.com/resource/en/application_note/an4996-hardware-jpeg-codec-peripheral-in-stm32f7677xxx-and-stm32h743534555475750a3b3b0xx-microcontrollers-stmicroelec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
Application Notes | https://www.st.com/resource/en/application_note/an5020-digital-camera-

| interface-dcmi-on-stm32-mcus-stmicroelectronics.pdf
Application Notes | https://www.st.com/resource/en/application_note/an5027-interfacing-pdm-digital-microphones-using-stm32-mcus-and-mpus-stmicroelectronics.pdf
Application Notes | https://www.st.com/resource/en/application_note/an5033-stm32cube-mcu-package-examples-for-stm32h7-series-stmicroelectronics.pdf
Application Notes | https://www.st.com/resource/en/application_note/an5073-receiving-spdif-audio-stream-with-the-stm32f4f7h7-series-stmicroelectronics.pdf
Application Notes | https://www.st.com/resource/en/application_note/an5200-getting-started-with-stm32h7-series-sdmmc-host-controller-stmicroelectronics.pdf
Application Notes | https://www.st.com/resource/en/application_note/an5224-stm32-dmamux-the-dma-request-router-stmicroelectronics.pdf
Application Notes | https://www.st.com/resource/en/application_note/an5312-migration-from-revy-to-revv-for-stm32h743753-and-stm32h750-value-line-microcontrollers-stmicroelectronics.pdf
Application Notes | https://www.st.com/resource/en/application_note/an5337-stm32h7-series-lifetime-estimates-stmicroelectronics.pdf
Application Notes | https://www.st.com/resource/en/application_note/an5354-getting-started-with-the-stm32h7-series-mcu-16bit-adc-stmicroelectronics.pdf
Application Notes | https://www.st.com/resource/en/application_note/an5543-enhanced-methods-to-handle-spi-communication-on-stm32-devices-stmicroelectronics.pdf
Application Notes | https://www.st.com/resource/en/application_note/an4760-quadspi-interface-on-stm32-microcontrollers-and-microprocessors--stmicroelectronics.pdf
Application Notes | https://www.st.com/resource/en/application_note/an4899-stm32-microcontroller-gpio-hardware-settings-and-lowpower-consumption-stmicroelectronics.pdf
Application Notes | https://www.st.com/resource/en/application_note/an5507-cyclic-redundancy-check-in-stm32h7-series-flash-memory-interface-stmicroelectronics.pdf
Application Notes | https://www.st.com/resource/en/application_note/an5612-esd-protection-of-stm32-mcus-and-mpus-stmicroelectronics.pdf
Application Notes | https://www.st.com/resource/en/application_note/an5293-migration-guide-

| from-stm32f7-series-to-stmh74x75x-stm32h72x73x-and-stmh7a37bx-devices-stmicroelectronics.pdf
Application Notes | https://www.st.com/resource/en/application_note/an5156-introduction-to-stm32-microcontrollers-security-stmicroelectronics.pdf
Application Notes | https://www.st.com/resource/en/application_note/an4838-introduction-to-memory-protection-unit-management-on-stm32-mcus-stmicroelectronics.pdf
Application Notes | https://www.st.com/resource/en/application_note/an5348-introduction-to-fdcan-peripherals-for-stm32-product-classes-stmicroelectronics.pdf
Application Notes | https://www.st.com/resource/en/application_note/an4230-random-number-generation-validation-using-nist-statistical-test-suite-for-stm32-microcontrollers-stmicroelectr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
Application Notes | https://www.st.com/resource/en/application_note/an4879-introduction-to-usb-hardware-and-pcb-guidelines-using-stm32-mcus-stmicroelectronics.pdf
Application Notes | https://www.st.com/resource/en/application_note/an5225-introduction-to-usb-typec-power-delivery-for-stm32-mcus-and-mpus-stmicroelectronics.pdf
Application Notes | https://www.st.com/resource/en/application_note/an5342--how-to-use-error-correction-code-ecc-management-for-internal-memories-protection-on-stm32-mcus-stmicroelectro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
Application Notes | https://www.st.com/resource/en/application_note/an2834-how-to-optimize-the-adc-accuracy-in-the-stm32-mcus-stmicroelectronics.pdf
Application Notes | https://www.st.com/resource/en/application_note/an4938-getting-started-with-stm32h74xig-and-stm32h75xig-mcu-hardware-development-stmicroelectronics.pdf
Application Notes | https://www.st.com/resource/en/application_note/an5816-how-to-build-stm32-lpbam-application-using-stm32cubemx-stmicroelectronics.pdf
Application Notes | https://www.st.com/resource/en/application_note/an5537-how-to-use-adc-oversampling-techniques-to-improve-signaltonoise-ratio-on-stm32-mcus-stmicroelectronics.pdf
Application Notes | https://www.st.com/resource/en/application_note/an5036-guidelines-for-thermal-management-on-stm32-applications-stmicroelectronics.pdf

Application Notes | https://www.st.com/resource/en/application_note/an5405-how-to-use-fdcan-bootloader-protocol-on-stm32-mcus-stmicroelectronics.pdf
Application Notes | https://www.st.com/resource/en/application_note/an5690-how-to-use-vrefbuf-peripheral-on-stm32-mcus-and-mpus-stmicroelectronics.pdf
Application Notes for related Tools & Software | https://www.st.com/resource/en/application_note/an1202_freertos_guide-freertos-guide-stmicroelectronics.pdf
Application Notes for related Tools & Software | https://www.st.com/resource/en/application_note/an1602_semihosting_in_truestudio-how-to-do-semihosting-in-truestudio-stmicroelectronics.pdf
Application Notes for related Tools & Software | https://www.st.com/resource/en/application_note/an1801_stm32cubeprogrammer_in_truestudio-installing-stm32cubeprogrammer-in-truestudio-stmicroelectronics.pdf
Application Notes for related Tools & Software | https://www.st.com/resource/en/application_note/atollic_editing_keyboard_shortcuts-atollic-editing-keyboard-shortcuts-stmicroelectronics.pdf
Application Notes for related Tools & Software | https://www.st.com/resource/en/application_note/iar_to_atollic_truestudio_migration_guide-truestudio-for-arm-migration-guide-iar-embedded-workbench-to-truestudio-stm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
Application Notes for related Tools & Software | https://www.st.com/resource/en/application_note/stm32cubemx_installation_in_truestudio-stm32cubemx-installation-in-truestudio-stmicroelectronics.pdf
Application Notes for related Tools & Software | https://www.st.com/resource/en/application_note/an4323-getting-started-with-stemwin-library-stmicroelectronics.pdf
Application Notes for related Tools & Software | https://www.st.com/resource/en/application_note/an4435-guidelines-for-obtaining-ulcsaiec-607301603351-class-b-certification-in-any-stm32-application-stmicroelectroni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
Application Notes for related Tools & Software | https://www.st.com/resource/en/application_note/an4635-minimization-of-power-consumption-using-lpuart-for-stm32-microcontrollers-stmicroelectronics.pdf
Application Notes for related Tools & Software | https://www.st.com/resource/en/application_note/an4657-stm32-inapplication-programming-iap-using-the-usart-stmicroelectronics.pdf

Application Notes for related Tools & Software | https://www.st.com/resource/en/application_note/an4759-using-the-hardware-realtime-clock-rtc-and-the-tamper-management-unit-tamp-with-stm32-microcontrollers-stmicroe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
Application Notes for related Tools & Software | https://www.st.com/resource/en/application_note/an4841-digital-signal-processing-for-stm32-microcontrollers-using-cmsis-stmicroelectronics.pdf
Application Notes for related Tools & Software | https://www.st.com/resource/en/application_note/an4891-stm32h72x-stm32h73x-and-singlecore-stm32h74x75x-system-architecture-and-performance-stmicroelectronics.pdf
Application Notes for related Tools & Software | https://www.st.com/resource/en/application_note/an5001-stm32cube-expansion-package-for-stm32h7-series-mdma-stmicroelectronics.pdf
Application Notes for related Tools & Software | https://www.st.com/resource/en/application_note/an5014-stm32h7x3-smart-power-management-expansion-package-for-stm32cube-stmicroelectronics.pdf
Application Notes for related Tools & Software | https://www.st.com/resource/en/application_note/an5033-stm32cube-mcu-package-examples-for-stm32h7-series-stmicroelectronics.pdf
Application Notes for related Tools & Software | https://www.st.com/resource/en/application_note/an5054-secure-programming-using-stm32cubeprogrammer-stmicroelectronics.pdf
Application Notes for related Tools & Software | https://www.st.com/resource/en/application_note/an5056-integration-guide-for-the-xcubesbsfu-stm32cube-expansion-package-stmicroelectronics.pdf
Application Notes for related Tools & Software | https://www.st.com/resource/en/application_note/an5360-getting-started-with-projects-based-on-the-stm32mp1-series-in-stm32cubeide-stmicroelectronics.pdf
Application Notes for related Tools & Software | https://www.st.com/resource/en/application_note/an5361-getting-started-with-projects-based-on-dualcore-stm32h7-microcontrollers-in-stm32cubeide-stmicroelectronics.pd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
Application Notes for related Tools & Software | https://www.st.com/resource/en/application_note/an5394-getting-started-with-projects-based-on-the-stm32l5-series-in-stm32cubeide-stmicroelectronics.pdf
Application Notes | https://www.st.com/resource/en/application_note/an5418-how-to-build-a-

for related Tools & Software | simple-usbpd-sink-application-with-stm32cubemx-stmicroelectronics.pdf
Application Notes for related Tools & Software | https://www.st.com/resource/en/application_note/an5426-migrating-graphics-middleware-projects-from-stm32cubemx-540-to-stm32cubemx-550-stmicroelectronics.pdf
Application Notes for related Tools & Software | https://www.st.com/resource/en/application_note/an5564-getting-started-with-projects-based-on-dualcore-stm32wl-microcontrollers-in-stm32cubeide-stmicroelectronics.pd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
Application Notes for related Tools & Software | https://www.st.com/resource/en/application_note/an4865-lowpower-timer-lptim-applicative-use-cases-on-stm32-mcus-and-mpus-stmicroelectronics.pdf
Application Notes for related Tools & Software | https://www.st.com/resource/en/application_note/an5698-adapting-the-xcubestl-functional-safety-package-for-stm32-iec-61508-compliant-to-other-safety-standards-stmicr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
Application Notes for related Tools & Software | https://www.st.com/resource/en/application_note/an5731-stm32cubemx-and-stm32cubeide-threadsafe-solution-stmicroelectronics.pdf
Application Notes for related Tools & Software | https://www.st.com/resource/en/application_note/an5450-stm32h7a37b3-lines-and-stm32h7b0-value-line-smart-power-management-expansion-package-for-stm32cube-stmicroelec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
Application Notes for related Tools & Software | https://www.st.com/resource/en/application_note/an4502-stm32-smbuspmbus-expansion-package-for-stm32cube-stmicroelectronics.pdf
Application Notes for related Tools & Software | https://www.st.com/resource/en/application_note/an5952-how-to-use-cmake-in-stm32cubeide-stmicroelectronics.pdf
Design Notes & Tips | https://www.st.com/resource/en/design_tip/dt0117-microphone-array-beamforming-in-the-pcm-and-pdm-domain-stmicroelectronics.pdf
Errata Sheets | https://www.st.com/resource/en/errata_sheet/es0392-stm32h742xig-stm32h743xig-stm32h750xb-stm32h753xi-device-errata-stmicroelectronics.pdf
Datasheet | https://www.st.com/resource/en/datasheet/dm00387108.pdf

## Programming Manuals

## https://www.st.com/resource/en/programming_manual/pm0253-stm32f7-series-and-stm32h7-series-cortexm7-processor-programming-manual-

| stmicroelectronics.pdf
Reference Manuals | https://www.st.com/resource/en/reference_manual/rm0433-stm32h742-stm32h743753-and-stm32h750-value-line-advanced-armbased-32bit-mcus-stmicroelectronics.pdf
Technical Notes & Articles | https://www.st.com/resource/en/technical_note/tn1163-description-of-wlcsp-for-microcontrollers-and-recommendations-for-its-use-stmicroelectronics.pdf
Technical Notes & Articles | https://www.st.com/resource/en/technical_note/tn1204-tape-and-reel-shipping-media-for-stm32-microcontrollers-in-bga-packages-stmicroelectronics.pdf
Technical Notes & Articles | https://www.st.com/resource/en/technical_note/tn1205-tape-and-reel-shipping-media-for-stm8-and-stm32-microcontrollers-in-fpn-packages-stmicroelectronics.pdf
Technical Notes & Articles | https://www.st.com/resource/en/technical_note/tn1206-tape-and-reel-shipping-media-for-stm8-and-stm32-microcontrollers-in-qfp-packages-stmicroelectronics.pdf
Technical Notes & Articles | https://www.st.com/resource/en/technical_note/tn1207-tape-and-reel-shipping-media-for-stm8-and-stm32-microcontrollers-in-so-packages-stmicroelectronics.pdf
Technical Notes & Articles | https://www.st.com/resource/en/technical_note/tn1208-tape-and-reel-shipping-media-for-stm8-and-stm32-microcontrollers-in-tssop-and-ssop-packages-stmicroelectronics.p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
Technical Notes & Articles | https://www.st.com/resource/en/technical_note/tn1433-reference-device-marking-schematics-for-stm32-microcontrollers-and-microprocessors-stmicroelectronics.pdf
Technical Notes & Articles | https://www.st.com/resource/en/technical_note/tn1489-security-bulletin-tn1489stpsirt-physical-attacks-on-stm32-and-stm32cube-firmware-stmicroelectronics.pdf
User Manuals | https://www.st.com/resource/en/user_manual/um2840-stm32h7-dualcore-series-safety-manual-stmicroelectronics.pdf
User Manuals | https://www.st.com/resource/en/user_manual/um2331-stm32h7-singlecore-series-safety-manual-stmicroelectronics.pdf

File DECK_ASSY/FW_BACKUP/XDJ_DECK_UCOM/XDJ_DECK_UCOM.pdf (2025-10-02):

## XDJ_DECK_UCOM Project Configuration Report

# 1. Description

## 1.1. Project

Project Name | XDJ_DECK_UCOM
Board Name | XDJ_DECK_UCOM
Generated with: | STM32CubeMX 4.25.1
Date | 06/14/2025

## 1.2. MCU

MCU Series | STM32F4
MCU Line | STM32F446
MCU name | STM32F446RETx
MCU Package | LQFP64
MCU Pin number | 64

# 2. Pinout Configuration

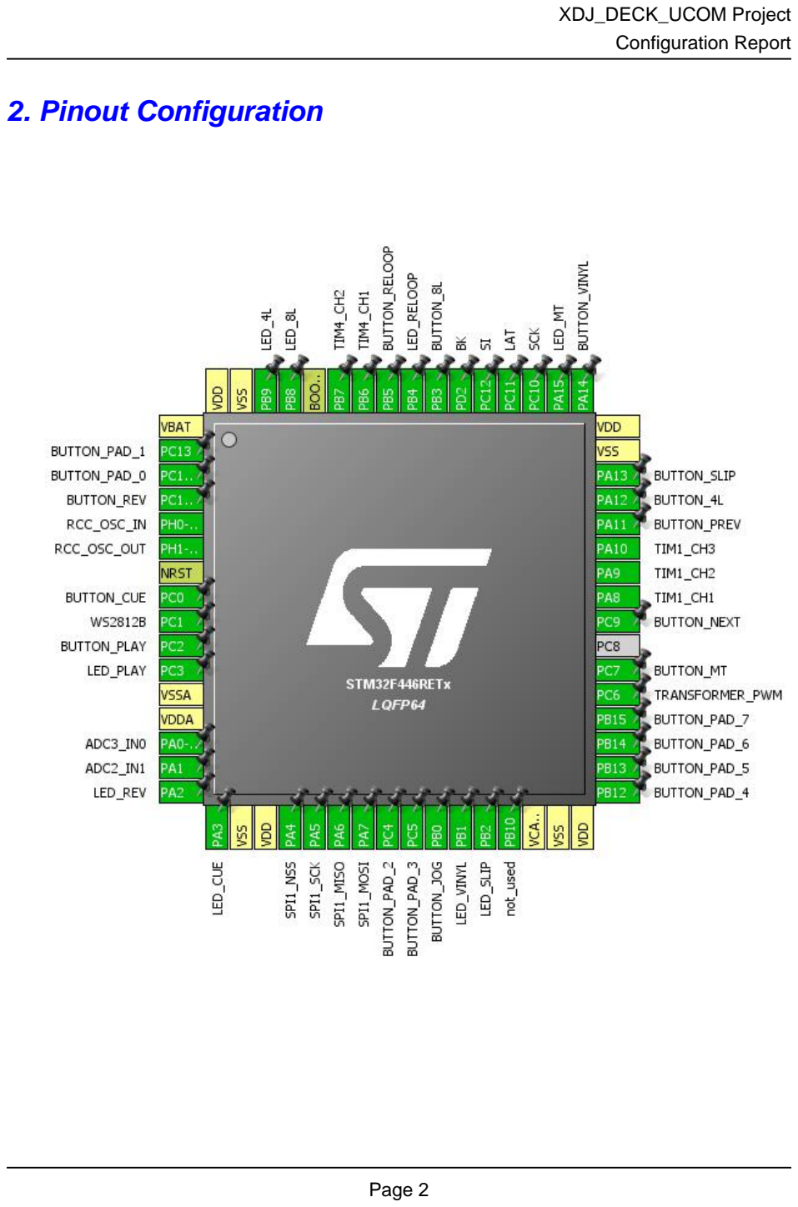
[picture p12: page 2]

# 3. Pins Configuration

Pin Number LQFP64 | Pin Name (function after reset) | Pin Type | Alternate Function(s) | Label
1 | VBAT | Power
2 | PC13 * | I/O | GPIO_Input | BUTTON_PAD_1
3 | PC14-OSC32_IN * | I/O | GPIO_Input | BUTTON_PAD_0
4 | PC15-OSC32_OUT * | I/O | GPIO_Input | BUTTON_REV
5 | PH0-OSC_IN | I/O | RCC_OSC_IN
6 | PH1-OSC_OUT | I/O | RCC_OSC_OUT
7 | NRST | Reset
8 | PC0 * | I/O | GPIO_Input | BUTTON_CUE
9 | PC1 | I/O | SPI2_MOSI | WS2812B
10 | PC2 * | I/O | GPIO_Input | BUTTON_PLAY
11 | PC3 * | I/O | GPIO_Output | LED_PLAY
12 | VSSA | Power
13 | VDDA | Power
14 | PA0-WKUP | I/O | ADC3_IN0
15 | PA1 | I/O | ADC2_IN1
16 | PA2 * | I/O | GPIO_Output | LED_REV
17 | PA3 * | I/O | GPIO_Output | LED_CUE
18 | VSS | Power
19 | VDD | Power
20 | PA4 | I/O | SPI1_NSS
21 | PA5 | I/O | SPI1_SCK
22 | PA6 | I/O | SPI1_MISO
23 | PA7 | I/O | SPI1_MOSI
24 | PC4 * | I/O | GPIO_Input | BUTTON_PAD_2
25 | PC5 * | I/O | GPIO_Input | BUTTON_PAD_3
26 | PB0 * | I/O | GPIO_Input | BUTTON_JOG
27 | PB1 * | I/O | GPIO_Output | LED_VINYL
28 | PB2 * | I/O | GPIO_Output | LED_SLIP
29 | PB10 | I/O | SPI2_SCK | not_used
30 | VCAP_1 | Power
31 | VSS | Power
32 | VDD | Power
33 | PB12 * | I/O | GPIO_Input | BUTTON_PAD_4
34 | PB13 * | I/O | GPIO_Input | BUTTON_PAD_5
35 | PB14 * | I/O | GPIO_Input | BUTTON_PAD_6
36 | PB15 * | I/O | GPIO_Input | BUTTON_PAD_7

Pin Number LQFP64 | Pin Name (function after reset) | Pin Type | Alternate Function(s) | Label
37 | PC6 | I/O | TIM3_CH1 | TRANSFORMER_PWM
38 | PC7 * | I/O | GPIO_Input | BUTTON_MT
40 | PC9 * | I/O | GPIO_Input | BUTTON_NEXT
41 | PA8 | I/O | TIM1_CH1
42 | PA9 | I/O | TIM1_CH2
43 | PA10 | I/O | TIM1_CH3
44 | PA11 * | I/O | GPIO_Input | BUTTON_PREV
45 | PA12 * | I/O | GPIO_Input | BUTTON_4L
46 | PA13 * | I/O | GPIO_Input | BUTTON_SLIP
47 | VSS | Power
48 | VDD | Power
49 | PA14 * | I/O | GPIO_Input | BUTTON_VINYL
50 | PA15 * | I/O | GPIO_Output | LED_MT
51 | PC10 | I/O | SPI3_SCK | SCK
52 | PC11 * | I/O | GPIO_Output | LAT
53 | PC12 | I/O | SPI3_MOSI | SI
54 | PD2 * | I/O | GPIO_Output | BK
55 | PB3 * | I/O | GPIO_Input | BUTTON_8L
56 | PB4 * | I/O | GPIO_Output | LED_RELOOP
57 | PB5 * | I/O | GPIO_Input | BUTTON_RELOOP
58 | PB6 | I/O | TIM4_CH1
59 | PB7 | I/O | TIM4_CH2
60 | BOOT0 | Boot
61 | PB8 * | I/O | GPIO_Output | LED_8L
62 | PB9 * | I/O | GPIO_Output | LED_4L
63 | VSS | Power
64 | VDD | Power

## * The pin is affected with an I/O function

# 4. Clock Tree Configuration

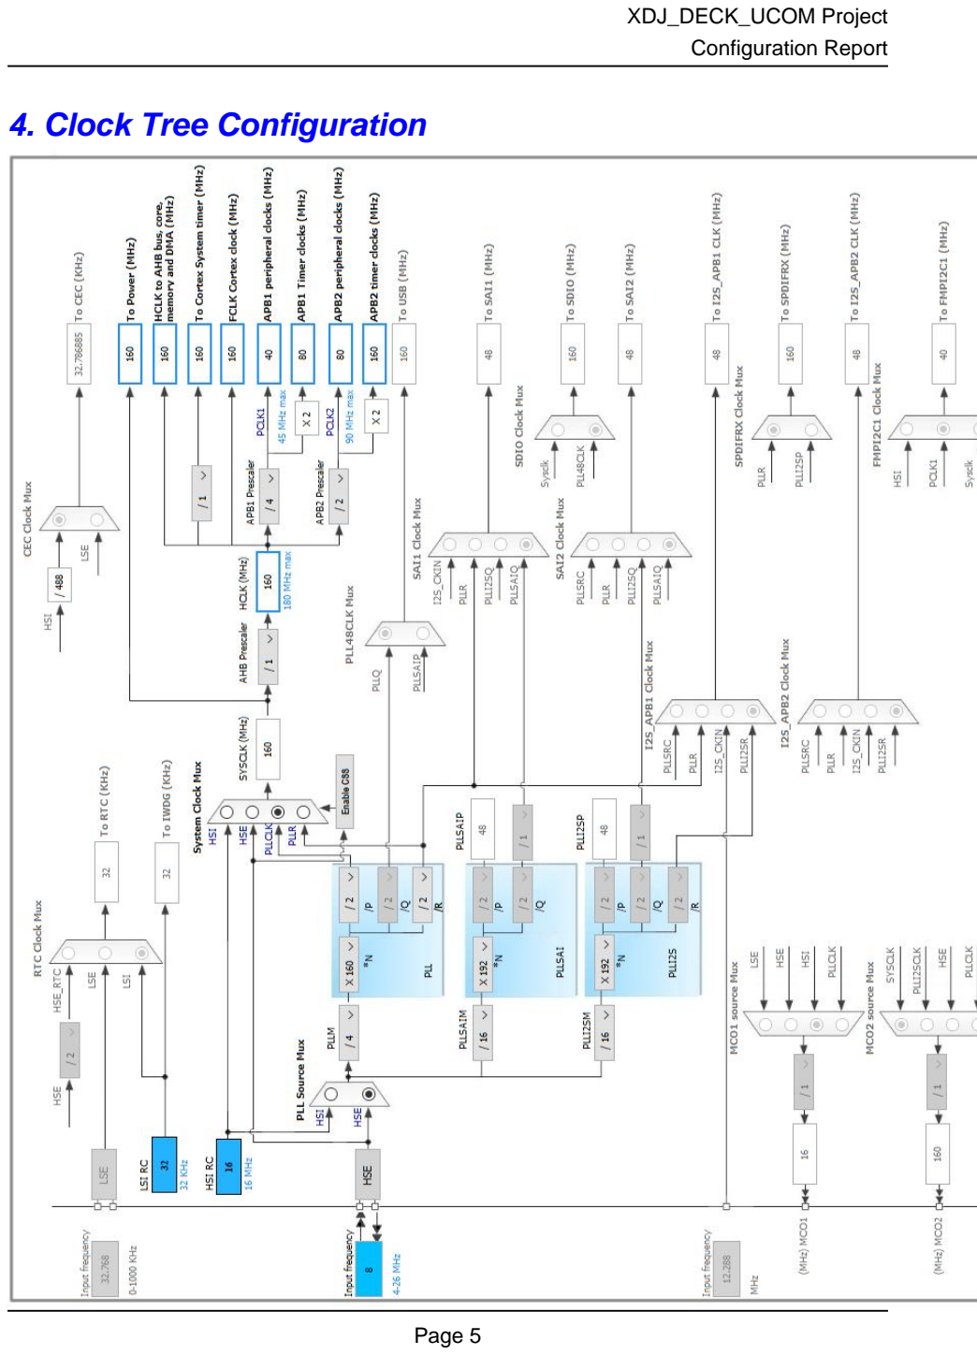
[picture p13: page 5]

# 5. IPs and Middleware Configuration

# 5.1. ADC1

## mode: Vrefint Channel

## 5.1.1. Parameter Settings:

### ADCs_Common_Settings:

Mode | Independent mode

### ADC_Settings:

Clock Prescaler | PCLK2 divided by 4
Resolution | 12 bits (15 ADC Clock cycles)
Data Alignment | Right alignment
Scan Conversion Mode | Disabled
Continuous Conversion Mode | Disabled
Discontinuous Conversion Mode | Disabled
DMA Continuous Requests | Disabled
End Of Conversion Selection | EOC flag at the end of single channel conversion

### ADC_Regular_ConversionMode:

Number Of Conversion | 1
External Trigger Conversion Source | Regular Conversion launched by software
External Trigger Conversion Edge | None
Rank | 1
Channel | Channel Vrefint
Sampling Time | 3 Cycles

### ADC_Injected_ConversionMode:

Number Of Conversions | 0

### WatchDog:

Enable Analog WatchDog Mode | false

# 5.2. ADC2

## mode: IN1

## 5.2.1. Parameter Settings:

### ADCs_Common_Settings:

Mode | Independent mode

### ADC_Settings:

Clock Prescaler | PCLK2 divided by 4
Resolution | 12 bits (15 ADC Clock cycles)
Data Alignment | Right alignment
Scan Conversion Mode | Disabled
Continuous Conversion Mode | Disabled
Discontinuous Conversion Mode | Disabled
DMA Continuous Requests | Disabled
End Of Conversion Selection | EOC flag at the end of single channel conversion

### ADC_Regular_ConversionMode:

Number Of Conversion | 1
External Trigger Conversion Source | Regular Conversion launched by software
External Trigger Conversion Edge | None
Rank | 1
Channel | Channel 1
Sampling Time | 3 Cycles

### ADC_Injected_ConversionMode:

Number Of Conversions | 0

### WatchDog:

Enable Analog WatchDog Mode | false

# 5.3. ADC3

## mode: IN0

## 5.3.1. Parameter Settings:

### ADCs_Common_Settings:

Mode | Independent mode

### ADC_Settings:

Clock Prescaler | PCLK2 divided by 4
Resolution | 12 bits (15 ADC Clock cycles)
Data Alignment | Right alignment
Scan Conversion Mode | Disabled
Continuous Conversion Mode | Disabled
Discontinuous Conversion Mode | Disabled
DMA Continuous Requests | Disabled
End Of Conversion Selection | EOC flag at the end of single channel conversion

### ADC_Regular_ConversionMode:

Number Of Conversion | 1
External Trigger Conversion Source | Regular Conversion launched by software
External Trigger Conversion Edge | None
Rank | 1
Channel | Channel 0
Sampling Time | 3 Cycles

### ADC_Injected_ConversionMode:

Number Of Conversions | 0

### WatchDog:

Enable Analog WatchDog Mode | false

# 5.4. RCC

## High Speed Clock (HSE): Crystal/Ceramic Resonator

## 5.4.1. Parameter Settings:

### System Parameters:

VDD voltage (V) | 3.3
Instruction Cache | Enabled
Prefetch Buffer | Enabled
Data Cache | Enabled
Flash Latency(WS) | 5 WS (6 CPU cycle)

### RCC Parameters:

HSI Calibration Value | 16
TIM Prescaler Selection | Disabled
HSE Startup Timout Value (ms) | 100
LSE Startup Timout Value (ms) | 5000

### Power Parameters:

Power Regulatror Voltage Scale | Power Regulator Voltage Scale 1
Power Over Drive | Disabled

# 5.5. SPI1

## Mode: Full-Duplex Slave Hardware NSS Signal: Hardware NSS Input Signal

## 5.5.1. Parameter Settings:

### Basic Parameters:

Frame Format | Motorola
Data Size | 8 Bits
First Bit | MSB First

### Clock Parameters:

Clock Polarity (CPOL) | High *
Clock Phase (CPHA) | 1 Edge

### Advanced Parameters:

CRC Calculation | Disabled
NSS Signal Type | Input Hardware

# 5.6. SPI2

## Mode: Transmit Only Master

## 5.6.1. Parameter Settings:

### Basic Parameters:

Frame Format | Motorola
Data Size | 8 Bits
First Bit | MSB First

### Clock Parameters:

Prescaler (for Baud Rate) | 16 *
Baud Rate | 2.5 MBits/s *
Clock Polarity (CPOL) | Low
Clock Phase (CPHA) | 1 Edge

### Advanced Parameters:

CRC Calculation | Disabled
NSS Signal Type | Software

# 5.7. SPI3

## Mode: Transmit Only Master

## 5.7.1. Parameter Settings:

### Basic Parameters:

Frame Format | Motorola
Data Size | 8 Bits
First Bit | MSB First

### Clock Parameters:

Prescaler (for Baud Rate) | 16 *
Baud Rate | 2.5 MBits/s *
Clock Polarity (CPOL) | Low
Clock Phase (CPHA) | 1 Edge

### Advanced Parameters:

CRC Calculation | Disabled
NSS Signal Type | Software

# 5.8. SYS

## Timebase Source: SysTick

# 5.9. TIM1

## Clock Source : Internal Clock Channel1: PWM Generation CH1 Channel2: PWM Generation CH2 Channel3: PWM Generation CH3

## 5.9.1. Parameter Settings:

### Counter Settings:

Prescaler (PSC - 16 bits value) | 639 *
Counter Mode | Up
Counter Period (AutoReload Register - 16 bits value ) | 255 *
Internal Clock Division (CKD) | Division by 2 *
Repetition Counter (RCR - 8 bits value) | 0

### Trigger Output (TRGO) Parameters:

Master/Slave Mode (MSM bit) | Disable (Trigger input effect not delayed)
Trigger Event Selection | Reset (UG bit from TIMx_EGR)

### Break And Dead Time management - BRK Configuration:

BRK State | Disable
BRK Polarity | High

### Break And Dead Time management - Output Configuration:

Automatic Output State | Disable

Off State Selection for Run Mode (OSSR) | Disable
Off State Selection for Idle Mode (OSSI) | Disable
Lock Configuration | Off

### PWM Generation Channel 1:

Mode | PWM mode 1
Pulse (16 bits value) | 0
Fast Mode | Disable
CH Polarity | High
CH Idle State | Reset

### PWM Generation Channel 2:

Mode | PWM mode 1
Pulse (16 bits value) | 0
Fast Mode | Disable
CH Polarity | High
CH Idle State | Reset

### PWM Generation Channel 3:

Mode | PWM mode 1
Pulse (16 bits value) | 0
Fast Mode | Disable
CH Polarity | High
CH Idle State | Reset

# 5.10. TIM2

## Clock Source : Internal Clock

## 5.10.1. Parameter Settings:

### Counter Settings:

Prescaler (PSC - 16 bits value) | 19 *
Counter Mode | Up
Counter Period (AutoReload Register - 32 bits value ) | 0xFFFFFFFF *
Internal Clock Division (CKD) | Division by 4 *

### Trigger Output (TRGO) Parameters:

Master/Slave Mode (MSM bit) | Disable (Trigger input effect not delayed)
Trigger Event Selection | Reset (UG bit from TIMx_EGR)

# 5.11. TIM3

## Clock Source : Internal Clock Channel1: PWM Generation CH1

## 5.11.1. Parameter Settings:

### Counter Settings:

Prescaler (PSC - 16 bits value) | 4 *
Counter Mode | Up
Counter Period (AutoReload Register - 16 bits value ) | 159 *
Internal Clock Division (CKD) | No Division

### Trigger Output (TRGO) Parameters:

Master/Slave Mode (MSM bit) | Disable (Trigger input effect not delayed)
Trigger Event Selection | Reset (UG bit from TIMx_EGR)

### PWM Generation Channel 1:

Mode | PWM mode 1
Pulse (16 bits value) | 0
Fast Mode | Disable
CH Polarity | High

# 5.12. TIM4

## Combined Channels: Encoder Mode

## 5.12.1. Parameter Settings:

### Counter Settings:

Prescaler (PSC - 16 bits value) | 0
Counter Mode | Up
Counter Period (AutoReload Register - 16 bits value ) | 0xFFFF *
Internal Clock Division (CKD) | No Division

### Trigger Output (TRGO) Parameters:

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

### Encoder:

Encoder Mode | Encoder Mode TI1 and TI2 *

____ Parameters for Channel 1 ____
Polarity | Falling Edge *

IC Selection | Direct
Prescaler Division Ratio | No division
Input Filter | 14 *

____ Parameters for Channel 2 ____
Polarity | Falling Edge *
IC Selection | Direct
Prescaler Division Ratio | No division
Input Filter | 14 *

# 5.13. TIM5

## mode: Clock Source

## 5.13.1. Parameter Settings:

### Counter Settings:

Prescaler (PSC - 16 bits value) | 7 *
Counter Mode | Up
Counter Period (AutoReload Register - 32 bits value ) | 1900 *
Internal Clock Division (CKD) | Division by 2 *

### Trigger Output (TRGO) Parameters:

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

### * User modified value

# 6. System Configuration
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

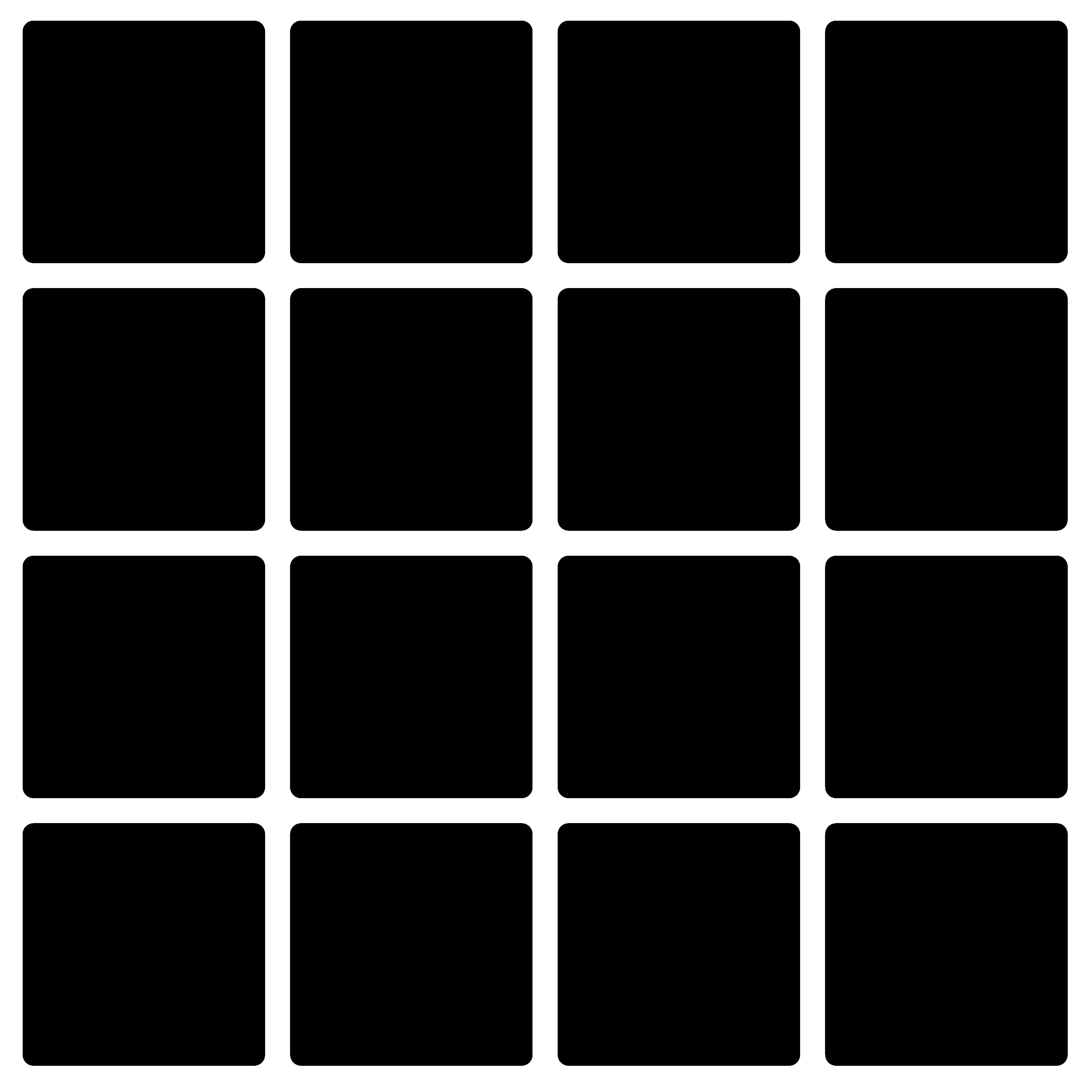
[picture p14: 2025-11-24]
Body Design/CNC/PADS16/pads16_900.bmp

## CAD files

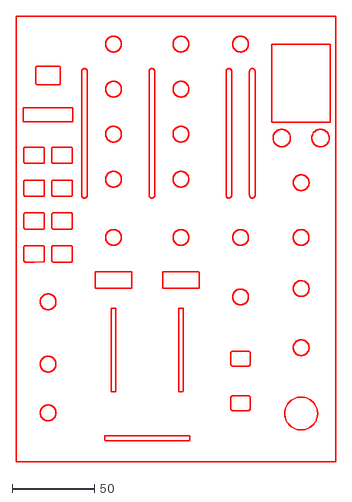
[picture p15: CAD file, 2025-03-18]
Mixer assy/Mixer_assy_cut_all.dxf
194.4 x 270.9

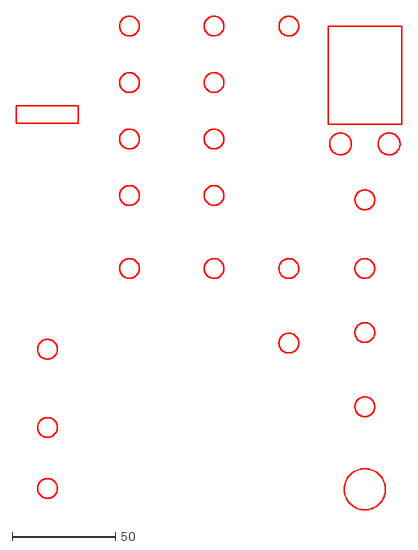
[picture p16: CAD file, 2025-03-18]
Mixer assy/Mixer_assy_cut_filthy.dxf
186.8 x 239.5

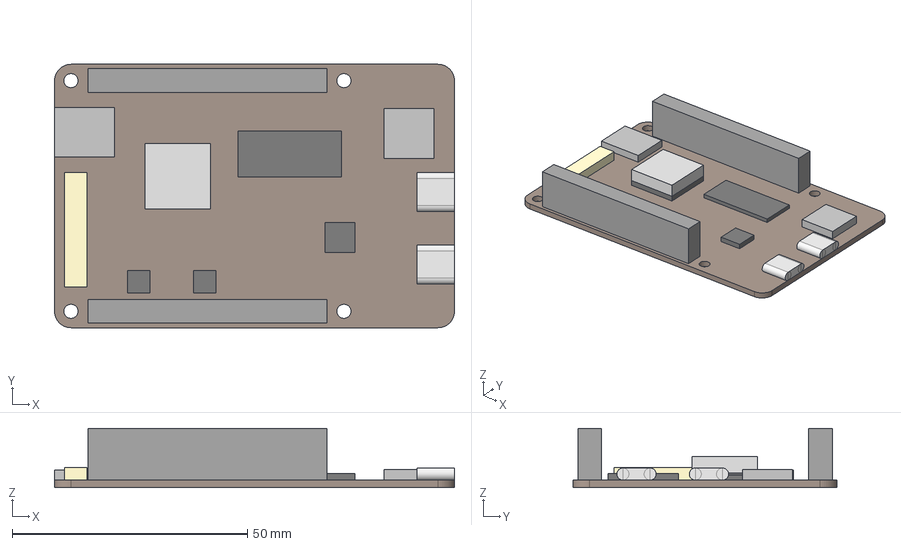
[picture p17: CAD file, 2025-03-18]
Body Design/3d model/RT-Tread_assy.FCStd
85.0 x 56.0 x 12.6 mm
PCB
PIN_HEADERS
stm
sdram
st_LINK
SPI
RGB_CONN
SPI002
AP6212
microSD
USB_C
USB_C001
heatsinc

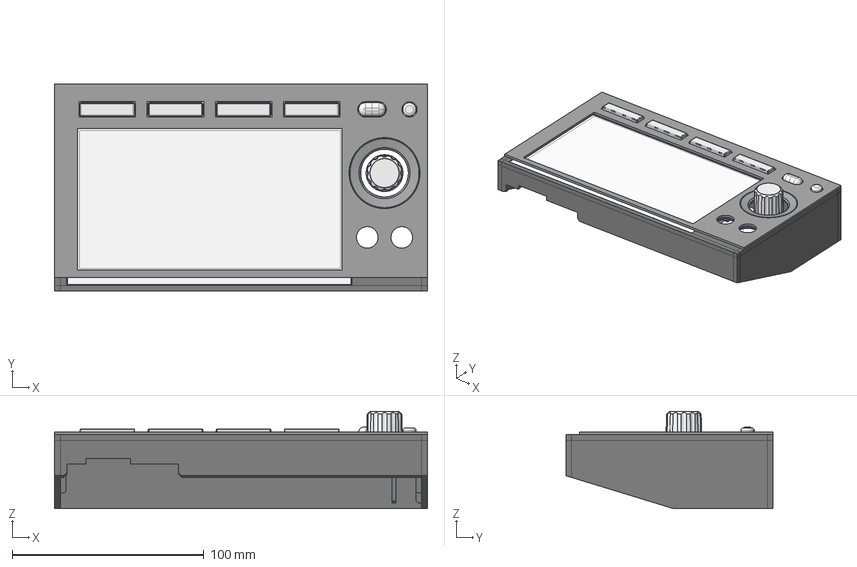
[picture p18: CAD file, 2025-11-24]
Body Design/3d model/Display_module.FCStd
194.4 x 108.0 x 50.6 mm
TFT_common
Encoder_ring
KNOB
plex002
back_b001
tag_b
4 buttons
3d_print

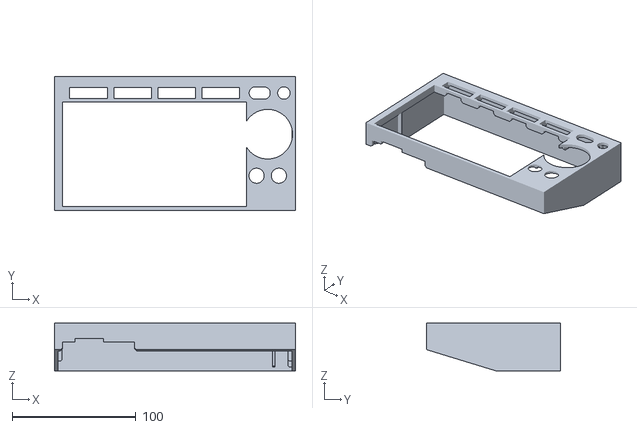
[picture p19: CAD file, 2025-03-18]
Body Design/3d model/print out/Display_module.stl
194.4 x 108.0 x 38.5

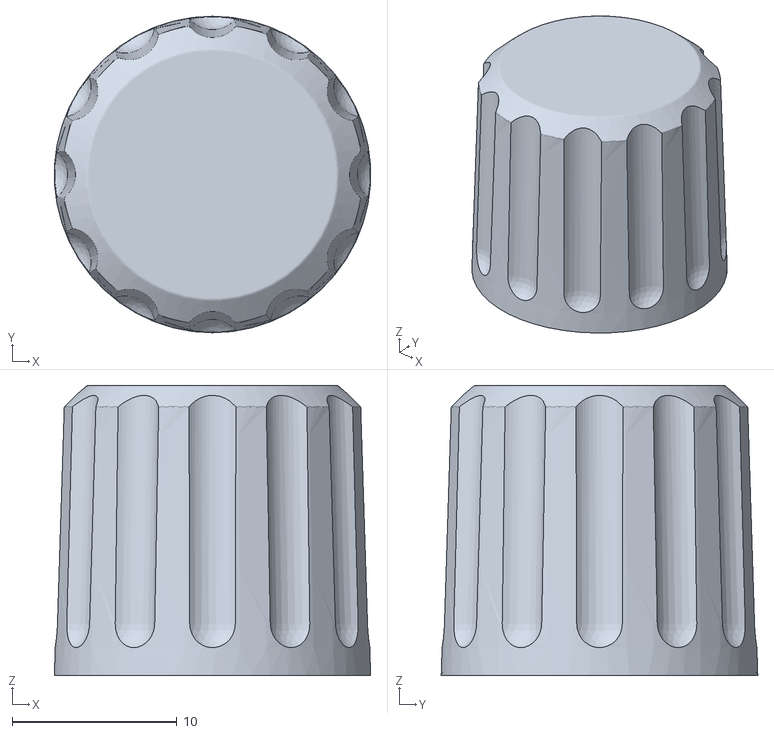
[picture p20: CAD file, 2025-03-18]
Body Design/Knob/knob_print.stl
19.2 x 19.2 x 17.6

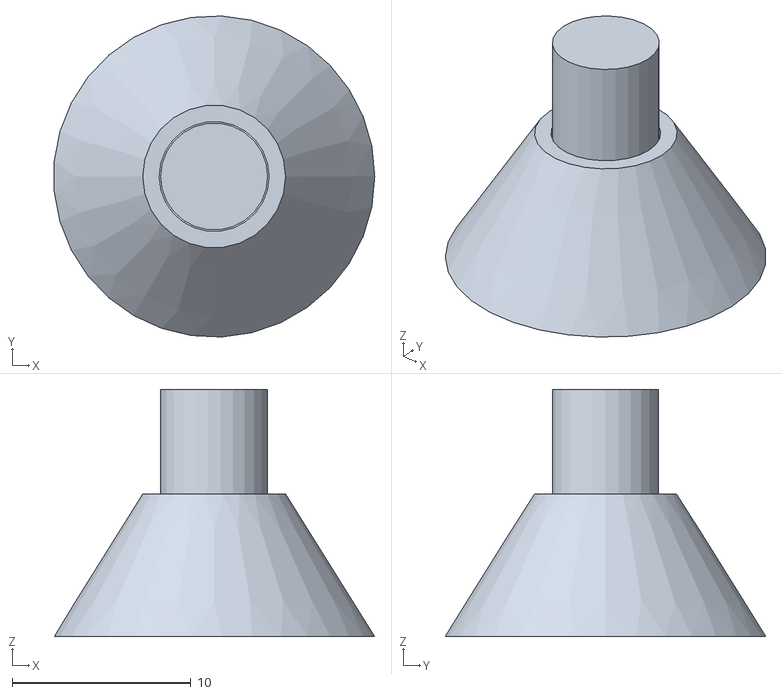
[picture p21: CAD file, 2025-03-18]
Mixer assy/3D/pillar_for_system_only.stl
18.0 x 18.0 x 13.9

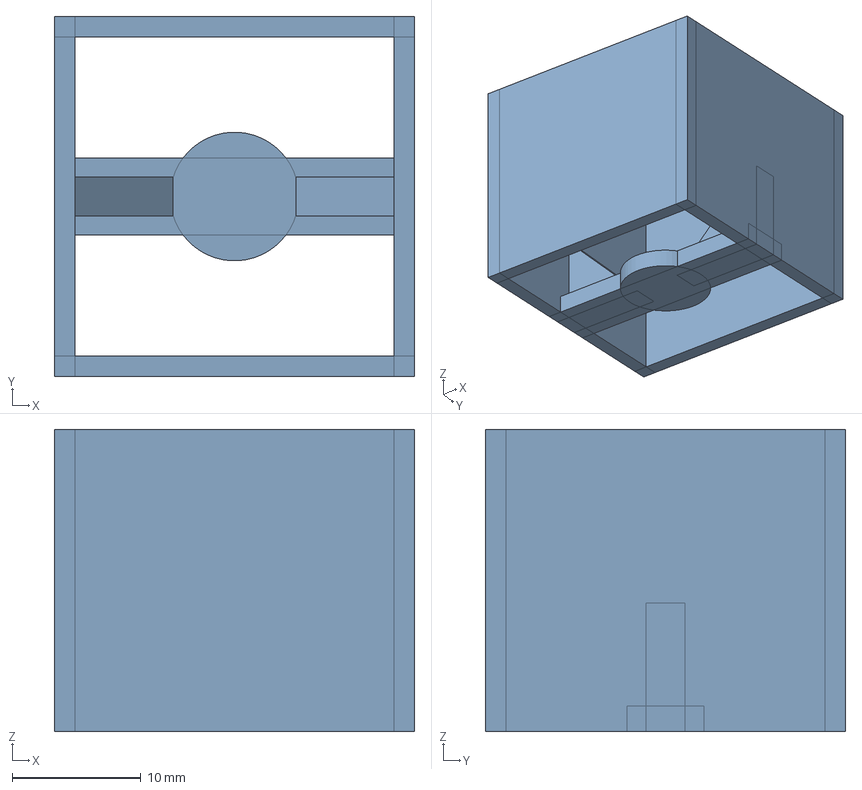
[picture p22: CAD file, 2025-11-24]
PADS 3D/pad_actuator.FCStd
28.0 x 28.0 x 23.5 mm

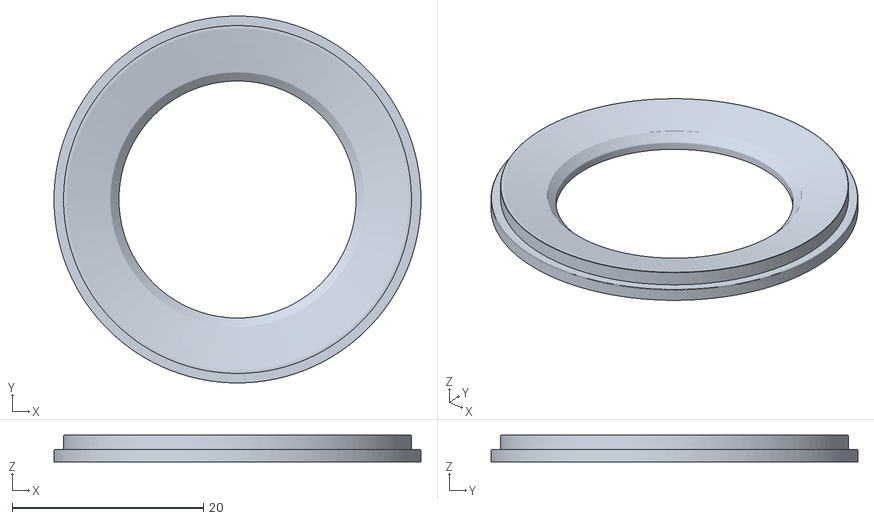
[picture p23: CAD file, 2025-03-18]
Body Design/3d model/print out/Encoder_ring.stl
38.4 x 38.4 x 2.80

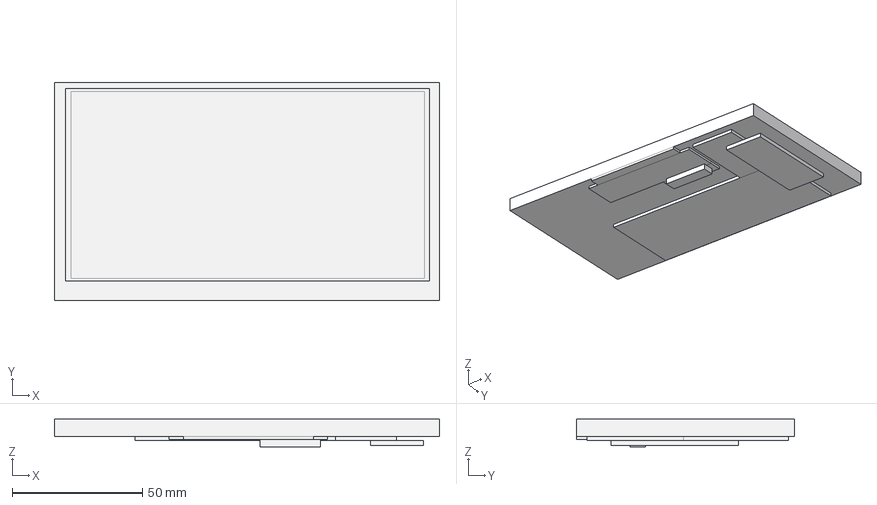
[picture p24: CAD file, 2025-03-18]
Body Design/3d model/TFT.FCStd
148.0 x 83.7 x 10.6 mm

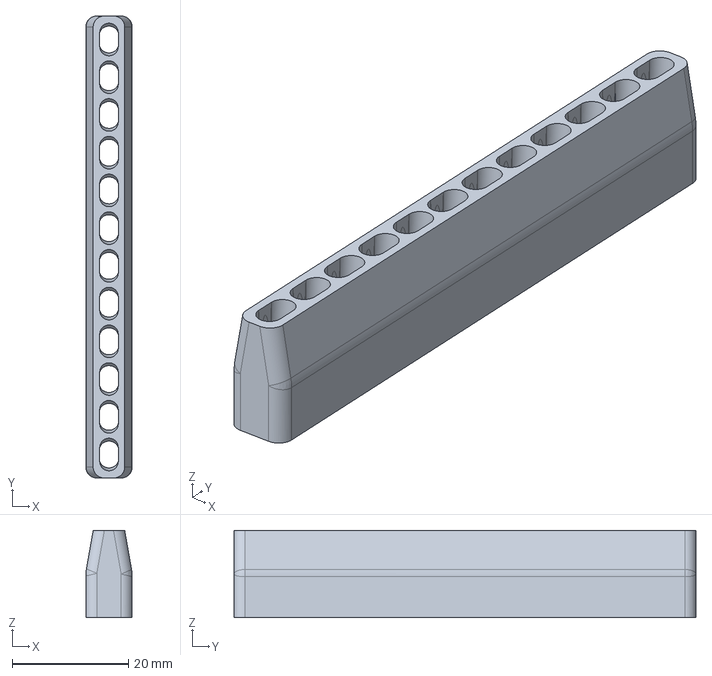
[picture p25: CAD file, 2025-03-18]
Mixer assy/3D/Leveler.FCStd
8.00 x 79.6 x 15.0 mm

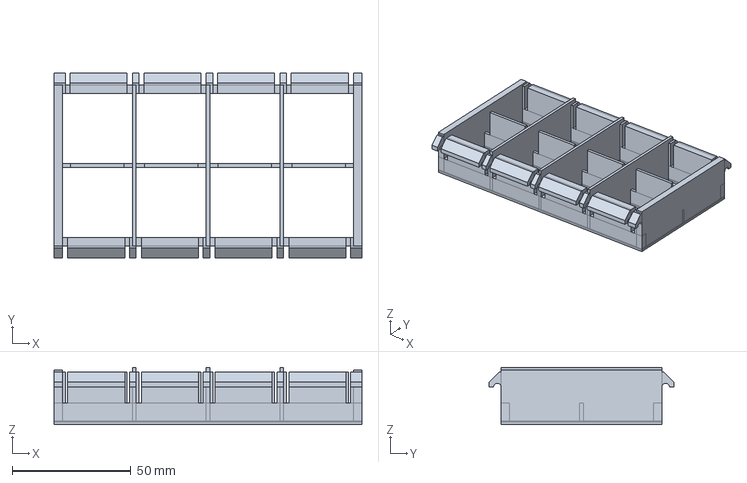
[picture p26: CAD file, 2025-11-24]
PADS 3D/PADSv2.FCStd
129.5 x 77.7 x 24.0 mm

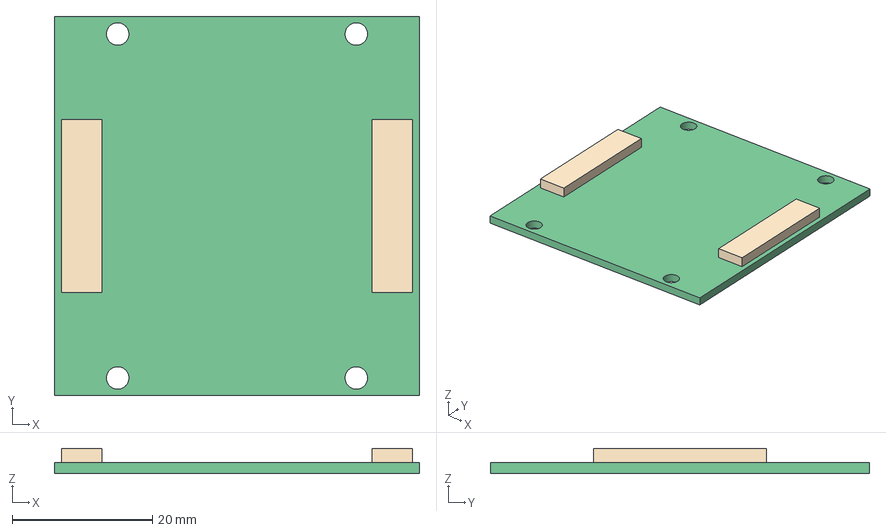
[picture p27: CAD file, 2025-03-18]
Body Design/3d model/rgb_pcb.FCStd
52.0 x 54.0 x 3.60 mm
pcb001
conn002

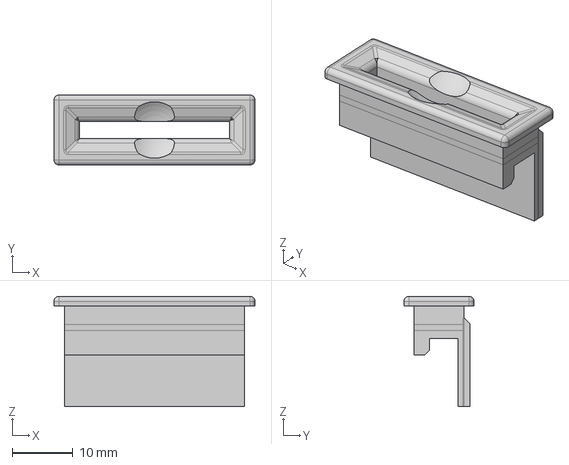
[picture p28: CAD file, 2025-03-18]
Mixer assy/3D/SD_holder.FCStd
33.0 x 11.5 x 18.1 mm

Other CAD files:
Body Design/Knob/knob_edit24.FCStd
Body Design/Knob/knob.FCStd
PADS 3D/PADS_DETAIL_2.stl
Body Design/3d model/Encoder_ring.FCStd
Body Design/3d model/TFT.stl
Body Design/Knob/knob_edit24.stl
Mixer assy/3D/Leveler.stl
Mixer assy/3D/SD_holder.stl
Mixer assy/3D/handler.FCStd
Mixer assy/3D/handler.stl
Mixer assy/3D/pillar.FCStd
Mixer assy/3D/pillar.stl
PADS 3D/PADS.FCStd
PADS 3D/PADS_DETAIL_1.stl

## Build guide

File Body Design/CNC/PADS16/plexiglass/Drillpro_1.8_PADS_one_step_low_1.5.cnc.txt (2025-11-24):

%
G90
G49
M3 S130
G0 X5.690 Y-32.215 Z2.000
G1   Z-1.650 F4
G1 X5.734 Y-32.221  F6
X5.778 Y-32.224 
X5.821 Y-32.226 
X8.232 Y-32.243 
X27.279 Y-32.245 
X31.309 Y-32.223 
X31.358 Y-32.221 
X31.407 Y-32.217 
X31.456 Y-32.210 
X31.504 Y-32.201 
X31.551 Y-32.188 
X31.660 Y-32.158 
X31.769 Y-32.125 
X31.815 Y-32.108 
X31.859 Y-32.088 
X32.102 Y-31.974 
X32.151 Y-31.949 
X32.198 Y-31.920 
X32.244 Y-31.889 
X32.463 Y-31.732 
X32.506 Y-31.699 
X32.546 Y-31.663 
X32.585 Y-31.626 
X32.772 Y-31.431 
X32.809 Y-31.390 
X32.843 Y-31.348 
X32.875 Y-31.303 
X33.024 Y-31.077 
X33.054 Y-31.028 
X33.081 Y-30.977 
X33.105 Y-30.924 
X33.245 Y-30.583 
X33.266 Y-30.528 
X33.283 Y-30.472 
X33.296 Y-30.415 
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
%

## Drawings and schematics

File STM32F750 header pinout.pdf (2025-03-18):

## SPI1_SCK (PG11)

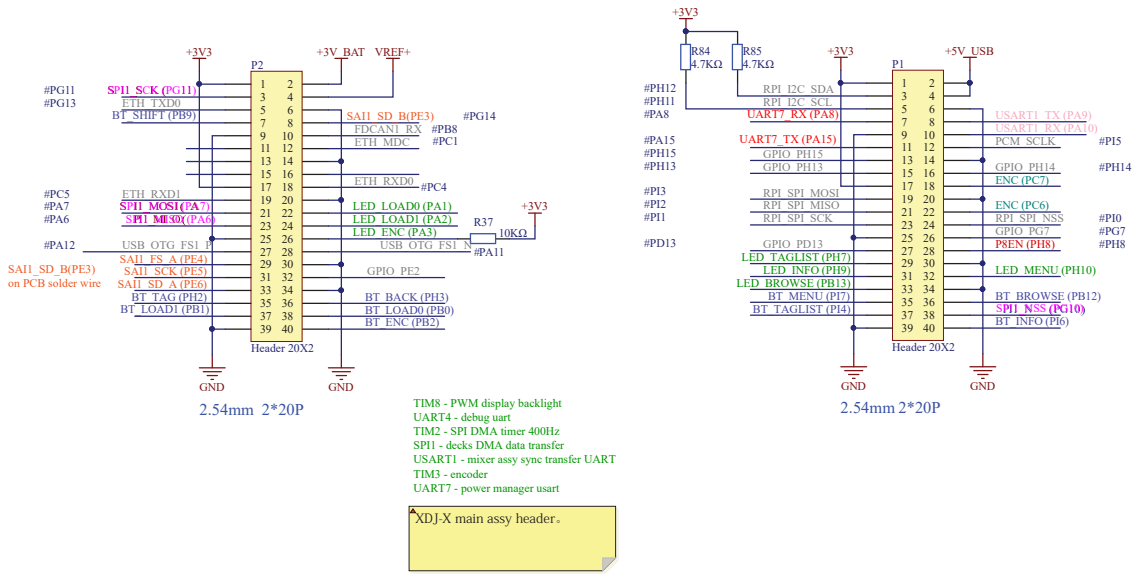
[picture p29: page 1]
Header 20X2; +5V_USB; GND; ETH_MDC; ETH_RXD0; ETH_RXD1; - ETH_TXD0; +3V_BAT; FDCAN1_RX; BT_SHIFT (PB9); UART7_RX (PA8); RPI_SPI_NSS; RPI_SPI_MOSI RPI_SPI_MISO RPI_SPI_SCK; BT_TAGLIST (PI4); PCM_SCLK; BT_MENU (PI7);  BT_INFO (PI6); RPI_I2C_SCL; RPI_I2C_SDA; USART1_TX (PA9) USART1_RX (PA10); BT_BROWSE (PB12); LED_BROWSE (PB13); GPIO_PH15; GPIO_PH13; GPIO_PH14; GPIO_PG7; ENC (PC6); LED_INFO (PH9); LED_MENU (PH10); LED_TAGLIST (PH7); UART7_TX (PA15); GPIO_PD13; ENC (PC7); VREF+; USB_OTG_FS1_P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

SAI1_SD_B(PE3)
on PCB solder wire

TIM8 - PWM display backlight
UART4 - debug uart
TIM2 - SPI DMA timer 400Hz
SPI1 - decks DMA data transfer
USART1 - mixer assy sync transfer UART
TIM3 - encoder
UART7 - power manager usart
XDJ-X main assy header

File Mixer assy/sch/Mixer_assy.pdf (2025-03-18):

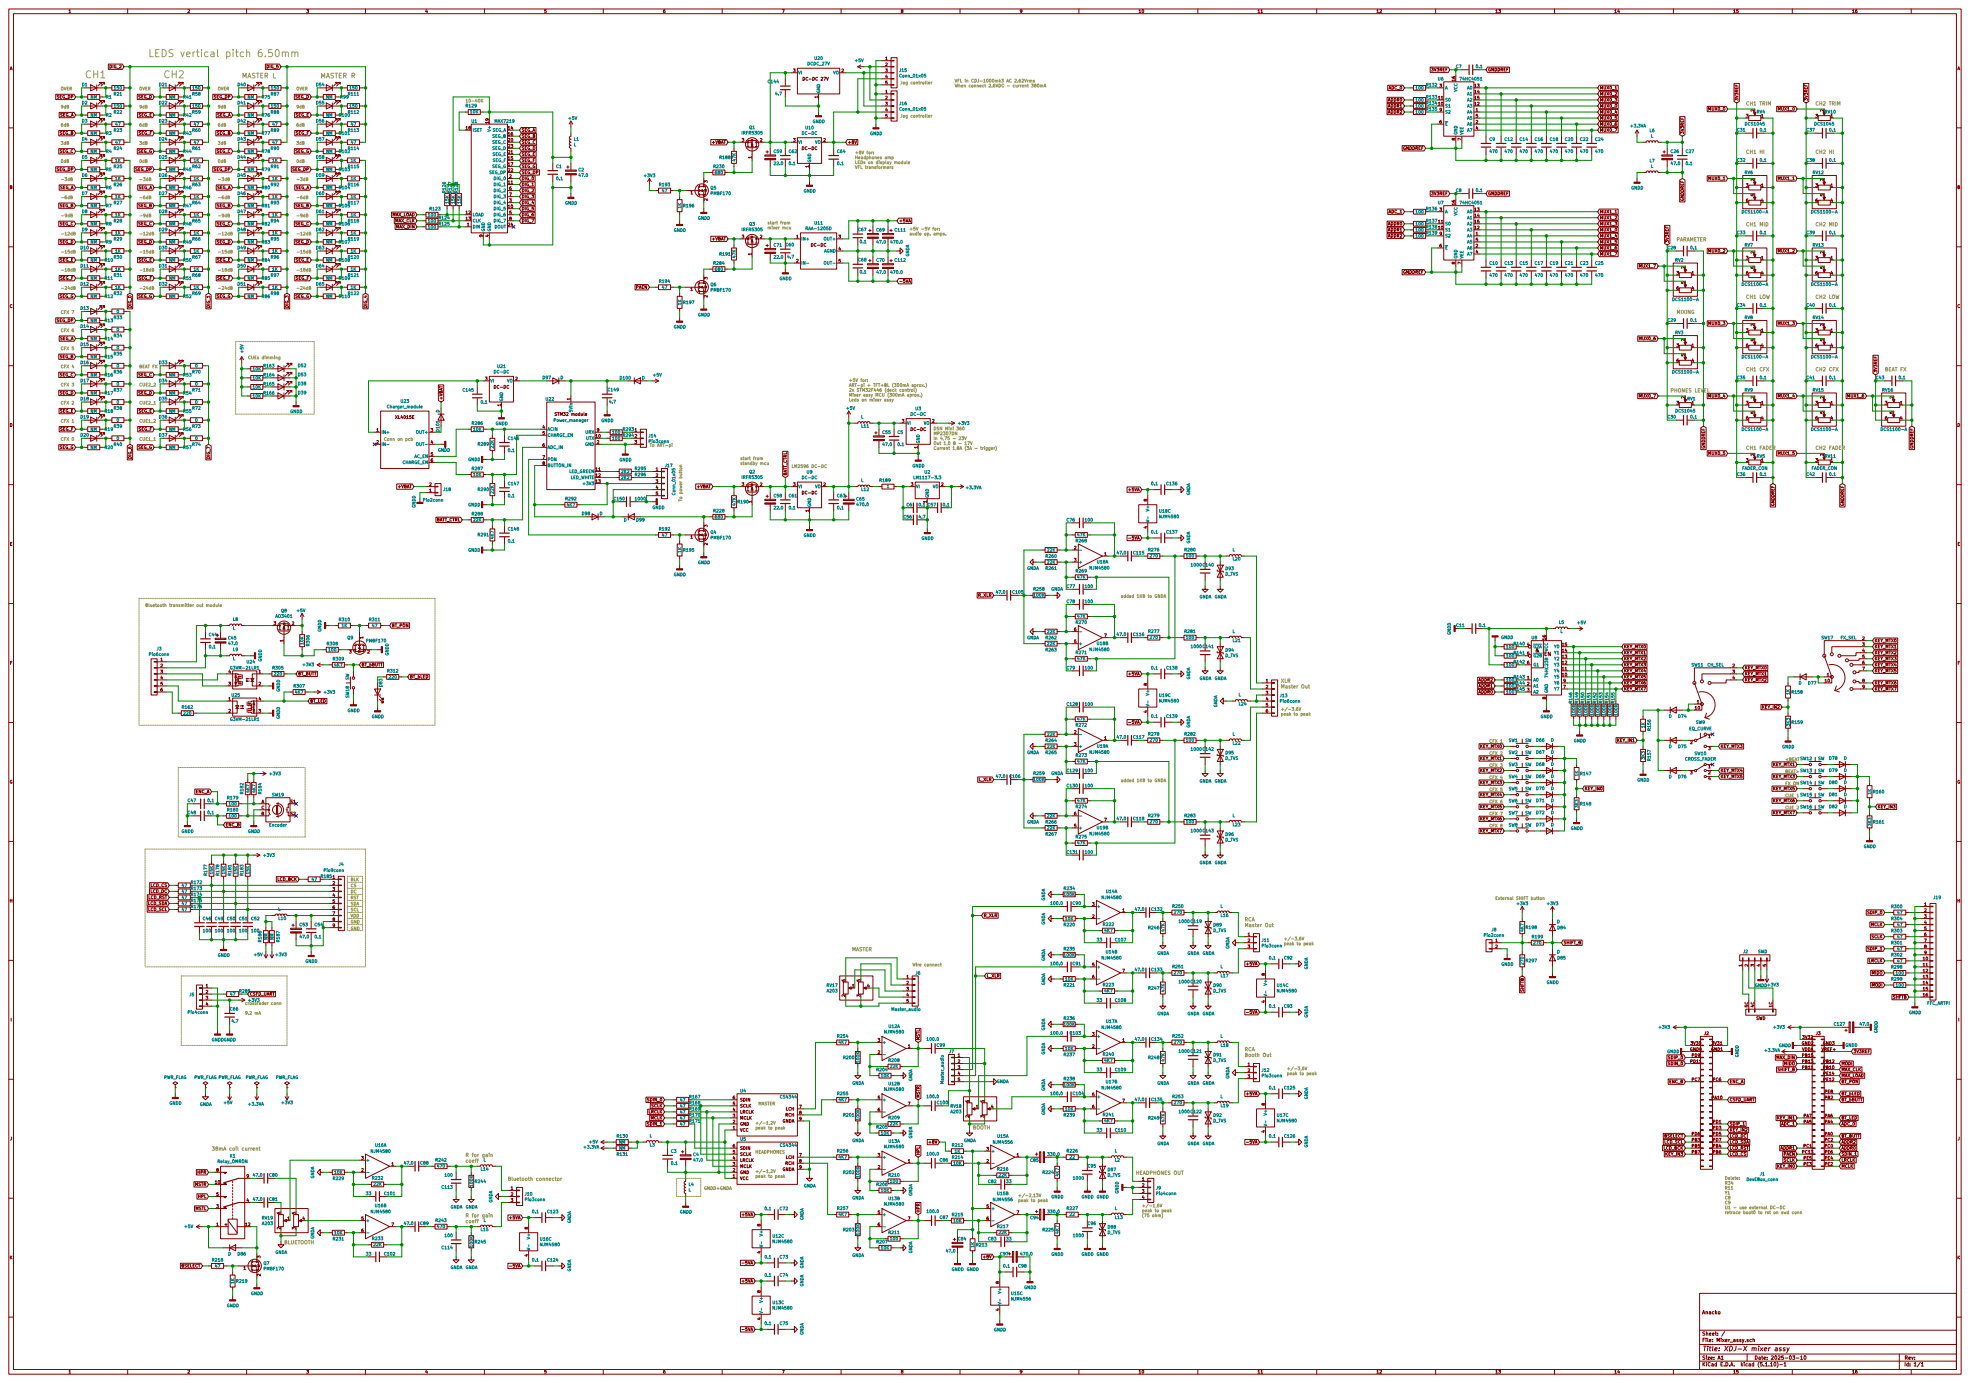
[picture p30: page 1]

LEDs on display module VFL transformers MASTER R

VFL in CDJ-1000mk3 AC 2.62Vrms When connect 2.6VDC - current 380mA

1 VO 2 VI 3 U10 DC-DC GNDD

start from mixer mcu

+5V for: ART-pi + TFT+BL (300mA aprox.)

2x STM32F446 (deck control)
Mixer assy MCU (300mA aprox.)
Leds on mixer assy

In 4,75 - 23V Out 1,0 - 17V Current 1,8A (3A - trigger) Bluetooth transmitter out module
SEG_G

start from standby mcu

CFX 4 To power button

1 VO 2 VI 3 U9 DC-DC GNDD

Delete: R34 R11 Y1C8 C9 U1 - use external DC-DC

retrace boot0 to rst on swd conn

File: Mixer_assy.sch Sheet: / Anacko

Id: 1/1 Title: XDJ-X mixer assy

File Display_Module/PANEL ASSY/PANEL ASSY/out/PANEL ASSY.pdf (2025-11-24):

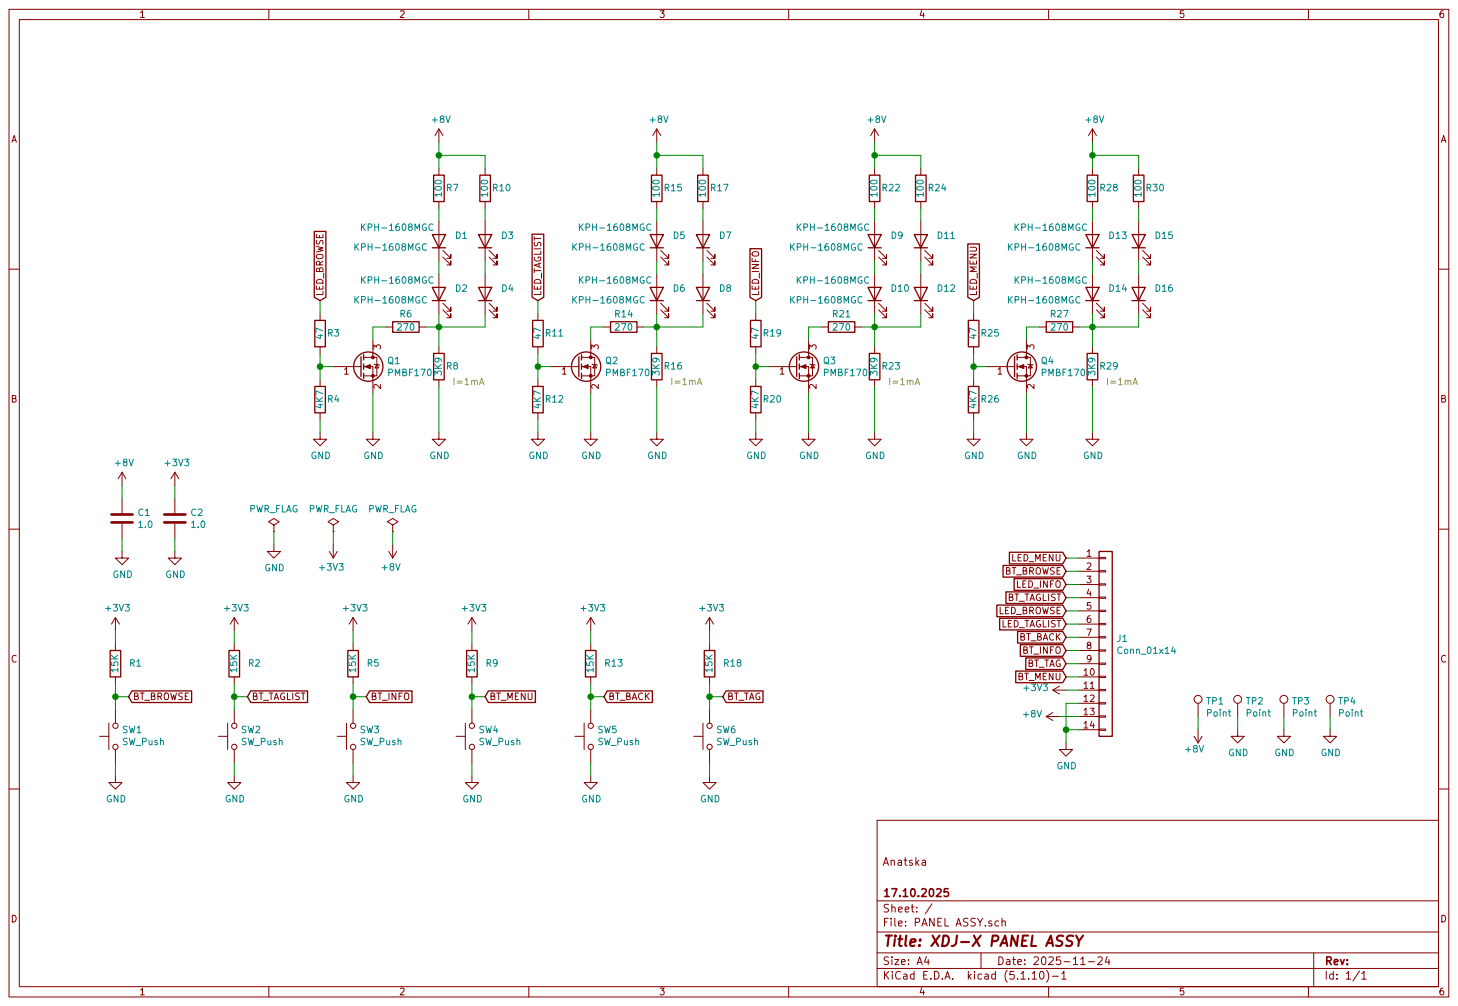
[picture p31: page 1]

Id: 1/1 Title: XDJ-X PANEL ASSY

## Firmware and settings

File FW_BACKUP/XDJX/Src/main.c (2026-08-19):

/* USER CODE BEGIN Header */
/**
  ******************************************************************************
  * @file           : main.c
  * @brief          : Main program body
  ******************************************************************************
  * @attention
  *
  * Copyright (c) 2023 STMicroelectronics.
  * All rights reserved.
  *
  * This software is licensed under terms that can be found in the LICENSE file
  * in the root directory of this software component.
  * If no LICENSE file comes with this software, it is provided AS-IS.
  *
  ******************************************************************************
  */
	
/////////////////////////////////////////////////////////////////////////////////////////////////////////////
//
//		Product: XDJ-X main assy
//
//		Generated with: STM32CubeMX 6.10.0
//		Firmware Package Name and Version STM32Cube FW_H7 V1.11.1
//
//		After regenerate code:
//
//		replace file fmc.c
//		replace file \Drivers\STM32H7xx_HAL_Driver\Src\stm32h7xx_hal_dma2d.c
//		replace file \Drivers\STM32H7xx_HAL_Driver\Src\stm32h7xx_hal_dma2d.h
//		replace file \Src\fatfs_platform.c
//		replace file \Drivers\STM32H7xx_HAL_Driver\Src\stm32h7xx_hal_dma.c  !!!modify file
//		replace file \Src\ltdc.c
//
//		file main.c:
//				//  /* Enables the MPU */
//					//HAL_MPU_Enable(MPU_HFNMI_PRIVDEF);
//
//
//					MPU_InitStruct.Enable = MPU_REGION_ENABLE;
//					MPU_InitStruct.Number = MPU_REGION_NUMBER1;
//					MPU_InitStruct.BaseAddress = 0x90000000;
//					MPU_InitStruct.Size = MPU_REGION_SIZE_8MB;
//					MPU_InitStruct.SubRegionDisable = 0x0;
//					MPU_InitStruct.TypeExtField = MPU_TEX_LEVEL0;
//					MPU_InitStruct.AccessPermission = MPU_REGION_FULL_ACCESS;
//					MPU_InitStruct.DisableExec = MPU_INSTRUCTION_ACCESS_ENABLE;
//					MPU_InitStruct.IsShareable = MPU_ACCESS_SHAREABLE;
//					MPU_InitStruct.IsCacheable = MPU_ACCESS_CACHEABLE;
//					MPU_InitStruct.IsBufferable = MPU_ACCESS_BUFFERABLE;
//
//					HAL_MPU_ConfigRegion(&MPU_InitStruct);
//
//					/** Initializes and configures the Region and the memory to be protected
//					*/
//					HAL_MPU_ConfigRegion(&MPU_InitStruct);
//					/* Enables the MPU */
//					HAL_MPU_Enable(MPU_HFNMI_PRIVDEF);
//
//
//
//
//
//		TIM8 - PWM display backlight
//		UART4 - debug uart
//		TIM2 - SPI DMA timer 400Hz
//		SPI1 - SPI EEPROM onboard
//		SPI2 - decks DMA data transfer
//		USART1 - mixer assy sync transfer UART
//		TIM3 - encoder
//		UART7 - power manager usart
//
//
//
//
//////////////////////////////////////////////////////////////////////////////////////////////////////////////
//	
//	ver. 0.1
//		- start ltdc
//	ver. 0.15
//		- added display 233*480
//	ver. 0.17
//	ver. 0.19
//		- work with CWX3970
//	ver. 0.23
//		- improved lcd lib to 233 pixels
//	ver. 0.25
//		- improved lcd lib
//	ver. 0.27
//		-	added SDIO and SAI1
//	ver. 0.29
//		- improved lcd lib (inverted signal pixel clock)
//		- added pwm backlight control
//	ver. 0.30
//		-	SAI pins remaped
//		-	add test dynamic waveform
//	ver. 0.33
//		-	improved DMA2D functions and productivity
//		-	added memcpy for waveform layer frame
//		-	Changed file stm32h7xx_hal_dma2d.c
//	ver. 0.35
//		-	added DMA framebuffer tranfer
//		-	added 14D font
//	ver. 0.36
//		- changed dynamic wf to 18-1-18 amplitude
//	ver. 0.37
//		-	added global_variables.h
//		-	added audio.h
//		-	added audio_handler.h
//	ver. 0.40
//		- regenerated code
//		- SAI switched to slave mode, 2 lines data
//		- added buttons and leds init
//		- added encoder timer init
//		-	added usart for power manager
//		- added SPI DMA init
//		- added SPI timer 400hz
//		- added SPI for EEPROM
//		- added QSPI
//	ver. 0.44
//		-	audio transfer starting
//		-	DMA deck transfer staring
//	ver. 0.45
//		-	added Power manager uart handler 
//		-	added Debug uart handler 
//		-	added Mixer uart handler
//	ver. 0.46
//		-	added SPI DMA packages
//	ver. 0.47
//		-	SPI DMA changes
//	ver. 0.49
//		- fixed SPI DMA: deckRbuf and deckTbuf added to D-cache exception (enabled mpu address area)  
//	ver. 0.50
//		- expand tx buffer to 160 bytes
//	ver. 0.51
//		-	SPI DMA package changed from 20 bytes to 18 bytes
//	ver. 0.52
//		-	SPI DMA fixed
//	ver. 0.53
//		-	debugged SAI exchange 128 bits per sample (32 bits per channel)
//	ver. 0.54
//		- added test sine 882Hz
//	ver. 0.55
//		- added shor audio
//		- added double libruary QSPI MemMap need debug QSPI: HardFault in stm32h7xx_it.c
//	ver. 0.61
//		-	debugged QSPI MemMap
//		- added 2 audio tracks to QSPI and routed to SAI outputs
//	ver. 0.62
//		-	optimized libs
//	ver. 0.63
//		-	added text
//	ver. 0.67
//		- fixed QSPI reading bug where data was shifted by 2 bytes. sCommand.DummyCycles = 6;
//		- added rekordbox.h
//	ver. 0.69
//		-	bug fixed: path_ANLZ expanded to 46 bytes, for final 0 
//	ver. 0.70
//		-	added static wf and hcue, memory markers
//	ver. 0.72
//		- added hcue icons
//		-	added hcue icons and mem markers on dyn.wf
//	ver. 0.73
//		- gui optimization
//	ver. 0.74
//		- added audio playback in deck A
//	ver. 0.75
//		- changed packet length to 8 bytes (7+CRC)
//	ver. 0.76
//		-	added debug jog cnt
//	ver. 0.77
//		-	added FIR in audio handler
//		-	SAI transmission has been switched to floating point data
//	ver. 0.78
//		-	added PLAY, CUE, JOG code
//	ver. 0.79
//		- bug fixed in debug mode
//	ver. 0.81
//		-	added SLIP, TEMPO, jog display code
//	ver. 0.82
//		-	minor fixes
//	ver. 0.83
//	-	added rev butt code
//	ver. 0.85
//	-	added pitch pot control deck A
//	ver. 0.87
//	- added jog ring
//	ver. 0.88
//	-	PRETRIM changed for disable DC in audio, when track stopped
//	-	optimize HAL_SAI_Transmit_IT
//	- bug fixed: PLAY LED sometimes did not on in play mode
//	-	added ShowTempo first
//	ver. 0.89
//	- added ShowBPM
//	ver. 0.90
//	- added loops
//	-	improved ShowBPM
//	ver. 0.92
//	- added DrawTempoRange func
//	-	added DrawLoopMode func 
//	ver. 0.93
//	- minor improvements
//	ver. 0.95
//	- optimizations
//	ver. 0.96
//	- spi eeprom added
//	ver. 0.97
//	-	added LOAD A, LOAD B, ENC buttons
//	ver. 0.98
//	-	added ShowQUANTIZE func
//	ver. 0.99
//	-	added ShowACUE func
//	-	added part code
//	ver. 1.01
//	-	added transmittion bpm to mixer assy
//	-	UART TX optimized
//	ver. 1.03
//	- uart mixer link up to 500000 baud
//	- uart debug up to 256000 baud
//	- uart PM up to 256000 baud
//	ver. 1.04
//	- jog ring colors added
//	-	encoder code added
//	ver. 1.06
//	-	encoder bug fixed
//	-	jog color const calibration
//	ver. 1.07
//	-	color cue changed
//	- batt icon added
//	- lcd brightness control added
//	ver. 1.08
//	- bug fixed
//	ver. 1.09
//	-	LTDC minor improvements
//	ver. 1.11
//	- SPI2 speed up to 2X
//	ver. 1.12
//	-	decka_handker, deckb_handker added
//	ver. 1.14
//	- optimize code audio buff and adress jumping
//	ver. 1.15
//	-	migrated to STM32H743XIH6
//	ver. 1.16
//	- StaticWFM shifted 1px to down
//	ver. 1.17
//	-	double variables for decks
//	ver. 1.20
//	- added double code for decks
//	-	deck B draw time added
//	ver. 1.21
//	- double dynamic waveform added
//	-	sdmmc divider 33
//	ver. 1.22
//	-	sdmmc divider 35 (33 - have error 2)
//	-	masterdeck added
//	ver. 1.23
//	-	improved ShowBPM, masterdeck algorithm
//	ver. 1.24
//	- USART1_IRQHandler MIXER HANDLER, timeout changed 100ms->20ms
//	ver. 1.25
//	- added 30 sec markers
//	- added waveform left posotion
//	ver. 1.26
//	- track name and artist name added
//	ver. 1.27
//	-	BROWSER GUI added
//	-	NAVIGATOR func. added
//	-	Key icon added
//	-	bmp background disabled
//	ver. 1.28
//	- font Font7W dynamic width added
//	ver. 1.29
//	-	phase bar sync added
//	- CUE+SHIFT combination fixed
//	ver. 1.30
//	-	the algorithm for searching the current bar has been changed
//	-	added code for determining the synchronization phase
//	ver. 1.31
//	- BEATGRID array from 1/150 frames migrated in ms 
//	- pitch band sensivity changed
//	ver. 1.32
//	- Bug fixed synchronization phase bar code
//	ver. 1.33
//	-	PADs leds control added
//	ver. 1.35
//	- 4 panel buttons added
//	-	TAG LIST, BROWSE INFO code uncommented
//	ver. 1.36
//	- noise button filter added
//	- MENU long press code added
//	-	UTILITY const func. added
//	ver. 1.37
//	-	MENU code bug fixed
//	ver. 1.39
//	- GUI INFO bug fixed
//	ver. 1.40
//	- GUI UTILITY improved
//	ver. 1.41
//	- GUI UTILITY improved
//	ver. 1.42
//	- XDJX.sct: LR_IROM1 and ER_IROM1 is changes size for H743	
//	- GUI animation code added
//	ver. 1.43
//	-	GUI improved
//	ver. 1.45
//	-	modify int_DRAW_TRANSPARENT_BAR, added alpha pallette in qspi
//	ver. 1.46
//	-	added realtime load parameter color jog
//	- added bar colors
//	ver. 1.47
//	- GUI
//	ver. 1.49
//	- GUI improved Browse, Taglist, Playlist
//	ver. 1.50
//	- improved GUI Utility 	
//	- RGB waveform color map is changed
//	- Track name bars is changed
//	ver. 1.51
//	-	static waveform wide is changed 203px => 202px
//	- improved DrawMinuteMarkers func.
//	ver. 1.53
//	- screenshot debug code added
//	- GUI improved
//	ver. 1.54
//	- RGB waveform color map is changed
//	- GUI improved
//	ver. 1.55
//	-	Track number in info mode added
//	ver. 1.57
//	-	Rekordbox logo added
//	ver. 1.58
//	-	Track number icon adden in INFO MODE
//	ver. 1.59
//	- reconfig FMC clk 67MHz => 135,5MHz   PeriphClkInitStruct.PLL2.PLL2R = 1;
//	-	Optimization level -O3
//	-	speed SDRAM test added
//	-	LL_FillBuffer is changed
//	ver. 1.61
//	-	Unicode, CP866 filename support added
//	ver. 1.62
//	-	Rekordbox database parser update up to ver. 0.44
//	-	Cyrillic Pioneer font added
//	ver. 1.64
//	-	Rekordbox database parser ver. 0.45, KEYSmatchtable bug fixed
//	ver. 1.65
//	- improved gui func.
//	ver. 1.67
//	- improved gui func.
//	-	FIRCoef is changed to Cut Frequency: 8.1KHz
//	ver. 1.69
//	- SLIP yellow cursor added
//	- minor GUI bugs fixed
//	ver. 1.71
//	- minor GUI bugs fixed
//	- TRACK INFO window has been changed
//	ver. 1.72
//	- PADS hadler added
//	ver. 1.73
//	-	pads_a.h, pads_b.h added
//	ver. 1.74
//	-	fatfs_operations.h added
//	-	optimizing open file commands in fatfs
//	ver. 1.75 
//	-	created a common LOAD_TRACK function to load the left and right decks
//	ver. 1.76
//	-	Rekordbox database parser update up to ver. 0.47: expanded to 1024 tracks, 2048 mentions and 40 playlists
//	ver. 1.78
//	-	change waveform buffer (created 5 buffers)
//	-	exit utilities using the Back button
//	ver. 1.81
//	-	Rekordbox database parser ver. 0.51, playlists>20 bug fixed
//	ver. 1.82
//	-	Rekordbox database parser ver. 0.53
//	- Added support for reading large audio files when the *.EXT file exceeded the WFORMDYNAMIC buffer size
//	ver. 1.83
//	-	WFORMDYNAMIC read scope from waveform rendering process is limited
//	-	The function for rendering static waveform samples has been changed.
//	ver. 1.85
//	-	added union memory
//	ver. 1.86
//	- Static waveforms 2-layers now
//	- find PWV5 pointer in *.EXT file
//	ver. 1.89
//	- added parcing PWV4
//	ver. 1.92
//	-	Rekordbox database parser ver. 0.55
//	-	static waveforms 2-layers improved
//	- adaptive code from Pioneer waveform changer utility	added
//	ver. 1.93
//	- minor GUI bugs fixed
//	ver. 1.94
//	- speaker on/off added in utility
//	ver. 1.97
//	- SEEK_AUDIOFRAME func. bug fixed
//	- JOG SEEK added
//	-	HOT CUEs call added
//
//
//
//////////////////////////////////////////////////////////////////////////////////////////////////////////////	
	
	
	
/* USER CODE END Header */
/* Includes ------------------------------------------------------------------*/
#include "main.h"
#include "dma.h"
#include "dma2d.h"
#include "fatfs.h"
#include "ltdc.h"
#include "quadspi.h"
#include "sai.h"
#include "sdmmc.h"
#include "spi.h"
#include "tim.h"
#include "usart.h"
#include "gpio.h"
#include "fmc.h"

/* USER CODE BEGIN Includes */
char FIRMWARE_VERSION[] = "1.97";	
#define DEBUG_UART_EN				//sending work status to uart

#include "stdio.h"
#include "stdint.h"

#include "global_variables.h"
#include "audio.h"
#include "CWX3970.h"
#include "qspi_const.h"
#include "gui.h"
#include "audio_handler.h"
#include "deck_transfer.h"
#include "rekordbox.h"
#include "spi_mem.h"
#include "screenshot.h"



/* USER CODE END Includes */


void SystemClock_Config(void);
void PeriphCommonClock_Config(void);
static void MPU_Config(void);
/* USER CODE BEGIN 0 */
void GET_SD_INFO(void);								//check used and free memory on sd card

/* USER CODE END 0 */

/**
  * @brief  The application entry point.
  * @retval int
  */
int main(void)
{
  /* MPU Configuration--------------------------------------------------------*/
  MPU_Config();
/* Enable the CPU Cache */

  /* Enable I-Cache---------------------------------------------------------*/
  SCB_EnableICache();

  /* Enable D-Cache---------------------------------------------------------*/
  SCB_EnableDCache();

  /* MCU Configuration--------------------------------------------------------*/

  /* Reset of all peripherals, Initializes the Flash interface and the Systick. */
  HAL_Init();

  /* Configure the system clock */
  SystemClock_Config();

/* Configure the peripherals common clocks */
  PeriphCommonClock_Config();

  /* Initialize all configured peripherals */
  MX_GPIO_Init();
  MX_DMA_Init();
  MX_DMA2D_Init();
  MX_FMC_Init();
  MX_LTDC_Init();
  MX_QUADSPI_Init();
  MX_SDMMC1_SD_Init();
  MX_SPI1_Init();
  MX_SPI2_Init();
  MX_TIM2_Init();
  MX_TIM3_Init();
  MX_TIM8_Init();
  MX_UART4_Init();
  MX_UART7_Init();
  MX_USART1_UART_Init();
  MX_SAI1_Init();
  MX_FATFS_Init();
  /* USER CODE BEGIN 2 */
	CSP_QUADSPI_Init();
	CSP_QSPI_EnableMemoryMappedMode();

	BSP_SD_Init();
	USART1->CR1 |= USART_CR1_RXNEIE_RXFNEIE; //interrupt ON for a RX enable	
	USART1->CR1 |= USART_CR1_PEIE;
	UART4->CR1 |= USART_CR1_RXNEIE_RXFNEIE;  //interrupt ON for a RX enable	
	UART4->CR1 |= USART_CR1_PEIE;
	UART7->CR1 |= USART_CR1_RXNEIE_RXFNEIE;  //interrupt ON for a RX enable	
	UART7->CR1 |= USART_CR1_PEIE;	
	
	HAL_TIM_PWM_Start(&htim8, TIM_CHANNEL_1);	

	HAL_SAI_Transmit_IT(&hsai_BlockA1, (uint8_t*)&deckout[dkA][0], 2);
	HAL_SAI_Transmit_IT(&hsai_BlockB1, (uint8_t*)&deckout[dkB][0], 2);

	BSP_LCD_Init();
	BSP_LCD_LayerDefaultInit(0, LCD_FRAME_BUFFER);
	BSP_LCD_LayerDefaultInit(1, LCD_FRAME_BUFFER_2);
	
	#if defined(DEBUG_UART_EN)	
	i = HAL_GetTick();
	for(a=0;a<8912896;a++)
		{
		sdram.pcm[0][0][0][a] = a%60105;	
		}
	for(a=0;a<8912896;a++)
		{
		if(sdram.pcm[0][0][0][a]!=(a%60105))
			{
			sprintf((char*)U_TX_DATA, "%03lu SDRAM error\n\r", i);	
			UART_TX(&huart4, U_TX_DATA, 17, 5);
			HAL_Delay(50);		
			}
		}
	sprintf((char*)U_TX_DATA, "SDRAM speed test: %01lu ms\n\r", HAL_GetTick() - i);	
	UART_TX(&huart4, U_TX_DATA, 28, 5);		
	#endif
	
	i = 0;
	
	#if defined(DEBUG_UART_EN)	
	sprintf((char*)U_TX_DATA, "All init\n\r");	
	UART_TX(&huart4, U_TX_DATA, 10, 5);
	#endif

	BSP_LCD_SetTransparency(0, 255);
	BSP_LCD_SetTransparency(1, 255);
	BSP_LCD_SelectLayer(1);
	BSP_LCD_Clear(LCD_COLOR_TRANSPARENT);
	BSP_LCD_SetBackColor(LCD_COLOR_BLACK);

	BSP_LCD_SelectLayer(0);
	BSP_LCD_Clear(LCD_COLOR_BLACK);	
	
	for(j=0;j<19;j++)		//extract eeprom data
		{		
		UT_SET[j] = RD_EEMEM(j);
		}	
		
	tempo_range[dkA] = UT_SET[4];		
	tempo_range[dkB] = UT_SET[4];	
	acceleration_UP = UT_SET[7];
	acceleration_DOWN = UT_SET[8];	
		
	for(j=0;j<8;j++)
		{
		deckTbuf[j][0] = 24+j;	
		deckTbuf[j][1] = 0x00;
		deckTbuf[j][2] = 0x00;
		deckTbuf[j][3] = 0x00;
		deckTbuf[j][4] = 135;	//play pos
		deckTbuf[j][5] = 85;	
		deckTbuf[j][6] = 85;
		deckTbuf[j][7] = 0xFF;
		deckTbuf[j][8] = 24+j;	
		deckTbuf[j][9] = 0x00;
		deckTbuf[j][10] = 0x00;
		deckTbuf[j][11] = 0x00;
		deckTbuf[j][12] = 135;	//play pos	
		deckTbuf[j][13] = 85;	
		deckTbuf[j][14] = 85;
		deckTbuf[j][15] = 0xFF;	
		}	
	deckTbuf[3][0]&= 0xEF;	
	deckTbuf[3][8]&= 0xEF;
	deckTbuf[5][0]&= 0xEF;	
	deckTbuf[5][8]&= 0xEF;

	if(UT_SET[11]<9)
		{
		jog_work_color[dkA] = jog_color[UT_SET[12]][UT_SET[11]];
		jog_work_color[dkB] = jog_color[UT_SET[12]][UT_SET[11]];	
		}					
	else
		{
		jog_work_color[dkA] = jog_color[UT_SET[12]][curr_trck_color[dkA]];	
		jog_work_color[dkB] = jog_color[UT_SET[12]][curr_trck_color[dkB]];	
		}
	SET_JOG_COLOR(dkA, jog_work_color[dkA]);	
	SET_JOG_COLOR(dkB, jog_work_color[dkB]);	
		
	HAL_GPIO_WritePin(LED_BROWSE_GPIO_Port, LED_BROWSE_Pin, GPIO_PIN_SET);
	HAL_GPIO_WritePin(GPIOH, LED_TAGLIST_Pin|LED_INFO_Pin|LED_MENU_Pin, GPIO_PIN_SET);		
		
	HAL_TIM_Base_Start_IT(&htim2);									//start deck transfer timer
	HAL_GPIO_WritePin(GPIOH, P8EN_Pin, GPIO_PIN_SET);	
	HAL_Delay(1300);						//need decrees delay in deck assy. spi dma not starting?
//	U_TX_DATA[0] = 0x94;			//setting headphones cue type (pre EQ or post EQ)
//	U_TX_DATA[1] = 0xA3;
//	U_TX_DATA[2] =  UT_SET[18];
//	UART_TX(&huart1, U_TX_DATA, 3, 5);		
//	HAL_Delay(200);	
//	U_TX_DATA[0] = 0x93;			//setting fader curve type
//	U_TX_DATA[1] = 0xB1;
//	U_TX_DATA[2] =  UT_SET[15];
//	UART_TX(&huart1, U_TX_DATA, 3, 5);		
//	HAL_Delay(200);	
//	U_TX_DATA[0] = 0x92;			//mixer EQ type
//	U_TX_DATA[1] = UT_SET[16];
//	U_TX_DATA[2] =  UT_SET[17];
//	UART_TX(&huart1, U_TX_DATA, 3, 5);	
//	HAL_Delay(200);
	TIM8->CCR1 = LCDPWM_MAP[UT_SET[13]];			//LCD
	HAL_GPIO_WritePin(BACKLIGHT_EN_GPIO_Port, BACKLIGHT_EN_Pin, GPIO_PIN_SET);	
	DrawLOGO();	
	HAL_TIM_Base_Start_IT(&htim3);		

	HAL_GPIO_WritePin(LED_BROWSE_GPIO_Port, LED_BROWSE_Pin, GPIO_PIN_RESET);
	HAL_GPIO_WritePin(GPIOH, LED_TAGLIST_Pin|LED_INFO_Pin|LED_MENU_Pin, GPIO_PIN_RESET);	

	res = f_mount(&FAT, "0", 1);
	if (res!=FR_OK)
		{		
		#if defined(DEBUG_UART_EN)		
		sprintf((char*)U_TX_DATA, "%01lu error\n\r", res);	
		UART_TX(&huart4, U_TX_DATA, 9, 5);		
		sprintf((char*)U_TX_DATA, "SD not mounted\n\r");	
		UART_TX(&huart4, U_TX_DATA, 16, 5);
		#endif	
		}
	else
		{
		#if defined(DEBUG_UART_EN)		
		sprintf((char*)U_TX_DATA, "Drive mounted\n\r");	
		UART_TX(&huart4, U_TX_DATA, 15, 5);	
		#endif	
		GET_SD_INFO();
						
//		res = f_open(&file[dkA], path_pic, FA_READ);
//		if (res != FR_OK)
//			{
//			#if defined(DEBUG_UART_EN)		
//			sprintf((char*)U_TX_DATA, "Picture not opened\n\r");	
//			UART_TX(&huart4, U_TX_DATA, 20, 5);	
//			#endif	
//			}		
//		else
//			{
//			#if defined(DEBUG_UART_EN)		
//			sprintf((char*)U_TX_DATA, "Picture file open\n\r", i);	
//			UART_TX(&huart4, U_TX_DATA, 19, 5);	
//			#endif		
//			HAL_Delay(500);
//			f_lseek(&file[dkA], 54);			
//			f_read(&file[dkA], fbuf, 223680, &nbytes);	
//							
//			for(i=0;i<111840;i++)	
//				{	
//				fbuf[i]|=0x8000;
//				}		
//			f_close(&file[dkA]);	
//			}	
		}
			
	TOTAL_TRACKS = DATABASE_PARSER();
	if(TOTAL_TRACKS==0xFFFE)
		{
		#if defined(DEBUG_UART_EN)		
		sprintf((char*)U_TX_DATA, "Rekordbox database not found!\n\r");	
		UART_TX(&huart4, U_TX_DATA, 31, 5);	
		#endif		
		SD_STATUS = SD_NEED_REPLACE;
		}
	else if(TOTAL_TRACKS==0xFFFF)
		{
		#if defined(DEBUG_UART_EN)		
		sprintf((char*)U_TX_DATA, "Rekordbox database has more than 1024 tracks.\n\r");	
		UART_TX(&huart4, U_TX_DATA, 46, 5);	
		#endif	
		SD_STATUS = SD_NEED_REPLACE;	
		}
	else if(TOTAL_TRACKS==0xFFF1)
		{
		#if defined(DEBUG_UART_EN)		
		sprintf((char*)U_TX_DATA, "Playlists structure error.\n\r");	
		UART_TX(&huart4, U_TX_DATA, 28, 5);	
		#endif	
		SD_STATUS = SD_NEED_REPLACE;	
		}	
	else if(TOTAL_TRACKS==0)
		{
		#if defined(DEBUG_UART_EN)		
		sprintf((char*)U_TX_DATA, "Rekordbox database dont't have a tracks.\n\r");	
		UART_TX(&huart4, U_TX_DATA, 42, 5);	
		#endif	
		SD_STATUS = SD_NEED_REPLACE;	
		}	
	else
		{
		#if defined(DEBUG_UART_EN)		
		sprintf((char*)U_TX_DATA, "Rekordbox database have a %03lu tracks\n\r", TOTAL_TRACKS);	
		UART_TX(&huart4, U_TX_DATA, 38, 5);	
		#endif
		SD_STATUS = SD_MOUNTED;	
		}		

	HAL_GPIO_WritePin(GPIOA, LED_LOAD1_Pin|LED_LOAD0_Pin|LED_ENC_Pin, GPIO_PIN_SET);	
				
	BSP_LCD_Clear(LCD_COLOR_BLACK);
	BSP_LCD_SelectLayer(0);	
	SwitchInformationLayer(WAVEFORM);		//Show browser	
	ShowTempo(dkA, potenciometr_tempo[dkA]);
	ShowTempo(dkB, potenciometr_tempo[dkB]);		
				
	DrawLoopMode(dkA, loop_lenght[dkA], loop_act_gui[dkA]);	
	DrawLoopMode(dkB, loop_lenght[dkB], loop_act_gui[dkB]);		
	DrawTempoRange(dkA, tempo_range[dkA]);
	DrawTempoRange(dkB, tempo_range[dkB]);
	if(UT_SET[ACUE]==8)
		{
		ShowACUE(2);	
		}
	else
		{
		ShowACUE(1);	
		}	
	DrawStaticWFM(dkA, 205);	//not loaded	
	DrawStaticWFM(dkB, 205);	//not loaded	
	DrawKey(dkA, 0, 0);	
	DrawKey(dkB, 0, 1);	
		
	j = 0;
				
	#if defined(DEBUG_UART_EN)	
	sprintf((char*)U_TX_DATA, "Main assy: ");	
	UART_TX(&huart4, U_TX_DATA, 11, 5);	
	UART_TX(&huart4, FIRMWARE_VERSION, 4, 5);
	sprintf((char*)U_TX_DATA, "\n\r");	
	UART_TX(&huart4, U_TX_DATA, 2, 5);
	sprintf((char*)U_TX_DATA, "Deck 1 UCOM: ");	
	UART_TX(&huart4, U_TX_DATA, 13, 5);
	sprintf((char*)U_TX_DATA, "%01lu.%02lu\n\r", (deckRbuf[4]&0x7F)/100, (deckRbuf[4]&0x7F)%100);
	UART_TX(&huart4, U_TX_DATA, 6, 5);
	sprintf((char*)U_TX_DATA, "Deck 2 UCOM: ");	
	UART_TX(&huart4, U_TX_DATA, 13, 5);
	sprintf((char*)U_TX_DATA, "%01lu.%02lu\n\r", (deckRbuf[12]&0x7F)/100, (deckRbuf[12]&0x7F)%100);
	UART_TX(&huart4, U_TX_DATA, 6, 5);	
	#endif
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

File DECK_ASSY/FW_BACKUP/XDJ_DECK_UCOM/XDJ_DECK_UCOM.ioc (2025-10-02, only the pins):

Mcu.UserName=STM32F446RETx
PA0-WKUP.Signal=ADCx_IN0
PA1.Signal=ADCx_IN1
PA10.Signal=S_TIM1_CH3
PA11.GPIO_Label=BUTTON_PREV
PA11.Signal=GPIO_Input
PA12.GPIO_Label=BUTTON_4L
PA12.Signal=GPIO_Input
PA13.GPIO_Label=BUTTON_SLIP
PA13.Signal=GPIO_Input
PA14.GPIO_Label=BUTTON_VINYL
PA14.Signal=GPIO_Input
PA15.GPIO_Label=LED_MT
PA15.Signal=GPIO_Output
PA2.GPIO_Label=LED_REV
PA2.Signal=GPIO_Output
PA3.GPIO_Label=LED_CUE
PA3.Signal=GPIO_Output
PA4.Signal=SPI1_NSS
PA5.Signal=SPI1_SCK
PA6.Signal=SPI1_MISO
PA7.Signal=SPI1_MOSI
PA8.Signal=S_TIM1_CH1
PA9.Signal=S_TIM1_CH2
PB0.GPIO_Label=BUTTON_JOG
PB0.Signal=GPIO_Input
PB1.GPIO_Label=LED_VINYL
PB1.Signal=GPIO_Output
PB10.GPIO_Label=not_used
PB10.Signal=SPI2_SCK
PB12.GPIO_Label=BUTTON_PAD_4
PB12.Signal=GPIO_Input
PB13.GPIO_Label=BUTTON_PAD_5
PB13.Signal=GPIO_Input
PB14.GPIO_Label=BUTTON_PAD_6
PB14.Signal=GPIO_Input
PB15.GPIO_Label=BUTTON_PAD_7
PB15.Signal=GPIO_Input
PB2.GPIO_Label=LED_SLIP
PB2.Signal=GPIO_Output
PB3.GPIO_Label=BUTTON_8L
PB3.Signal=GPIO_Input
PB4.GPIO_Label=LED_RELOOP
PB4.Signal=GPIO_Output
PB5.GPIO_Label=BUTTON_RELOOP
PB5.Signal=GPIO_Input
PB6.Signal=S_TIM4_CH1
PB7.Signal=S_TIM4_CH2
PB8.GPIO_Label=LED_8L
PB8.Signal=GPIO_Output
PB9.GPIO_Label=LED_4L
PB9.Signal=GPIO_Output
PC0.GPIO_Label=BUTTON_CUE
PC0.Signal=GPIO_Input
PC1.GPIO_Label=WS2812B
PC1.Signal=SPI2_MOSI
PC10.GPIO_Label=SCK
PC10.Signal=SPI3_SCK
PC11.GPIO_Label=LAT
PC11.Signal=GPIO_Output
PC12.GPIO_Label=SI
PC12.Signal=SPI3_MOSI
PC13.GPIO_Label=BUTTON_PAD_1
PC13.Signal=GPIO_Input
PC14-OSC32_IN.GPIO_Label=BUTTON_PAD_0
PC14-OSC32_IN.Signal=GPIO_Input
PC15-OSC32_OUT.GPIO_Label=BUTTON_REV
PC15-OSC32_OUT.Signal=GPIO_Input
PC2.GPIO_Label=BUTTON_PLAY
PC2.Signal=GPIO_Input
PC3.GPIO_Label=LED_PLAY
PC3.Signal=GPIO_Output
PC4.GPIO_Label=BUTTON_PAD_2
PC4.Signal=GPIO_Input
PC5.GPIO_Label=BUTTON_PAD_3
PC5.Signal=GPIO_Input
PC6.GPIO_Label=TRANSFORMER_PWM
PC6.Signal=S_TIM3_CH1
PC7.GPIO_Label=BUTTON_MT
PC7.Signal=GPIO_Input
PC9.GPIO_Label=BUTTON_NEXT
PC9.Signal=GPIO_Input
PD2.GPIO_Label=BK
PD2.Signal=GPIO_Output
PH0-OSC_IN.Signal=RCC_OSC_IN
PH1-OSC_OUT.Signal=RCC_OSC_OUT

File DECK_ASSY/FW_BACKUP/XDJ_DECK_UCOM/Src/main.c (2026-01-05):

/**
  ******************************************************************************
  * @file           : main.c
  * @brief          : Main program body
  ******************************************************************************
  ** This notice applies to any and all portions of this file
  * that are not between comment pairs USER CODE BEGIN and
  * USER CODE END. Other portions of this file, whether 
  * inserted by the user or by software development tools
  * are owned by their respective copyright owners.
  *
  * COPYRIGHT(c) 2025 STMicroelectronics
  *
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
  ******************************************************************************
  */
/* Includes ------------------------------------------------------------------*/
#include "main.h"
#include "stm32f4xx_hal.h"
#include "adc.h"
#include "dma.h"
#include "spi.h"
#include "tim.h"
#include "gpio.h"


/* USER CODE BEGIN PV */
#include "VFL_data.h"



////////////////////////////////////////////////////////////////////////////////////////
//
//
//
//
//		Generated with: STM32CubeMX 4.25.1
//		Firmware Package Name and Version STM32Cube FW_F4 V1.21.0
//
//	
//
//
//
//
//	TIM1 LEDS PWM
//	TIM2 time counter for jog encoder
//	TIM3 transformer PWM
//	TIM4 JOG ENCODER TIMER
//	TIM5 1315*4Hz for VFD
//	SPI1 DMA for transfer between main assy and deck ucom
//	SPI2 DMA for PADS RGB leds 
//	SPI3 DMA for VFD 
//	
//
//
//
////////////////////////////////////////////////////////////////////////////////////////
//
//
//
//	ver. 0.03
//		- added all gpio
//		- added sharp fade transformer pwm
//	ver. 0.11 
//		- added button and leds handler
//		- added difine separated code for DECK_1 and DECK_2
//		-	added spi pads function
//	ver. 0.12 
//		-	changed starting delays
//	ver. 0.15
//		-	regenerated code		
//		-	add SPI DMA RX, TX buffer
//	ver. 0.16
//		- fix spi bug, change gpio speed to low 
//	ver. 0.17
//		- added button and leds first handler in spi irq
//	ver. 0.19
//		-	improved SPI transfer
//	ver. 0.20
//		-	SPI transfer fixed
//	ver. 0.21
//		- changed packet length to 8 bytes (7+CRC)
//	ver. 0.23
//		- added cue on vfd
//		- added slip mode on vfd
//	ver. 0.25
//		-	regenerated code
//		-	added TIM2
//	ver. 0.26
//		-	improved jog cnt
//	ver. 0.27
//		- fixed bug, data offsets on 2 deck due to packet reduction by 16 bytes
//	ver. 0.29
//		- slip mode round clear fixed
//		- adc pitch gysteresis added 
//	ver. 0.31
//		- PWM ring have been changed
//	ver. 0.34
//		- load animation added
//		- power animation added
//		- spi transfer up to 2X
//	ver. 0.36
//		- improved jog encoder code
//	ver. 0.39
//		-	The WH2812B data transfer lib has been modified due to the SPI frequency not being suitable for 4-bit data transfer. The buffer has been changed from 100=>75 bytes. 4=>3 bit data transfer.
//	ver. 0.41
//		-	draw_cue_sector (prev_cue_sect<86) bug fixed
//		- startup pads color have been changed
//		- pitch ADC (pot_convcd, POTCL, POTCH, POTxCD1, POTxCD2) have been changed
//
//
//
//
//
//
//
//
//
//
//
////////////////////////////////////////////////////////////////////////////////////////

///////DECK CONFIGURATION//////

#define DECK_1							//cooment this line, when deck 2 used

//#ifdef DECK_1

//#endif

//#ifndef DECK_1


//#endif	

#include "global_variables.h"
#include "CRC.h"
extern DMA_HandleTypeDef hdma_spi1_tx;

uint8_t FIRMWARE_VERSION = 41;			//127 max!

/* USER CODE END PV */

void SystemClock_Config(void);

/* USER CODE BEGIN PFP */
#include "VFL_GUI.h"
void COLOR_SET(uint32_t color, uint8_t LD);												
												
												
/* USER CODE END PFP */

/**
  * @brief  The application entry point.
  *
  * @retval None
  */
int main(void)
{
  /* MCU Configuration----------------------------------------------------------*/

  /* Reset of all peripherals, Initializes the Flash interface and the Systick. */
  HAL_Init();

  /* Configure the system clock */
  SystemClock_Config();

  /* Initialize all configured peripherals */
  MX_GPIO_Init();
  MX_DMA_Init();
  MX_SPI1_Init();
  MX_TIM1_Init();
  MX_ADC1_Init();
  MX_ADC2_Init();
  MX_ADC3_Init();
  MX_SPI2_Init();
  MX_SPI3_Init();
  MX_TIM3_Init();
  MX_TIM4_Init();
  MX_TIM5_Init();
  MX_TIM2_Init();
  /* USER CODE BEGIN 2 */
	HAL_TIM_Base_Start_IT(&htim2);				//ENCODER TIME
	HAL_TIM_Encoder_Start_IT(&htim4, TIM_CHANNEL_ALL);				//ENCODER
	
	
	#ifdef DECK_1
	deckTbuf[4] = FIRMWARE_VERSION;
	#endif

	#ifndef DECK_1
	deckTbuf[12] = FIRMWARE_VERSION;
	#endif
	
	
	HAL_TIM_Base_Start_IT(&htim5);
	HAL_TIM_PWM_Start(&htim3, TIM_CHANNEL_1);			//transformer pwm
	TIM1->CCR1 = 0;
	TIM1->CCR2 = 0;
	TIM1->CCR3 = 0;
	HAL_TIM_PWM_Start(&htim1, TIM_CHANNEL_1);			//leds pwm	
	HAL_TIM_PWM_Start(&htim1, TIM_CHANNEL_2);			//leds pwm
	HAL_TIM_PWM_Start(&htim1, TIM_CHANNEL_3);			//leds pwm

	HAL_Delay(1500);
	for(i=0;i<transformer_pwm;i++)			//soft start pwm
		{
		TIM3->CCR1 = i;
		HAL_Delay(25);	
		}
	TIM3->CCR1 = transformer_pwm;
	HAL_Delay(1000);
		
	HAL_SPI_TransmitReceive_DMA(&hspi1, deckTbuf, deckRbuf, 16);

	HAL_Delay(300);				
	COLOR_SET(0xFF780030, 0);
	COLOR_SET(0xFF780030, 1);
	COLOR_SET(0xFF780030, 2);
	COLOR_SET(0xFF780030, 3);
	COLOR_SET(0xFF780030, 4);
	COLOR_SET(0xFF780030, 5);
	COLOR_SET(0xFF780030, 6);
	COLOR_SET(0xFF780030, 7);		
	HAL_SPI_Transmit_DMA(&hspi2, PAD_BUF, 75);		
		
	HAL_GPIO_WritePin(GPIOC, LED_PLAY_Pin, GPIO_PIN_SET);
  HAL_GPIO_WritePin(GPIOA, LED_REV_Pin|LED_CUE_Pin|LED_MT_Pin, GPIO_PIN_SET);
  HAL_GPIO_WritePin(GPIOB, LED_VINYL_Pin|LED_SLIP_Pin|LED_RELOOP_Pin|LED_8L_Pin 
                          |LED_4L_Pin, GPIO_PIN_SET);	
		
	VFL_DATA[0]|=BITON[4];				//vinyl label ON
	VFL_DATA[0]|=BITON[6];				//S ring
		
	TIM1->CCR1 = 255;
	TIM1->CCR2 = 255;
	TIM1->CCR3 = 255;	
		
		
  /* USER CODE END 2 */

  /* Infinite loop */
  /* USER CODE BEGIN WHILE */
  while (1)
  {
	if(need_update_pads==2)
		{		
		HAL_SPI_Transmit_DMA(&hspi2, PAD_BUF, 75);		
		need_update_pads = 0;
		}
		
	if(animation_enable==1)			//load animation
		{
		draw_load_animation(step_animation);	
		if(step_animation==0)
			{			
			draw_cue_sector(85);	
			prev_pl_sect = 0xFF;	
			prev_cue_sect = 0xFF;	
			prev_slip_sect = 0xFF;	
			HAL_Delay(200);		//stay on first step - empty circle	
			}
		HAL_Delay(9);
		step_animation++;
		if(step_animation==69)
			{
			HAL_Delay(400);	
			animation_enable = 0;
			step_animation = 0;	
			}	
		}		
	else if(animation_enable==3)
		{
		draw_power_animation(step_animation);	
		if(step_animation==0)
			{			
			draw_cue_sector(85);	
			prev_pl_sect = 0xFF;	
			prev_cue_sect = 0xFF;	
			prev_slip_sect = 0xFF;	
			HAL_Delay(100);		//stay on first step - empty circle	
			}
		HAL_Delay(9);
		step_animation++;
		if(step_animation==271)
			{
			HAL_Delay(50);	
			animation_enable = 0;
			step_animation = 0;	
			}	
		}				
		
  /* USER CODE END WHILE */

  /* USER CODE BEGIN 3 */

  }
  /* USER CODE END 3 */

}

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
/* USER CODE BEGIN 4 */
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

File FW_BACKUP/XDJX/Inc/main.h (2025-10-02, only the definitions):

#define BT_INFO_Pin GPIO_PIN_6
#define BT_INFO_GPIO_Port GPIOI
#define BT_TAGLIST_Pin GPIO_PIN_4
#define BT_TAGLIST_GPIO_Port GPIOI
#define SD_DETECT_Pin GPIO_PIN_5
#define SD_DETECT_GPIO_Port GPIOD
#define BT_MENU_Pin GPIO_PIN_7
#define BT_MENU_GPIO_Port GPIOI
#define AMP_EN_Pin GPIO_PIN_2
#define AMP_EN_GPIO_Port GPIOE
#define BT_SHIFT_Pin GPIO_PIN_9
#define BT_SHIFT_GPIO_Port GPIOB
#define BT_TAG_Pin GPIO_PIN_2
#define BT_TAG_GPIO_Port GPIOH
#define LED_LOAD1_Pin GPIO_PIN_2
#define LED_LOAD1_GPIO_Port GPIOA
#define LED_LOAD0_Pin GPIO_PIN_1
#define LED_LOAD0_GPIO_Port GPIOA
#define BT_BACK_Pin GPIO_PIN_3
#define BT_BACK_GPIO_Port GPIOH
#define BACKLIGHT_EN_Pin GPIO_PIN_15
#define BACKLIGHT_EN_GPIO_Port GPIOI
#define LED_MENU_Pin GPIO_PIN_10
#define LED_MENU_GPIO_Port GPIOH
#define BT_ENC_Pin GPIO_PIN_2
#define BT_ENC_GPIO_Port GPIOB
#define LED_INFO_Pin GPIO_PIN_9
#define LED_INFO_GPIO_Port GPIOH
#define BT_LOAD1_Pin GPIO_PIN_1
#define BT_LOAD1_GPIO_Port GPIOB
#define P8EN_Pin GPIO_PIN_8
#define P8EN_GPIO_Port GPIOH
#define BT_BROWSE_Pin GPIO_PIN_12
#define BT_BROWSE_GPIO_Port GPIOB
#define LED_ENC_Pin GPIO_PIN_3
#define LED_ENC_GPIO_Port GPIOA
#define SPI1_NSS_Pin GPIO_PIN_4
#define SPI1_NSS_GPIO_Port GPIOA
#define BT_LOAD0_Pin GPIO_PIN_0
#define BT_LOAD0_GPIO_Port GPIOB
#define LED_TAGLIST_Pin GPIO_PIN_7
#define LED_TAGLIST_GPIO_Port GPIOH
#define LED_BROWSE_Pin GPIO_PIN_13
#define LED_BROWSE_GPIO_Port GPIOB

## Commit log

2025-03-18 Mixer assy
    [Leveler.FCStd, Leveler.stl, Mixer_assy_cut_all.dxf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]
2025-11-24 Create PINS sockets.png
2025-11-24 Panel Assy pcb
    [PANEL ASSY-B_Cu.gbr, PANEL ASSY-B_Mask.gbr, PANEL ASSY-B_SilkS.gbr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]
2025-11-24 PADS pcb
    [PADS-B_Cu.gbr, PADS-B_Mask.gbr, PADS-B_SilkS.gbr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]

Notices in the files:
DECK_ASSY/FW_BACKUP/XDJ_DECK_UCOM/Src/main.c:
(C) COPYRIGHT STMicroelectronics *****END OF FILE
